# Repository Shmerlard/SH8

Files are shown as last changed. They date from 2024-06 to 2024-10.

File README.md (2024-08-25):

# The shmerlard 16

hi, my name is elad and Im an electrical engineering student in Ben gurion university.
I designed a small 16bit cpu, with a mix of jdh8, src, msp430 and the Hack computer.
this is still a work in progress, but so far it works.

I used logisim for the logic design, draw.io for the diagrams.
in order to see the working cpu in logisim: you need to build version `3.9.0` from source [here](https://github.com/logisim-evolution/logisim-evolution/blob/main/docs/developers.md), then just open the `.circ` file.

## Specs

- a common 16-bit data and address bus
- a total of 128kB of usable memory
- 6 GP register (up to 14 available)
- modular design for easy troubleshooting
- port for outside connections

## Contents

1) [Registers](/Wiki/Modules/Register-File.md)
2) [Instruction Register](/Wiki/Modules/Instruction-Register.md)
3) [Program Counter](/Wiki/Modules/Program-Counter.md)
4) [ALU](/Wiki/Modules/ALU.md)
5) [Control Unit](/Wiki/Modules/Control-Unit.md)
6) [Memory Registers](/Wiki/Modules/Memory-Registers.md)
7) [Condition Logic](/Wiki/Modules/Condition-Logic.md)
8) [Shift Control](/Wiki/Modules/Shift-Control.md)
9) [Gallery](/Wiki/Gallery.md)

## Instruction set

```text
0x00:  NOP
0x01:  MOV  Ra/#, Rb       | Ra/# -> Rb
0x02:  ST   Ra/#, Rb/#     | Ra/# -> M[Rb]/
0x03:  PUSH Ra/#           | Ra/# -> @SP; SP--
0x04:  POP  Ra             | SP++; @SP -> Ra
0x05:  ADD  Ra/#, Rb       | Ra/# + Rb -> Rb
0x06:  ADDC Ra/#, Rb       | Ra/# + Rb + c -> Rb
0x07:  SUB  Ra/#, Rb       | Rb - Ra/# -> Rb
0x08:  CMP  Ra/#, Rb       | Rb - Ra/#
0x09:  SHR  Ra/#, Rb       | SHR Rb (Ra/# times) -> Rb
0x0A:  SHL
0x0B:  RRC  Ra/#, Rb       | RRC Rb (Ra/# times) -> Rb
0x0C:  RLC
0x0D:  AND  Ra/#, Rb       | Ra/# AND Rb -> Rb
0x0E:  OR   Ra/#, Rb       | Ra/# OR  Rb -> Rb
0x0F:  XOR  Ra/#, Rb       | Ra/# XOR Rb -> Rb
0x10:  NOT
0x11:  CALL DST            | PC -> @SP; DST -> PC; SP-- -> SP;
0x12:  RET
0x13:  JMP  DST            | DST -> PC
```

for more simulated instructions see: [Simulated Instructions](/Wiki/Simulated-Instructions.md)

## [Registers](/Wiki/Modules/Register-File.md)

```text
0: SP/REG0  : STACK pointer    
1: SR/REG1  : Status register
2: REG2     : GP Input
3: REG3     : GP Output
4: REG3     : GP
5: REG4     : GP
6: REG5     : GP
7: REG6     : GP
```

## [Memory](/Wiki/Modules/Memory-Registers.md)

the memory ranges from `0x0000` to `0xFFFF`.
the memory is mapped in the following way:

```text
0x0000 - 0x7FFF: GP ROM              (32KiB    ROM)
0x8000 - 0xBFFF: GP RAM              (16KiB    RAM) 
0xC000 - 0xCFFF: VRAM                (4KiB    RAM) #CURRENTLY NOT IN USE#
0xD000 - 0xFFFF: NOT IN USE          (12KiB UNUSED)
```

## [Instruction format](./Wiki/Modules/Instruction-Register.md)

The instruction register is a 16-bit register

```text
the format is XXXX-XUMM-SSSS-DDDD
X = the opcode of the instruction
U = Currently not in use
M = indicates the addressing mode
S = indicates the source register
D = indicates the destination register
```

(see [addressing modes](/Wiki/Modules/Instruction-Register.md#addressing-modes)) for more info

## Full diagram

for the full gallery go to [Gallery](Wiki/Gallery.md)

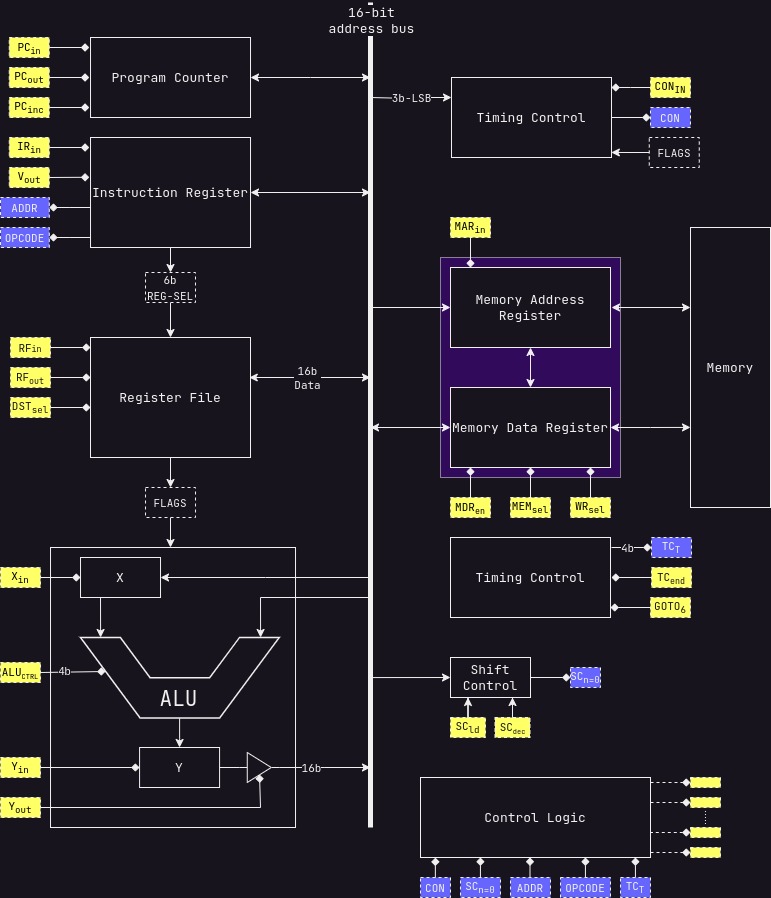
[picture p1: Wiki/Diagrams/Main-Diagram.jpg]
text


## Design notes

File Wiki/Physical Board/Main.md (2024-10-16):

## The Physical Board

I used KiCad to design the schematics and PCB's

The whole CPU is divided into the following modules and boards:

1. The Register File Module (16):\
    a. GP Registers (14)\
    b. Status Register (1)\
    c. Register File Manger (1)

2. Managing Modules (5):\
    a. the IR board (1)\
    b. the PC board (1)\
    c. the CON board (1)\
    d. the SC board (1)\
    e. the TC board (1)

3. ALU module (6):\
    a. X,Y register boards (2)\
    b. ALU Main(1)\
    c. ALU Shifter(1)\
    d. ALU Flags Calculator(1)\
    e. ALU Extra(1)

4. MEM and Control logic (3):\
    a. RAM and ROM board (1)
    b. MAR MDR (1))\
    c. Control board (1)

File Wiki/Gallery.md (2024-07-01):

# Gallery

## Main view

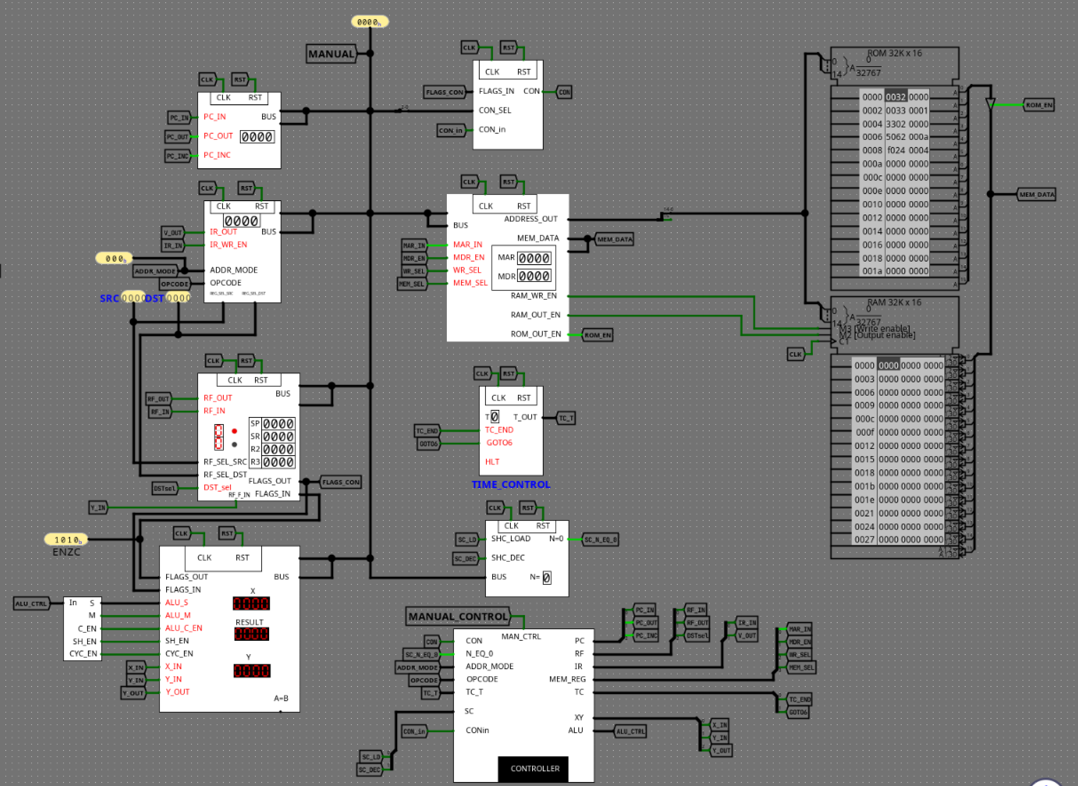
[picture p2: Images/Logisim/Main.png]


## The register file

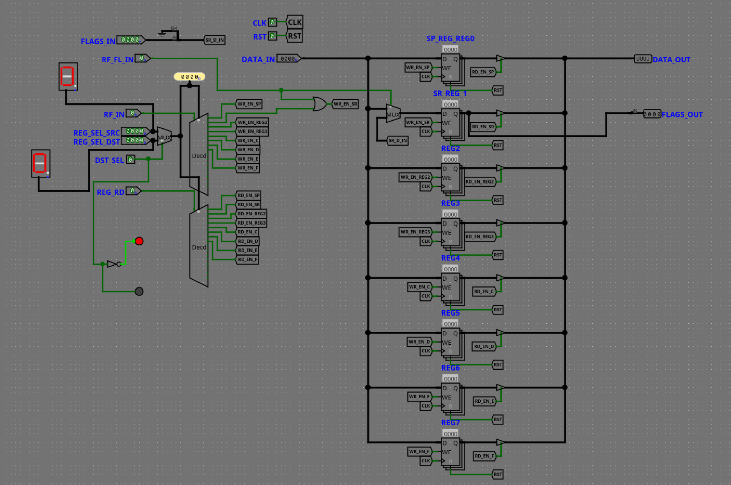
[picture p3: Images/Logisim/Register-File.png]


## The program counter

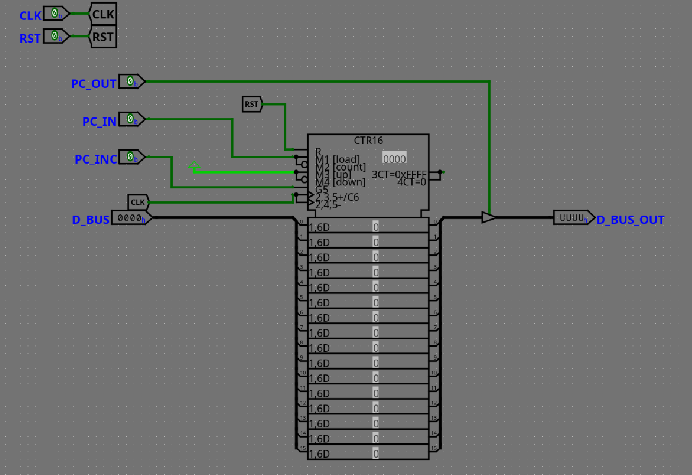
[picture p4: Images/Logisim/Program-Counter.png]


## The instruction register

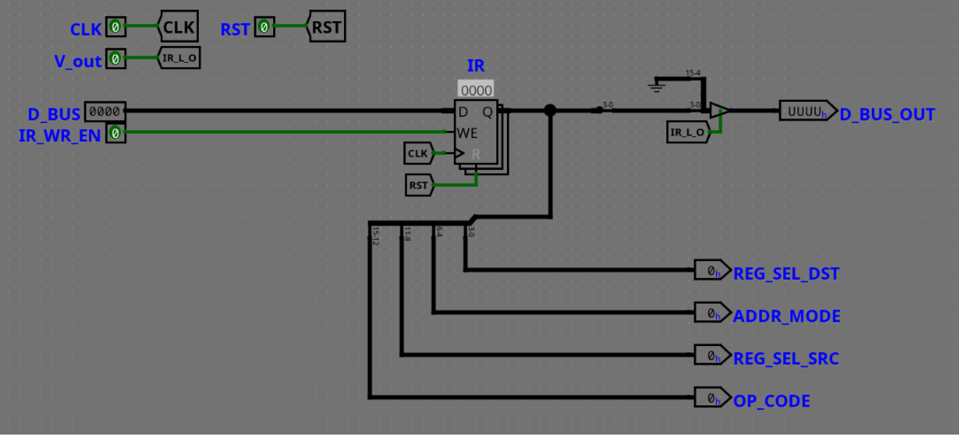
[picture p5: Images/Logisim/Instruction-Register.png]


## The ALU

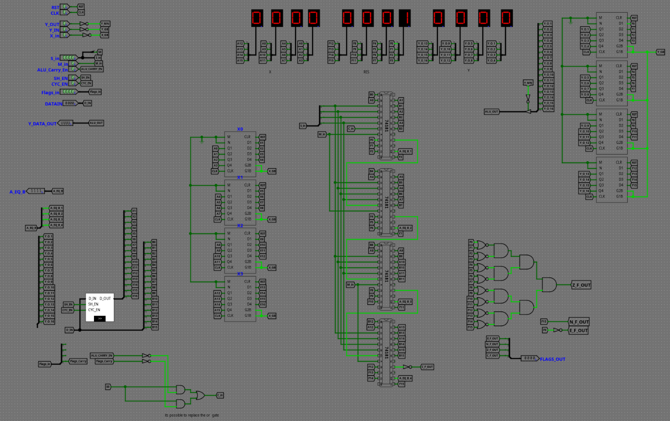
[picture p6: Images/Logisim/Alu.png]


## The conddition control

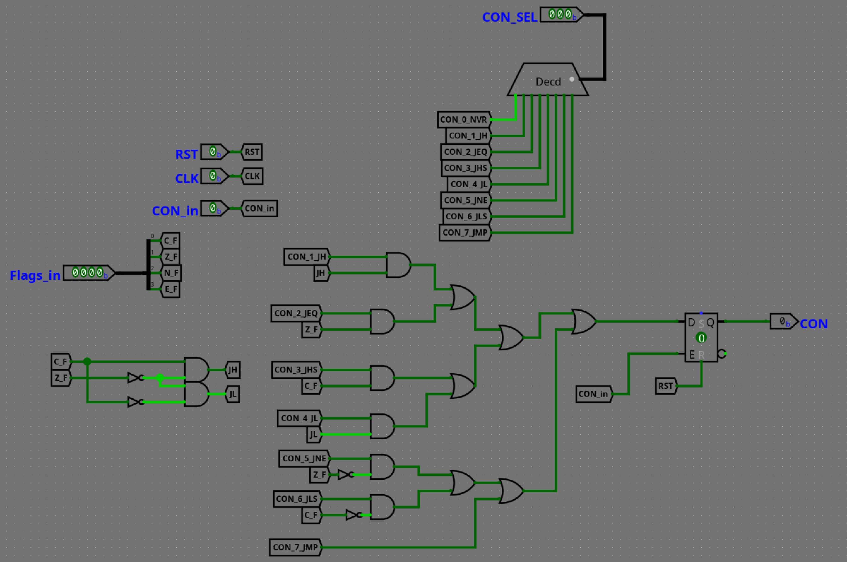
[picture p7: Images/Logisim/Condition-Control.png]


## Control logic

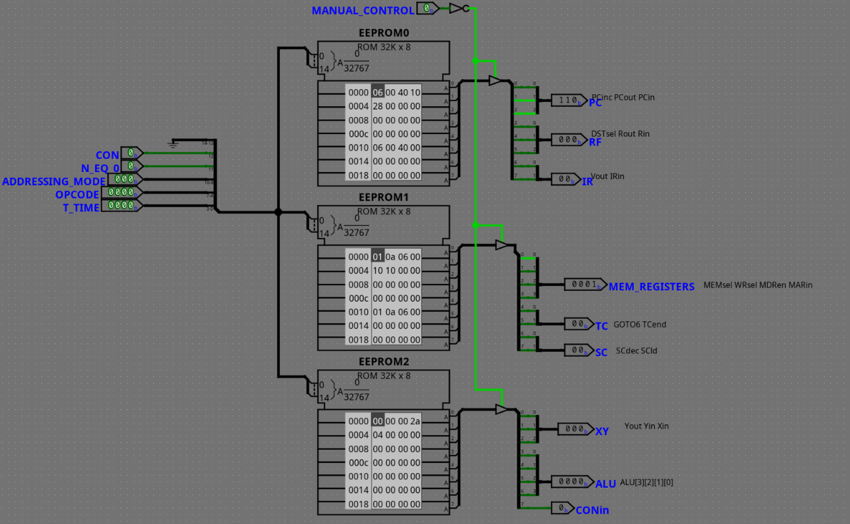
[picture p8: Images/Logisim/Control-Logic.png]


## Memory registers

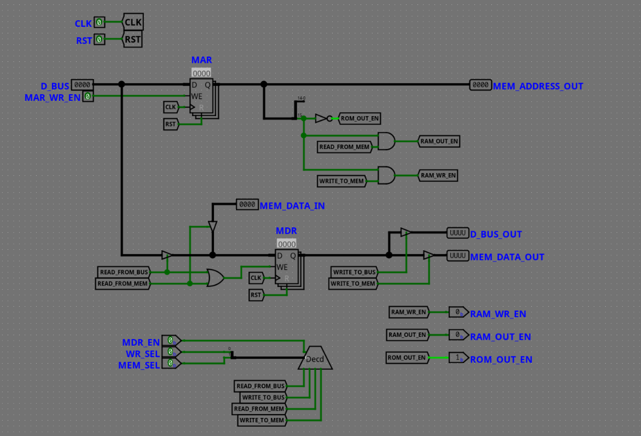
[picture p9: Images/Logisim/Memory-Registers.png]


## Shift control

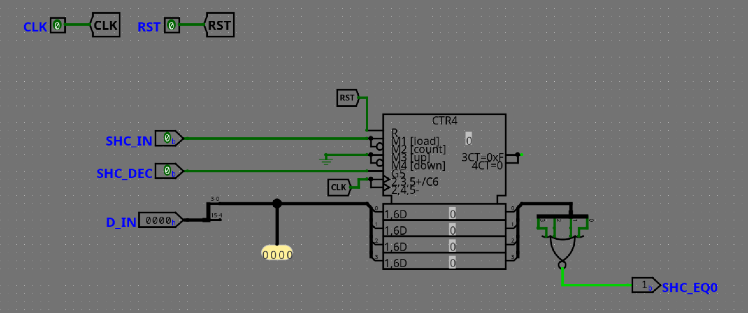
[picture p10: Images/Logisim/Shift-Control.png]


## Timing control

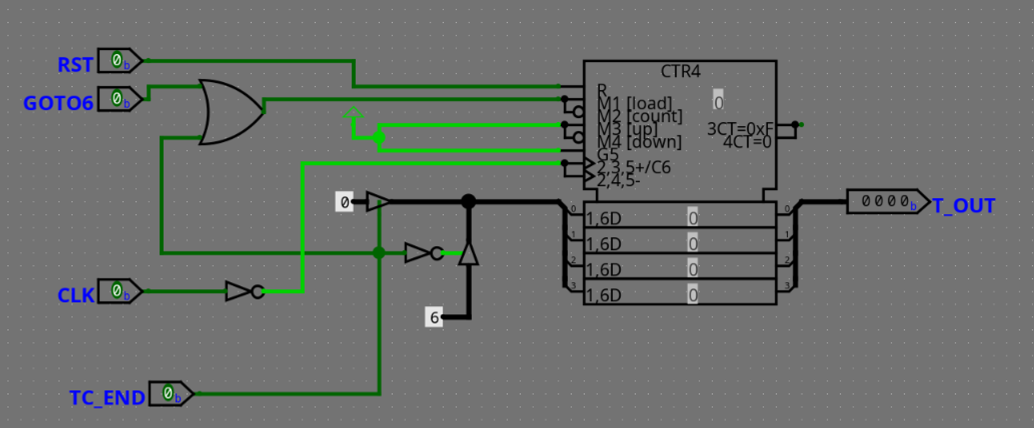
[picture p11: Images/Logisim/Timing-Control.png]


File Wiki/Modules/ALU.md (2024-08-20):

# The ALU

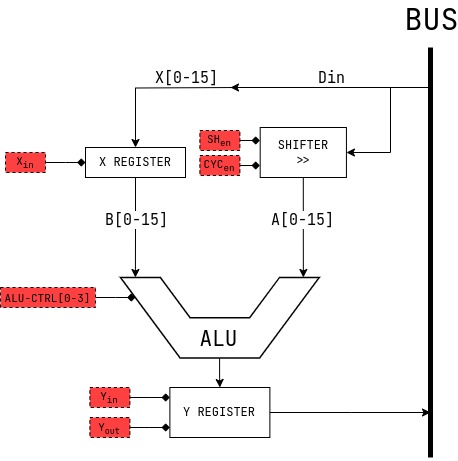
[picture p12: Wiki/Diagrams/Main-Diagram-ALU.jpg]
text

The ALU is the unit performing arithmetic and logical operations.
the ALU also contains 2 registers, X and Y. X is for the input, Y is for the output.
i used 4 74ls181 chips for the alu, but since the chip doesnt have a shifting mechanic another one is used.
in

since the 74ls181 chip has 6 inputs, and the shifter has another 2, we will need a full eeprom just for the mode of operation of the alu (even without `Xin Yin You`), but we don't need every possible output of the alu so first I've listed function that we are going to need.
and second I've listed the required control lines.
since we have less then 16 possible functions, we can represent them in 4 bits.
I've used to combinatorical analysis function in Logisim to find a matching circuit to "Translate" between the input that will be called `ALU_CTRL` and the control lines that will control the 74181 chips.
this circuit can be built in real life either by individuals logic gates or by an eeprom.

the alu has the folowing control lines:

```text
0x0: ADD
0x1: ADDC
0x2: SUB
0x3: AND
0x4: OR
0x5: XOR
0x6: NOT
0x7: Y=A
0x8: Y=X
0x9: SHR
0xA: RRC
0xB: SHL
0xC: RLC
0xD: DECA
0xE: INCA
0xF:
```

according to the [datasheet](/Datasheets/74181.pdf) we are going to need the following:

```text
0x0: ADD : F = A PLUS  B        : S = 0x9; M = 0; SH_EN = 0; CARRY_EN = 0
0x1: ADDC: F = A PLUS  B PLUS C : S = 0x9; M = 0; SH_EN = 0; CARRY_EN = 1
0x2: SUB : F = A MINUS B        : S = 0x6; M = 0; SH_EN = 0; CARRY_EN = 0
0x3: AND : F = A AND B          : S = 0xB; M = 1; SH_EN = 0;
0x4: OR  : F = A OR  B          : S = 0xE; M = 1; SH_EN = 0;
0x5: XOR : F = A XOR B          : S = 0x6; M = 1; SH_EN = 0;
0x6: NOT : F = NOT A            : S = 0x0; M = 1; SH_EN = 0;
0x7: Y=A : F = A                : S = 0xF; M = 1; SH_EN = 0;
0x8: Y=X : F = B                : S = 0xA; M = 1; SH_EN = 0;
0x9: SHR : Shift right A        : S = 0xF; M = 1; SH_EN = 1; CYC_EN = 0; LFT_SEL = 0
0xA: RRC : Shift right cyclic A : S = 0xF; M = 1; SH_EN = 1; CYC_EN = 1; LFT_SEL = 0
0xB: SHR : Shift left A         : S = 0xF; M = 1; SH_EN = 1; CYC_EN = 0; LFT_SEL = 1
0xC: RRC : Shift left cyclic A  : S = 0xF; M = 1; SH_EN = 1; CYC_EN = 1; LFT_SEL = 1
0xD: Y=DECA:                    : S = 0xF; M = 0; SH_EN = 0; CARRY_EN = 0
0xE: Y=INCA:                    : S = 0x0; M = 0; SH_EN = 0; CARRY_EN = 0 
```

## the shifting mechanic

since the 74181 chip doesnt include a shift right option, another circuit is made to do this, the circuit is connected between the bus and the A input of the alu and has 2 control lines, one is `SH_EN` for enabling shifting and the other is `CYC_EN` for enabling rotation, so if I want to shift left register 5 all I have to do is:
1) output register 5 to the bus
2) enable `SH_EN` and `Y=A` 
3) enable `Yin` for to save the resault
4) output Y register to `R5`

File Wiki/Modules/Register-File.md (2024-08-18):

# The register File

the register file contains the following registers:
```
0   : SP        | The stack pointer is a 16-bit register for
                  Holding the current address of the stack.

1   : SR REG    | Status register contains the following from LSB to MSB
                  0: (C) Carry flag
                  1: (Z) Zero flag
                  2: (N) Negative flag
                  3: (E) Even flag

2-3 : INPUT OUTPUT REGISTERS

4-15: GP Registers
```

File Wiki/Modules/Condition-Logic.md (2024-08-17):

# The condition logic

the condition logic control wheter the condition is satisfied or not:
the condition is a 3bit value.
the condition value is stored in the IR and the assembler will check which jump instruction is written and then insert the matching command.
for instance `JMP @R5` will be translated as `F517`, 
`F` is for `JMP` instruction, 
`5` is for `R5`, 
`1` is for `@Ra` addressing mode, 
and `7` is for always jump.
the instruction `JEQ @R5` will be translated to `F512`, everything will be the same exept that now we want to jump if equal.

```text
the condition format is XYZ
X - if 1: <
Y - if 1: =
Z - if 1: >
```

```text
0b000:     - dont jump              # a better solution need to be implemented
0b001: JH  - jump if higher
0b010: JEQ - jump if equal
0b011: JHS - jump if higher or same
0b100: JL  - jump if lower
0b101: JNE - jump if not equal
0b110: JLS - jump if lower or same
0b111: JMP - always jump
```

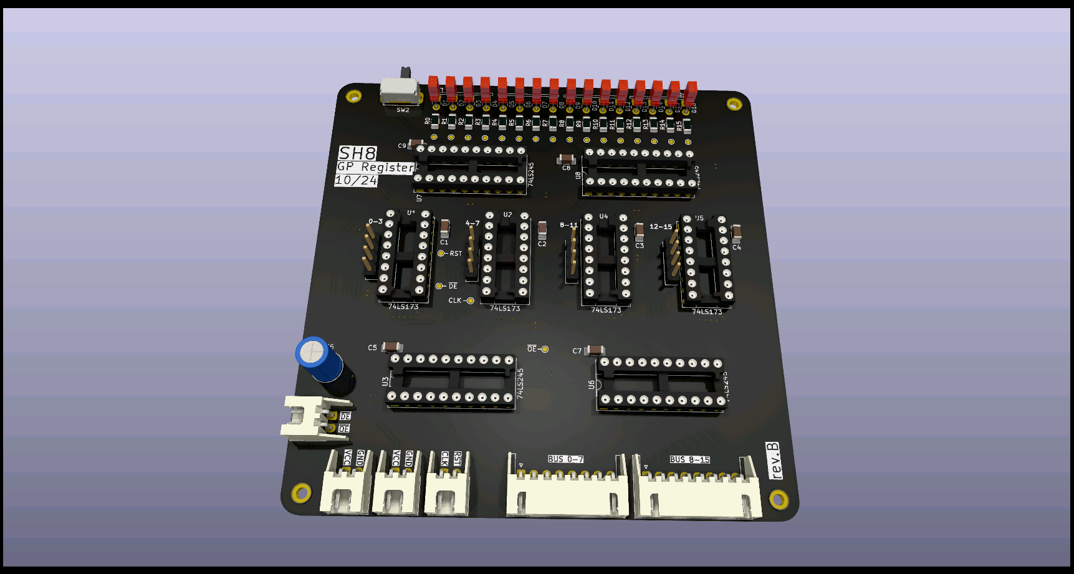
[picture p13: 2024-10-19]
Images/Kicad/GP_Register_rev_B.png

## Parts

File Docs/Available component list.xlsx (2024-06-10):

logisim? | verified? | Amount | 74XX | Description | Datasheet
 |  | 10 | 7400 | quad 2-input NAND gate | https://www.ti.com/lit/gpn/sn74ls00
 |  | 10 | 7402 | quad 2-input NOR gate | https://www.ti.com/lit/gpn/sn74ls02
 |  | 30 | 7404 | hex inverter gate | https://www.ti.com/lit/gpn/sn74ls04
 |  | 20 | 7408 | quad 2-input AND gate | https://www.ti.com/lit/gpn/sn74ls08
 |  | 20 | 7432 | quad 2-input OR gate | https://www.ti.com/lit/gpn/sn74ls32
 |  | 10 | 7486 | quad 2-input XOR gate | https://www.ti.com/lit/gpn/sn74ls86a
 |  | 5 | 74107 | dual J-K flip-flop, clear | https://www.ti.com/lit/gpn/sn74ls107a
 |  | 10 | 74138 | 3-to-8 line decoder/demultiplexer, inverting outputs | https://www.ti.com/lit/gpn/sn74ls138
 |  | 10 | 74139 | dual 2-to-4 line decoder/demultiplexer, inverting outputs | https://www.ti.com/lit/gpn/sn74ls139a
 |  | 20 | 74157 | quad 2-line to 1-line data selector/multiplexer, non-inverting outputs | https://www.ti.com/lit/gpn/sn74ls157
 |  | 10 | 74161 | synchronous presettable 4-bit binary counter, asynchronous clear | https://www.ti.com/lit/gpn/sn74ls161a
 |  | 15 | 74173 | quad D flip-flop, asynchronous clear | https://www.ti.com/lit/gpn/sn74ls173a
 |  | 3 | 74181 | 4-bit arithmetic logic unit and function generator | https://www.ti.com/lit/gpn/sn54ls181
 |  | 5 | 74189 | 64-bit RAM (16x4), 4 data inputs, 4 inverted data outputs | https://archive.org/details/bitsavers_tidataBookcomputerComponentsDataBook_16851665/page/n191
 |  | 2024-10-05 | 74244 | Octal Buffers and Line Drivers With 3-State Outputs | https://www.ti.com/lit/gpn/sn74ls244
 |  | 20 | 74245 | octal bus transceiver, non-inverting outputs | https://www.ti.com/lit/gpn/sn74ls245
 |  | 10 | 74273 | 8-bit register, asynchronous clear | https://www.ti.com/lit/gpn/sn74ls273
 |  | 20 | 74283 | 4-bit binary full adder (has carry in function) | https://www.ti.com/lit/gpn/sn74ls283
 |  | 10 | 74573 | Octal Transparent D-type latches with 3-states outputs | https://www.ti.com/lit/ds/symlink/sn74f573.pdf?ts=1718054679980
 |  | 10 | HM62256ALP10 | 8-bit High Speed CMOS Static RAM | https://pdf1.alldatasheet.com/datasheet-pdf/view/77267/HITACHI/HM62256ALP-10.html
 |  | 10 | NE555 | 555timer
 |  | 2 | CAT28C16 | 16 kb CMOS Parallel EEPROM | https://www.tme.com/Document/5c9d456a1546b7ee99bcccff240d871e/CAT28C16AX20.pdf

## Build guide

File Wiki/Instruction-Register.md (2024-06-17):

# The instruction register

## Instruction format

The instruction register is a 16-bit register

```text
the format is XXXX-XAAA-SSSS-DDDD
X = the opcode of the instruction
A = indicates the addressing mode 
S = indicates the source register
D = indicates the destination register
```

## Addressing modes

```text
000: Ra  Rb  | Reg - Reg Addressing            | Ra -> Rb
001: Ra  @Rb | Reg - Indirect Addressing       | R[Ra] -> M[Rb]
010: @Ra Rb  | Indirect - Reg Addressing       | M[Ra] -> Rb
011: @Rb @Rb | Indirect - Inderect Addressing  | M[Ra] -> M[Rb]
100: #N  Rb  | Immediate - Register Addressing | N -> Rb
101: #N  @Rb | Immediate - Indirect Addressing | N -> M[Rb]
110: N   Rb  | Direct - Register Addressing    | M[N] -> Rb
111: Ra  N   | Register - Direct Addressing    | Ra -> M[N]
```

### how fetching is obtained?

```text
T0) PC    -> MAR; PC++  | PCout, MARin, PCinc
T1) M[MA] -> MD         | MDRen, MEMsel, 
T2) MD    -> IR         | MDRen, IRin WRsel
```

### RTN

```text
(Rx)  Refers to the data inside register x
(M[Rx]) Refers to the data at the with the address Rx

(A ->  B) A is moving to B
(A &   B) A bitwise AND B
(A ||  B) A bitwise OR B
(NOT A  ) A bitwise NOT
(A XOR B) A bitwise XOR B
(A >>  B) A is shifted right bitwise B times (MSB of A becomes 0 each shift)
(A <<  B) A is shifted left bitwise B times (LSB of A becomes 0 each shift)
(A RR  B) A is rotated right B times
(A RL  B) A is rotated left B times

```

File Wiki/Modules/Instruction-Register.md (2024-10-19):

# The instruction register

The instruction register is a 16-bit register

## Instruction format

there is only one type of instruction formats
```text
the format is XXXX-XUMM-SSSS-DDDD
X = the opcode of the instruction
U = Currently not in use
M = indicates the addressing mode
S = indicates the source register
D = indicates the destination register
```

## Addressing modes

each addressing mode is represented by 2 bits for a total of 4 adressing modes for each type
there are 4 types of addressing modes

### Type 0 addressing mod
this type is used by `NOP`, `HLT`, `RET`
they dont have any arguements

### Type 1 addressing mod
this type is used by `MOV`,`AND`,`OR`,`XOR`,`SHR`,`RRC`, `ADD`,`ADDC`, `SUB` and `CMP`.

```text
0x0: Ra  Rb             | MOV Ra  Rb: Ra    -> Rb
0x1: @Ra Rb             | MOV @Ra Rb: M[Ra] -> Rb
0x2: #N  Rb             | MOV #N  Rb: #N    -> Rb
0x3: N   Rb             | MOV N   Rb: M[N]  -> Rb
```

### Type 2 addressing mods
this type is used by `ST`

```text
0x0: Ra  @Rb            | ST Ra @Rb: Ra -> M[Rb]
0x1: Ra  #N             | ST Ra #N: Ra -> M[#N]
0x2: #N  @Rb            | ST #N @Rb: #N -> M[M[Rb]]
0x3: Ra  N              | ST Ra N: Ra -> M[M[#N]]
```

### Type 3 addressing mods
this type is used by `PUSH`,`POP`,`CALL` and `JMP`

```text
0x0: Ra                 | POP Ra: @SP -> Ra
0x1: @Ra                | POP @Ra: @SP -> @Ra
0x2: #N                 | POP #N: @SP -> M[#N]
0x3: N                  | PUSH N: M[M[#N]] -> @SP
```
^note 1: in the examples above there are also `SP++` steps which I didnt include here.

### how fetching is obtained?

```text
T0) PC     -> MAR; PC++  | PCout, MARin, PCinc
T1) M[MAR] -> MDR        | MDRen, MEMsel, 
T2) MDR    -> IR         | MDRen, IRin WRsel
```

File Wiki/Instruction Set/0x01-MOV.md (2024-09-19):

# MOV

```text
0x0: Ra Rb: Ra -> Rb
    3) Ra -> Y              | RFout Yin Y=B
    4) Y  -> Rb             | RFin DSTsel Yout
    5) END                  | TCend

0x1: @Ra Rb: M[Ra] -> Rb
    3) Ra -> MAR            | RFout MARin
    4) M[MAR] -> MD         | MDRen MEMsel
    5) MDR -> Rb            | RFin DSTsel MDRen WRsel
    6) END                  | TCend

0x2: #N Rb: #N -> Rb
    3) PC -> MAR; PC++      | PCout  MARin PCinc
    4) M[MAR] -> MDR        | MEMsel MDRen
    5) MDR -> Rb            | RFin   RFin  DSTsel MDRen WRsel
    6) END                  | TCend

0x3: N @Rb: M[#N] Rb
    3) PC -> MAR; PC++      | PCout PCinc MARin
    4) M[MAR] -> MDR        | MDRen MEMsel
    5) MDR -> MAR           | MARin MDRen WRsel
    6) M[MAR] -> MDR        | MDRen MEMsel
    7) MDR -> Rb            | RFin DSTsel MDRen WRsel
    8) END                  | TCend

```

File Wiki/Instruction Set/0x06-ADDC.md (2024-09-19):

# ADDC

`ADDC` is a type 2 instruction that adds two numbers with carry

```text
0x0: Ra Rb: Ra + Rb + c -> Rb
    3) Ra -> X                  | RFout Xin
    4) X + Rb + c -> Y          | RFout DSTsel ADDC Yin
    5) Y -> Rb                  | RFin DSTsel Yout
    6) END                      | TCend

0x1: @Ra Rb: M[Ra] + Rb + c -> Rb
    3) Ra -> MAR                | RFout MARin
    4) Rb -> X; M[MAR] -> MDR   | RFout DSTsel Xin MDRen MEMsel
    5) X + MDR + c -> Y         | ADDC Yin MDRen WRsel
    6) Y -> Rb                  | RFin DSTsel Yout
    7) END                      | TCend

0x2: #N Rb: #N + Rb + c -> Rb
    3) PC -> MAR; PC++          | PCout PCinc MARin
    4) Rb -> X  ; M[MAR] -> MDR | RFout DSTsel Xin MDRen MEMsel
    5) MDR + X + c -> Y         | ADDC Yin MDRen WRsel
    6) Y -> Rb                  | Yout RFin DSTsel
    7) END                      | TCend

0x3: N Rb:
    3) 
```

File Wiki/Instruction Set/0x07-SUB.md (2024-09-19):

# SUB

```text
0x0: Ra Rb: Rb - Ra -> Rb
    3) Ra -> X                  | RFout Xin
    4) Rb - X -> Y              | RFout DSTsel SUB Yin
    5) Y -> Rb                  | RFin DSTsel Yout 
    6) END                      | TCend

0x1: @Ra Rb: Rb - M[Ra] -> Rb
    3) Ra -> MAR                | RFout MARin
    4) Rb -> X; M[MAR] -> MDR   | RFout DSTsel Xin MDRen MEMsel
    5) X - MDR -> Y             | SUB Yin MDRen WRsel 
    6) Y -> Rb                  | RFin DSTsel Yout
    7) END                      | TCend

0x2: #N Rb: Rb - #N -> Rb
    3) PC -> MAR; PC++          | PCout PCinc MARin
    4) M[MAR] -> MDR            | MDRen MEMsel
    5) MDR -> X                 | MDRen WRsel
    6) Rb - X -> Y              | RFout DSTsel SUB Yin
    7) Y -> Rb                  | RFin DSTsel Yout
    8) END                      | TCend

0x4: N Rb:
    3) 
```

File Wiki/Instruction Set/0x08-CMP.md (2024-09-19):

# CMP
Basically its like `SUB` only that `Rb` is not updated after

```text
0x0: Ra Rb: Rb - Ra
    3) Ra -> X                  | RFout Xin
    4) Rb - X -> Y              | RFout DSTsel SUB Yin
    5) END                      | TCend

0x1: @Ra Rb: Rb - M[Ra]
    3) Ra -> MAR                | RFout MARin
    4) Rb -> X; M[MAR] -> MDR   | RFout DSTsel Xin MDRen MEMsel
    5) X - MDR -> Y             | SUB Yin MDRen WRsel 
    6) END                      | TCend

0x2: #N Rb: Rb - #N
    3) PC -> MAR; PC++          | PCout PCinc MARin
    4) M[MAR] -> MDR            | MDRen MEMsel
    5) MDR -> X                 | MDRen WRsel
    6) Rb - X -> Y              | SUB Yin
    7) END                      | TCend

0x4: N Rb:
    3) 
```

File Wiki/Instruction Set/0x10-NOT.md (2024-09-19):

# NOT

```text
0x0: Ra Rb: ¬Ra -> Rb
    3) ¬Ra -> Y         | RFout NOT Yin
    4) Y -> Rb          | RFin DSTsel Yout
    5) END              | TCend

0x1: @Ra Rb: ¬M[Ra] -> Rb
    3) Ra -> MAR        | RFout MARin
    4) M[MAR] -> MDR    | MDRen MEMsel
    5) ¬MDR -> Y        | NOT Yin MDRen WRsel
    6) Y -> Rb          | RFin DSTsel Yout

0x2: #N Rb: ¬#N -> Rb
    3) PC -> MAR; PC++  | PCout PCinc MARin
    4) M[MAR] -> MDR    | MDRen MEMsel
    5) ¬MDR -> Y        | NOT Yin MDRen WRsel
    6) Y -> Rb          | RFin DSTsel Yout
    7) END              | TCend

0x3: N Rb:
    3)
```

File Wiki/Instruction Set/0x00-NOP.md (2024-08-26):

# NOP

```text
0x0: NOP
    3) TCend
```

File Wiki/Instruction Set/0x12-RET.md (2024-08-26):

# RET
the SP (reg#0) is selected to be `SRC` register

```text
0x0: RET: SP++; @SP -> PC
    3) SP++ -> Y                | RFout INCA Yin
    4) Y -> MAR : Y -> SP       | RFin Yout MARin
    5) M[MAR] -> MDR            | MDRen MEMsel
    6) MDR -> PC                | PCin MDRen WRsel
    7) END                      | TCend

0x1: NOP
    3) END                      | TCend

0x2: NOP
    3) END                      | TCend

0x3: NOP
    3) END                      | TCend
```

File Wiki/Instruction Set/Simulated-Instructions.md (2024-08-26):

# Simulated instructions

```text
HLT -> OR #0x0010 SR

Set Stack Pointer
SSP #N -> MOV #N SP

CLEAR E/N/Z/C bit
CLRC -> XOR #0x0001 SR
CLRZ -> XOR #0x0002 SR
CLRN -> XOR #0x0003 SR
CLRE -> XOR #0x0004 SR

SET E/N/Z/C bit
SETC -> OR #0x0001 SR
SETZ -> OR #0x0002 SR
SETN -> OR #0x0003 SR
SETE -> OR #0x0004 SR
```

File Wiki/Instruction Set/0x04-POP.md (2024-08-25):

# POP

in this command the SP (reg#0) is selected to be src reg

```text
0x0: Ra: SP++; @SP -> Ra
    3) SP++ -> Y                | RFout INCA Yin
    4) Y -> MAR : Y -> SP       | RFin Yout MARin
    5) M[MAR] -> MDR            | MDRen MEMsel
    6) MDR -> Ra                | RFin DSTsel MDRen WRsel
    7) END                      | TCend

0x1: @Ra: SP++; @SP -> @Ra
    3) SP++ -> Y                | RFout Yin INCA
    4) Y -> MAR: Y -> SP        | RFin Yout MARin
    5) M[MAR] -> MDR            | MDRen MEMsel
    6) Ra -> MAR                | RFout DSTsel MARin
    7) MDR -> M[MAR]            | MDRen WRsel MEMsel
    8) END                      | TCend

0x2: #N: SP++; @SP -> M[#N]
    3) SP++ -> Y                | RFout Yin INCA
    4) Y -> MAR: Y -> SP        | RFin Yout MARin
    5) M[MAR] -> MDR            | MDRen MEMsel
    6) MDR -> Y                 | Yin Y=A MDRen WRsel
    7) PC -> MAR; PC++          | PCout PCinc MARin
    8) M[MAR] -> MDR            | MDRen MEMsel
    9) MDR -> MAR               | MARin MDRen WRsel
   10) Y -> MDR                 | Yout MDRen
   11) MDR -> M[MAR]            | MDRen MEMsel WRsel
   12) END                      | TCend

0x3: N: SP++; @SP -> M[M[N]]
    3) END                      | TCend
```

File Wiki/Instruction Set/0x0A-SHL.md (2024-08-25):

# SHL

```text
0x0: Ra Rb: Rb (Shifted R[Ra]<3...0> times) -> Rb
    3) Ra -> n                                  | RFout SCld
    4) Rb -> Y                                  | RFout DSTsel Y=A Yin
    5) NOP                                      | NOP 
    6) (n != 0): Y SHL -> Y; n--                | SHL Yout Yin SCdec GOTO6
       (n  = 0): Y -> Rb                        | Yout RFin DSTsel
    7) END                                      | TCend

0x1: @Ra Rb:
    3) 

0x2: #N Rb: Rb (Shifted #N times) -> Rb
    3) PC -> MAR; PC++                          | PCout MARin PCinc
    4) M[MAR] -> MD; Rb -> Y                    | RFout DSTsel Y=A Yin MDRen MEMsel
    5) MD -> n                                  | MDRen WRsel SCld
    6) (n != 0): Y SHL -> Y; n--                | Yout Yin SHL SCdec GOTO6
       (n  = 0): Y -> Rb                        | RFin DSTsel Yout
    7) END                                      | TCend

0x3: N, @Rb:
    3) 
```

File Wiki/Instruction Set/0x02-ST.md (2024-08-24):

# ST

```text
0x0: Ra @Rb: Ra -> M[Rb]
    3) Rb -> MAR            | RFout DSTsel MARin
    4) Ra -> MDR            | RFout MDRen
    5) MDR -> M[MAR]        | MDRen WRsel MEMsel
    6) END                  | TCend

0x1: Ra #N: Ra -> M[#N]
    3) PC -> MAR; PC++      | PCout PCinc MARin
    4) M[MAR] -> MDR        | MDRen MEMsel
    5) MDR -> MAR           | MARin MDRen WRsel
    6) Ra -> MDR            | RFout MDRenk
    7) MDR -> M[MAR]        | MDRen WRsel MEMsel
    8) END                  | TCend

0x2: #N @Rb: #N -> M[Rb]
    3) PC -> MAR; PC++      | PCout PCinc MARin
    4) M[MAR] -> MDR        | MDRen MEMsel
    5) Rb -> MAR            | RFout DSTsel MARin
    6) MDR -> M[MAR]        | MDRen WRsel MEMsel
    7) END                  | TCend

0x3: Ra N: Ra -> M[M[#N]]
    3) PC -> MAR; PC++      | PCout PCinc MARin
    4) M[MAR] -> MDR        | MDRen MEMsel
    5) MDR -> MAR           | MARin MDRen WRsel
    6) M[MAR] -> MDR        | MDRen MEMsel
    7) MDR -> MAR           | MARin MDRen WRsel
    8) Ra -> MDR            | RFout MDRen
    9) MDR -> M[MAR]        | MDRen WRsel MEMsel
   10) END                  | TCend

```

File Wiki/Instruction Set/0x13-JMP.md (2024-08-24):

# JMP

note: this include every possible jump: JEQ/JNE/JL/JLS/JH/JHS/JMP
see more: [Condition Logic](../Modules/Condition-Logic.md)
the register A is set to be the source register by the assembler

```text
0x0: Ra: if(CON): Ra -> PC
    3) Val -> CON                   | Vout CONin
    4) (CON = 1): Ra -> PC          | RFout PCin
       (CON = 0): NOP               | NOP
    5) END                          | TCend

0x1: @Ra: if(CON): M[Ra] -> PC
    3) 

0x2: #N: if(CON): #N -> PC
    3) PC -> MAR; PC++              | PCout PCinc MARin
    4) M[MAR] -> MDR ;Val -> CON    | Vout CONin MDRen MEMsel
    5) (CON = 1): MDR -> PC         | MDRen WRsel PCin
       (CON = 0): NOP               |
    6) END                          | TCend

0x3: N: if(CON) M[N] -> PC ##MIGHT BE USELESS
    3)
```

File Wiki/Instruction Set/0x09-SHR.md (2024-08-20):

# SHR

```text
0x0: Ra Rb: Rb (Shifted R[Ra]<3...0> times) -> Rb
    3) Ra -> n                                  | RFout SCld
    4) Rb -> Y                                  | RFout DSTsel Y=A Yin
    5) NOP                                      | NOP 
    6) (n != 0 AND ALT = 0): Y SHR -> Y; n--    | SHR Yout Yin SCdec GOTO6
       (n != 0 AND ALT = 1): Y SHL -> Y; n--    | SHL Yout Yin SCdec GOTO6
       (n  = 0): Y -> Rb                        | Yout RFin DSTsel
    7) END                                      | TCend

0x1: @Ra Rb:
    3) 

0x2: #N Rb: Rb (Shifted #N times) -> Rb
    3) PC -> MAR; PC++                          | PCout MARin PCinc
    4) M[MAR] -> MD; Rb -> Y                    | RFout DSTsel Y=A Yin MDRen MEMsel
    5) MD -> n                                  | MDRen WRsel SCld
    6) (n != 0 AND ALT = 0): Y SHR -> Y; n--    | Yout Yin SHR SCdec GOTO6
       (n != 0 AND ALT = 1): Y SHL -> Y; n--    | Yout Yin SHL SCdec GOTO6
       (n  = 0): Y -> Rb                        | RFin DSTsel Yout
    7) END                                      | TCend

0x3: N, @Rb:
    3) 
```

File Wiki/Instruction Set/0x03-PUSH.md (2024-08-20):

# PUSH

the SP(reg#0) is set to be the dst reg by the compiler
`PUSH` has a type 3 addressing mode

## The microcode
```text
0x0: Ra: Ra -> @SP; SP--
    3) SP -> MAR; SP-- -> Y     | RFout DSTsel DECA Yin MARin
    4) Ra -> MDR                | RFout MDRen
    5) MDR -> M[MAR]; Y -> SP   | RFin DSTsel Yout MDRen MEMsel WRsel
    6) END                      | TCend

0x1: @Ra: M[Ra] -> @SP; SP--
    3) Ra -> MAR                | RFout MARin
    4) M[MAR] -> MDR            | MDRen MEMsel
    5) SP -> MAR; SP-- -> Y     | RFout DSTsel Yin DECA MARin
    6) MDR -> M[MAR]            | MDRen WRsel MEMsel
    7) END                      | TCend

0x2: #N: #N -> @SP; SP--
    3) PC -> MAR; PC++          | PCout PCinc MARin
    4) M[MAR] -> MD             | MDRen MEMsel
    5) SP -> MAR; SP-- -> Y     | RFout DSTsel MARin DECA Yin
    6) MDR -> M[MAR]; Y -> SP   | RFin DSTsel Yout MDRen MEMsel WRsel
    7) END                      | TCend

0x3: N: M[#N] -> @SP; SP--
    3) PC -> MAR; PC++          | PCout PCinc MARin
    4) M[MAR] -> MDR            | MDRen MEMsel
    5) MDR -> MAR               | MARin MDRen WRsel
    6) M[MAR] -> MDR            | MDRen MEMsel
    7) SP -> MAR; SP-- -> Y     | RFout DSTsel MARin DECA Yin
    8) MDR -> M[MAR]; Y -> SP   | RFin DSTsel You MDRen MEMsel WRsel
    9) END                      | TCend
```

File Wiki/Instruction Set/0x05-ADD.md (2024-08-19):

# ADD

```text
0x0: Ra Rb: Ra + Rb -> Rb
    3) Ra -> X                  | Xin RFout
    4) X + Rb -> Y              | RFout DSTsel ADD Yin
    5) Y -> Rb                  | RFin DSTsel Yout
    6) END                      | TCend

0x1: @Ra Rb: M[Ra] + Rb -> Rb
    3) Ra -> MAR                | RFout MARin
    4) Rb -> X; M[MAR] -> MDR   | RFout DSTsel Xin MDRen MEMsel
    5) X + MDR -> Y             | ADD Yin MDRen WRsel
    6) Y -> Rb                  | Yout RFin DSTsel
    7) END                      | TCend

0x2: #N Rb: #N + Rb -> Rb
    3) PC -> MAR; PC++          | PCout PCinc MARin
    4) Rb -> X  ; M[MAR] -> MDR | RFout DSTsel Xin MDRen MEMsel
    5) MDR + X -> Y             | ADD Yin MDRen WRsel
    6) Y -> Rb                  | Yout RFin DSTsel
    7) END                      | TCend

0x3: N Rb: M[#N] + Rb -> Rb
    3) END                      | TCend

```

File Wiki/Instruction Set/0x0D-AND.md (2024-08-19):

# AND

```text
0x0: Ra Rb: Ra AND Rb -> Rb
    3) Ra -> X                  | RFout Xin
    4) X AND Rb -> Y            | RFout DSTsel AND Yin  
    5) Y -> Rb                  | RFin DSTsel Yout
    6) END                      | TCend

0x1: @Ra Rb: M[Ra] AND Rb -> Rb
    3) Ra -> MAR                | RFout MARin
    4) Rb -> X; M[MAR] -> MDR   | RFout DSTsel Xin MDRen MEMsel
    5) X AND MDR -> Y           | Yin AND MDRen WRsel
    6) Y -> Rb                  | RFin DSTsel Yout
    7) END                      | TCend

0x2: #N Rb: #N AND Rb -> Rb
    3) PC -> MAR; PC++          | PCout PCinc MARin
    4) Rb -> X; M[MAR] -> MDR   | RFout DSTsel Xin MDRen MEMsel
    5) X AND MDR -> Y           | Yin AND MDRen WRsel
    6) Y -> Rb                  | RFin DSTsel Yout
    7) END                      | TCend

0x3: N Rb: M[#N] AND Rb -> Rb
    3) PC -> MAR PC++           | PCout PCinc MARin
    4) Rb -> X; M[MAR] -> MDR   | RFout DSTsel Xin MDRen MEMsel
    5) MDR -> MAR               | MARin MDRen WRsel
    6) M[MAR] -> MDR            | MDRen MEMsel
    7) MDR AND X -> Y           | Yin AND MDRen WRsel
    8) Y -> Rb                  | RFin DSTsel Yout
    9) END                      | TCend
```

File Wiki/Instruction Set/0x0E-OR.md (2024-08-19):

# OR

```text
0x0: Ra Rb: Ra OR Rb -> Rb
    3) Ra -> X                  | RFout Xin
    4) X OR Rb -> Y             | RFout DSTsel OR Yin  
    5) Y -> Rb                  | RFin DSTsel Yout
    6) END                      | TCend

0x1: @Ra Rb: M[Ra] OR Rb -> Rb
    3) Ra -> MAR                | RFout MARin
    4) Rb -> X; M[MAR] -> MDR   | RFout DSTsel Xin MDRen MEMsel
    5) X OR MDR -> Y            | Yin OR MDRen WRsel
    6) Y -> Rb                  | RFin DSTsel Yout
    7) END                      | TCend

0x2: #N Rb: #N OR Rb -> Rb
    3) PC -> MAR; PC++          | PCout PCinc MARin
    4) Rb -> X; M[MAR] -> MDR   | RFout DSTsel Xin MDRen MEMsel
    5) X OR MDR -> Y            | Yin OR MDRen WRsel
    6) Y -> Rb                  | RFin DSTsel Yout
    7) END                      | TCend

0x3: N Rb: M[#N] OR Rb -> Rb
    3) PC -> MAR PC++           | PCout PCinc MARin
    4) Rb -> X; M[MAR] -> MDR   | RFout DSTsel Xin MDRen MEMsel
    5) MDR -> MAR               | MARin MDRen WRsel
    6) M[MAR] -> MDR            | MDRen MEMsel
    7) MDR OR X -> Y            | Yin OR MDRen WRsel
    8) Y -> Rb                  | RFin DSTsel Yout
    9) END                      | TCend
```

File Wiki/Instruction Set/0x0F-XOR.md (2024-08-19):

# XOR

```text
0x0: Ra Rb: Ra XOR Rb -> Rb
    3) Ra -> X                  | RFout Xin
    4) X XOR Rb -> Y            | RFout DSTsel XOR Yin  
    5) Y -> Rb                  | RFin DSTsel Yout
    6) END                      | TCend

0x1: @Ra Rb: M[Ra] XOR Rb -> Rb
    3) Ra -> MAR                | RFout MARin
    4) Rb -> X; M[MAR] -> MDR   | RFout DSTsel Xin MDRen MEMsel
    5) X XOR MDR -> Y           | Yin XOR MDRen WRsel
    6) Y -> Rb                  | RFin DSTsel Yout
    7) END                      | TCend

0x2: #N Rb: #N XOR Rb -> Rb
    3) PC -> MAR; PC++          | PCout PCinc MARin
    4) Rb -> X; M[MAR] -> MDR   | RFout DSTsel Xin MDRen MEMsel
    5) X XOR MDR -> Y           | Yin XOR MDRen WRsel
    6) Y -> Rb                  | RFin DSTsel Yout
    7) END                      | TCend

0x3: N Rb: M[#N] XOR Rb -> Rb
    3) PC -> MAR PC++           | PCout PCinc MARin
    4) Rb -> X; M[MAR] -> MDR   | RFout DSTsel Xin MDRen MEMsel
    5) MDR -> MAR               | MARin MDRen WRsel
    6) M[MAR] -> MDR            | MDRen MEMsel
    7) MDR XOR X -> Y           | Yin XOR MDRen WRsel
    8) Y -> Rb                  | RFin DSTsel Yout
    9) END                      | TCend
```

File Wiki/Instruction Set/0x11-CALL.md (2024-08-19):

# CALL

the `SP` is set to be the source register and `Ra` is set to be the destination register

```text
0x0: Ra: PC -> @SP; Ra -> PC; SP-- -> SP;
    3) PC -> MDR                | PCout MDRen
    4) SP -> MAR; SP-- -> Y     | RFout Yin DECA MARin
    5) MDR -> M[MAR]; Y -> SP   | RFin Yout MDRen MEMsel WRsel
    6) Ra -> PC                 | RFout DSTsel PCin
    7) END                      | TCend

0x1: @Ra: 
    3)

0x2: #N: PC -> @SP; #N -> PC; SP-- -> SP;
    3) PC -> MAR; PC++          | PCout PCinc MARin
    4) M[MAR] -> MDR            | MDRen MEMsel
    5) MDR -> Y                 | Yin Y=A MDRen WRsel
    6) PC -> MDR                | PCout MDRen
    7) Y -> PC                  | Yout PCin
    8) SP -> MAR; SP-- -> Y     | RFout MARin DECA Yin
    9) MDR -> M[MAR]; Y -> SP   | RFin Yout MDRen MEMsel WRsel
   10) END                      | TCend

0x3: N:
    3)
```

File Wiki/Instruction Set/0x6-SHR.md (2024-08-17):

# SHR

```text
0x0: Ra Rb: Rb (Shifted R[Ra]<3...0> times) -> Rb
    3) Ra -> n                      | RFout SCld
    4) Rb -> Y                      | RFout DSTsel Y=A Yin
    5) NOP                          | 
    6) (n != 0): Y SHR -> Y; n--    | SHR Yout Yin SCdec GOTO6
       (n  = 0): Y -> Rb            | Yout RFin DSTsel
    7) TCEND                        | TCend

0x1: Ra @Rb:
    3) 

0x2: @Ra Rb:
    3) 

0x3: #N Rb: Rb (Shifted #N times) -> Rb
    3) PC -> MAR; PC++              | PCout MARin PCinc
    4) M[MAR] -> MD; Rb -> Y        | RFout DSTsel Y=A Yin MDRen WRsel MEMsel
    5) MD -> n                      | MDRen SCld
    6) (n != 0): Y SHR -> Y; n--    | Yout Yin SHR SCdec GOTO6
       (n  = 0): Y -> Rb            | RFin DSTsel Yout
    7) TCend                        | TCend

0x4: #N, @Rb:
    3) 

0x5: N, Rb:
    3) 

0x6: Ra, N:
    3) 

0x7: SPECIAL
```

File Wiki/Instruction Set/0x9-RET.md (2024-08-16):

# RET

&&& note: i should change source of INC from X to bus

in this command `SP` is set to be the `SRC` register
```text
0x0: SP++ ; @SP -> PC 
    3) SP -> X              | RFout Xin
    4) X++ -> Y             | INCX Yin
    5) Y  -> SP, Y -> MAR   | Yout RFin MARin
    6) M[MAR] -> MDR        | MDRen MEMsel WRsel
    7) MDR -> PC            | MDRen PCin
```

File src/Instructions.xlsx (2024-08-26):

INST | OPCODE | CATEGORY | TYPE | SRC_REG | DST_REG | NUM_ARGS
NOP | 0x00 | REGULAR | 0 |  |  | 0
MOV | 0x01 | REGULAR | 1 |  |  | 2
ST | 0x02 | REGULAR | 2 |  |  | 2
PUSH | 0x03 | REGULAR | 3 |  | @0 | 1
POP | 0x04 | REGULAR | 3 | @0 |  | 1
ADD | 0x05 | REGULAR | 1 |  |  | 2
ADDC | 0x06 | REGULAR | 1 |  |  | 2
SUB | 0x07 | REGULAR | 1 |  |  | 2
CMP | 0x08 | REGULAR | 1 |  |  | 2
SHR | 0x09 | REGULAR | 1 |  |  | 2
SHL | 0x0A | REGULAR | 1 |  |  | 2
RRC | 0x0B | REGULAR | 1 |  |  | 2
RLC | 0x0C | REGULAR | 1 |  |  | 2
AND | 0x0D | REGULAR | 1 |  |  | 2
OR | 0x0E | REGULAR | 1 |  |  | 2
XOR | 0x0F | REGULAR | 1 |  |  | 2
NOT | 0x10 | REGULAR | 1 |  |  | 1
CALL | 0x11 | REGULAR | 3 | @0 |  | 1
RET | 0x12 | REGULAR | 0 | @0 | @0 | 0
JMP | 0x13 | REGULAR | 3 |  | 7 | 1
HLT | 0x14 | REGULAR | 0 |  | 1 | 0
dw |  | SAVED_WORD |  |  |  | 1
.org |  | SAVED_WORD |  |  |  | 1
JH | 0x0F | REGULAR | 3 |  | 1 | 1
JEQ | 0x0F | REGULAR | 3 |  | 2 | 1
JHS | 0x0F | REGULAR | 3 |  | 3 | 1
JL | 0x0F | REGULAR | 3 |  | 4 | 1
JNE | 0x0F | REGULAR | 3 |  | 5 | 1
JLS | 0x0F | REGULAR | 3 |  | 6 | 1
HLT | 0x0E | SIMULATED | 1 | #0x0010 | 1 | 0

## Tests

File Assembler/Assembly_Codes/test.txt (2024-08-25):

v3.0 hex words addressed
0000: 0a04 0124 0a05 0004 0a06 0015 0a09 0016 0825 0958 8b00 000e 9b07 000e 0a04 0003
0010: 9000 0000 0000 0000 0000 0000 0000 0000 0000 0000 0000 0000 0000 0000 0000 0000
0020: 0000 0000 0000 0000 0000 0000 0000 0000 0000 0000 0000 0000 0000 0000 0000 0000
0030: 0000 0000 0000 0000 0000 0000 0000 0000 0000 0000 0000 0000 0000 0000 0000 0000
0040: 0000 0000 0000 0000 0000 0000 0000 0000 0000 0000 0000 0000 0000 0000 0000 0000
0050: 0000 0000 0000 0000 0000 0000 0000 0000 0000 0000 0000 0000 0000 0000 0000 0000
0060: 0000 0000 0000 0000 0000 0000 0000 0000 0000 0000 0000 0000 0000 0000 0000 0000
0070: 0000 0000 0000 0000 0000 0000 0000 0000 0000 0000 0000 0000 0000 0000 0000 0000
0080: 0000 0000 0000 0000 0000 0000 0000 0000 0000 0000 0000 0000 0000 0000 0000 0000
0090: 0000 0000 0000 0000 0000 0000 0000 0000 0000 0000 0000 0000 0000 0000 0000 0000
00a0: 0000 0000 0000 0000 0000 0000 0000 0000 0000 0000 0000 0000 0000 0000 0000 0000
00b0: 0000 0000 0000 0000 0000 0000 0000 0000 0000 0000 0000 0000 0000 0000 0000 0000
00c0: 0000 0000 0000 0000 0000 0000 0000 0000 0000 0000 0000 0000 0000 0000 0000 0000
00d0: 0000 0000 0000 0000 0000 0000 0000 0000 0000 0000 0000 0000 0000 0000 0000 0000
00e0: 0000 0000 0000 0000 0000 0000 0000 0000 0000 0000 0000 0000 0000 0000 0000 0000
00f0: 0000 0000 0000 0000 0000 0000 0000 0000 0000 0000 0000 0000 0000 0000 0000 0000
0100: 0000 0000 0000 0000 0000 0000 0000 0000 0000 0000 0000 0000 0000 0000 0000 0000
0110: 0000 0000 0000 0000 0000 0000 0000 0000 0000 0000 0000 0000 0000 0000 0000 0000
0120: 0000 0000 0000 0000 0000 0000 0000 0000 0000 0000 0000 0000 0000 0000 0000 0000
0130: 0000 0000 0000 0000 0000 0000 0000 0000 0000 0000 0000 0000 0000 0000 0000 0000
0140: 0000 0000 0000 0000 0000 0000 0000 0000 0000 0000 0000 0000 0000 0000 0000 0000
0150: 0000 0000 0000 0000 0000 0000 0000 0000 0000 0000 0000 0000 0000 0000 0000 0000
0160: 0000 0000 0000 0000 0000 0000 0000 0000 0000 0000 0000 0000 0000 0000 0000 0000
0170: 0000 0000 0000 0000 0000 0000 0000 0000 0000 0000 0000 0000 0000 0000 0000 0000
0180: 0000 0000 0000 0000 0000 0000 0000 0000 0000 0000 0000 0000 0000 0000 0000 0000
0190: 0000 0000 0000 0000 0000 0000 0000 0000 0000 0000 0000 0000 0000 0000 0000 0000
01a0: 0000 0000 0000 0000 0000 0000 0000 0000 0000 0000 0000 0000 0000 0000 0000 0000
01b0: 0000 0000 0000 0000 0000 0000 0000 0000 0000 0000 0000 0000 0000 0000 0000 0000
01c0: 0000 0000 0000 0000 0000 0000 0000 0000 0000 0000 0000 0000 0000 0000 0000 0000
01d0: 0000 0000 0000 0000 0000 0000 0000 0000 0000 0000 0000 0000 0000 0000 0000 0000
01e0: 0000 0000 0000 0000 0000 0000 0000 0000 0000 0000 0000 0000 0000 0000 0000 0000
01f0: 0000 0000 0000 0000 0000 0000 0000 0000 0000 0000 0000 0000 0000 0000 0000 0000
0200: 0000 0000 0000 0000 0000 0000 0000 0000 0000 0000 0000 0000 0000 0000 0000 0000
0210: 0000 0000 0000 0000 0000 0000 0000 0000 0000 0000 0000 0000 0000 0000 0000 0000
0220: 0000 0000 0000 0000 0000 0000 0000 0000 0000 0000 0000 0000 0000 0000 0000 0000
0230: 0000 0000 0000 0000 0000 0000 0000 0000 0000 0000 0000 0000 0000 0000 0000 0000
0240: 0000 0000 0000 0000 0000 0000 0000 0000 0000 0000 0000 0000 0000 0000 0000 0000
0250: 0000 0000 0000 0000 0000 0000 0000 0000 0000 0000 0000 0000 0000 0000 0000 0000
0260: 0000 0000 0000 0000 0000 0000 0000 0000 0000 0000 0000 0000 0000 0000 0000 0000
0270: 0000 0000 0000 0000 0000 0000 0000 0000 0000 0000 0000 0000 0000 0000 0000 0000
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
0aa0: 0000 0000 0000 0000 0000 0000 0000 0000 0000 0000 0000 0000 0000 0000 0000 0000
0ab0: 0000 0000 0000 0000 0000 0000 0000 0000 0000 0000 0000 0000 0000 0000 0000 0000
0ac0: 0000 0000 0000 0000 0000 0000 0000 0000 0000 0000 0000 0000 0000 0000 0000 0000
0ad0: 0000 0000 0000 0000 0000 0000 0000 0000 0000 0000 0000 0000 0000 0000 0000 0000
0ae0: 0000 0000 0000 0000 0000 0000 0000 0000 0000 0000 0000 0000 0000 0000 0000 0000
0af0: 0000 0000 0000 0000 0000 0000 0000 0000 0000 0000 0000 0000 0000 0000 0000 0000
0b00: 0000 0000 0000 0000 0000 0000 0000 0000 0000 0000 0000 0000 0000 0000 0000 0000
0b10: 0000 0000 0000 0000 0000 0000 0000 0000 0000 0000 0000 0000 0000 0000 0000 0000
0b20: 0000 0000 0000 0000 0000 0000 0000 0000 0000 0000 0000 0000 0000 0000 0000 0000
0b30: 0000 0000 0000 0000 0000 0000 0000 0000 0000 0000 0000 0000 0000 0000 0000 0000
0b40: 0000 0000 0000 0000 0000 0000 0000 0000 0000 0000 0000 0000 0000 0000 0000 0000
0b50: 0000 0000 0000 0000 0000 0000 0000 0000 0000 0000 0000 0000 0000 0000 0000 0000
0b60: 0000 0000 0000 0000 0000 0000 0000 0000 0000 0000 0000 0000 0000 0000 0000 0000
0b70: 0000 0000 0000 0000 0000 0000 0000 0000 0000 0000 0000 0000 0000 0000 0000 0000
0b80: 0000 0000 0000 0000 0000 0000 0000 0000 0000 0000 0000 0000 0000 0000 0000 0000
0b90: 0000 0000 0000 0000 0000 0000 0000 0000 0000 0000 0000 0000 0000 0000 0000 0000
0ba0: 0000 0000 0000 0000 0000 0000 0000 0000 0000 0000 0000 0000 0000 0000 0000 0000
0bb0: 0000 0000 0000 0000 0000 0000 0000 0000 0000 0000 0000 0000 0000 0000 0000 0000
0bc0: 0000 0000 0000 0000 0000 0000 0000 0000 0000 0000 0000 0000 0000 0000 0000 0000
0bd0: 0000 0000 0000 0000 0000 0000 0000 0000 0000 0000 0000 0000 0000 0000 0000 0000
0be0: 0000 0000 0000 0000 0000 0000 0000 0000 0000 0000 0000 0000 0000 0000 0000 0000
0bf0: 0000 0000 0000 0000 0000 0000 0000 0000 0000 0000 0000 0000 0000 0000 0000 0000
0c00: 0000 0000 0000 0000 0000 0000 0000 0000 0000 0000 0000 0000 0000 0000 0000 0000
0c10: 0000 0000 0000 0000 0000 0000 0000 0000 0000 0000 0000 0000 0000 0000 0000 0000
0c20: 0000 0000 0000 0000 0000 0000 0000 0000 0000 0000 0000 0000 0000 0000 0000 0000
0c30: 0000 0000 0000 0000 0000 0000 0000 0000 0000 0000 0000 0000 0000 0000 0000 0000
0c40: 0000 0000 0000 0000 0000 0000 0000 0000 0000 0000 0000 0000 0000 0000 0000 0000
0c50: 0000 0000 0000 0000 0000 0000 0000 0000 0000 0000 0000 0000 0000 0000 0000 0000
0c60: 0000 0000 0000 0000 0000 0000 0000 0000 0000 0000 0000 0000 0000 0000 0000 0000
0c70: 0000 0000 0000 0000 0000 0000 0000 0000 0000 0000 0000 0000 0000 0000 0000 0000
0c80: 0000 0000 0000 0000 0000 0000 0000 0000 0000 0000 0000 0000 0000 0000 0000 0000
0c90: 0000 0000 0000 0000 0000 0000 0000 0000 0000 0000 0000 0000 0000 0000 0000 0000
0ca0: 0000 0000 0000 0000 0000 0000 0000 0000 0000 0000 0000 0000 0000 0000 0000 0000
0cb0: 0000 0000 0000 0000 0000 0000 0000 0000 0000 0000 0000 0000 0000 0000 0000 0000
0cc0: 0000 0000 0000 0000 0000 0000 0000 0000 0000 0000 0000 0000 0000 0000 0000 0000
0cd0: 0000 0000 0000 0000 0000 0000 0000 0000 0000 0000 0000 0000 0000 0000 0000 0000
0ce0: 0000 0000 0000 0000 0000 0000 0000 0000 0000 0000 0000 0000 0000 0000 0000 0000
0cf0: 0000 0000 0000 0000 0000 0000 0000 0000 0000 0000 0000 0000 0000 0000 0000 0000
0d00: 0000 0000 0000 0000 0000 0000 0000 0000 0000 0000 0000 0000 0000 0000 0000 0000
0d10: 0000 0000 0000 0000 0000 0000 0000 0000 0000 0000 0000 0000 0000 0000 0000 0000
0d20: 0000 0000 0000 0000 0000 0000 0000 0000 0000 0000 0000 0000 0000 0000 0000 0000
0d30: 0000 0000 0000 0000 0000 0000 0000 0000 0000 0000 0000 0000 0000 0000 0000 0000
0d40: 0000 0000 0000 0000 0000 0000 0000 0000 0000 0000 0000 0000 0000 0000 0000 0000
0d50: 0000 0000 0000 0000 0000 0000 0000 0000 0000 0000 0000 0000 0000 0000 0000 0000
0d60: 0000 0000 0000 0000 0000 0000 0000 0000 0000 0000 0000 0000 0000 0000 0000 0000
0d70: 0000 0000 0000 0000 0000 0000 0000 0000 0000 0000 0000 0000 0000 0000 0000 0000
0d80: 0000 0000 0000 0000 0000 0000 0000 0000 0000 0000 0000 0000 0000 0000 0000 0000
0d90: 0000 0000 0000 0000 0000 0000 0000 0000 0000 0000 0000 0000 0000 0000 0000 0000
0da0: 0000 0000 0000 0000 0000 0000 0000 0000 0000 0000 0000 0000 0000 0000 0000 0000
0db0: 0000 0000 0000 0000 0000 0000 0000 0000 0000 0000 0000 0000 0000 0000 0000 0000
0dc0: 0000 0000 0000 0000 0000 0000 0000 0000 0000 0000 0000 0000 0000 0000 0000 0000
0dd0: 0000 0000 0000 0000 0000 0000 0000 0000 0000 0000 0000 0000 0000 0000 0000 0000
0de0: 0000 0000 0000 0000 0000 0000 0000 0000 0000 0000 0000 0000 0000 0000 0000 0000
0df0: 0000 0000 0000 0000 0000 0000 0000 0000 0000 0000 0000 0000 0000 0000 0000 0000
0e00: 0000 0000 0000 0000 0000 0000 0000 0000 0000 0000 0000 0000 0000 0000 0000 0000
0e10: 0000 0000 0000 0000 0000 0000 0000 0000 0000 0000 0000 0000 0000 0000 0000 0000
0e20: 0000 0000 0000 0000 0000 0000 0000 0000 0000 0000 0000 0000 0000 0000 0000 0000
0e30: 0000 0000 0000 0000 0000 0000 0000 0000 0000 0000 0000 0000 0000 0000 0000 0000
0e40: 0000 0000 0000 0000 0000 0000 0000 0000 0000 0000 0000 0000 0000 0000 0000 0000
0e50: 0000 0000 0000 0000 0000 0000 0000 0000 0000 0000 0000 0000 0000 0000 0000 0000
0e60: 0000 0000 0000 0000 0000 0000 0000 0000 0000 0000 0000 0000 0000 0000 0000 0000
0e70: 0000 0000 0000 0000 0000 0000 0000 0000 0000 0000 0000 0000 0000 0000 0000 0000
0e80: 0000 0000 0000 0000 0000 0000 0000 0000 0000 0000 0000 0000 0000 0000 0000 0000
0e90: 0000 0000 0000 0000 0000 0000 0000 0000 0000 0000 0000 0000 0000 0000 0000 0000
0ea0: 0000 0000 0000 0000 0000 0000 0000 0000 0000 0000 0000 0000 0000 0000 0000 0000
0eb0: 0000 0000 0000 0000 0000 0000 0000 0000 0000 0000 0000 0000 0000 0000 0000 0000
0ec0: 0000 0000 0000 0000 0000 0000 0000 0000 0000 0000 0000 0000 0000 0000 0000 0000
0ed0: 0000 0000 0000 0000 0000 0000 0000 0000 0000 0000 0000 0000 0000 0000 0000 0000
0ee0: 0000 0000 0000 0000 0000 0000 0000 0000 0000 0000 0000 0000 0000 0000 0000 0000
0ef0: 0000 0000 0000 0000 0000 0000 0000 0000 0000 0000 0000 0000 0000 0000 0000 0000
0f00: 0000 0000 0000 0000 0000 0000 0000 0000 0000 0000 0000 0000 0000 0000 0000 0000
0f10: 0000 0000 0000 0000 0000 0000 0000 0000 0000 0000 0000 0000 0000 0000 0000 0000
0f20: 0000 0000 0000 0000 0000 0000 0000 0000 0000 0000 0000 0000 0000 0000 0000 0000
0f30: 0000 0000 0000 0000 0000 0000 0000 0000 0000 0000 0000 0000 0000 0000 0000 0000
0f40: 0000 0000 0000 0000 0000 0000 0000 0000 0000 0000 0000 0000 0000 0000 0000 0000
0f50: 0000 0000 0000 0000 0000 0000 0000 0000 0000 0000 0000 0000 0000 0000 0000 0000
0f60: 0000 0000 0000 0000 0000 0000 0000 0000 0000 0000 0000 0000 0000 0000 0000 0000
0f70: 0000 0000 0000 0000 0000 0000 0000 0000 0000 0000 0000 0000 0000 0000 0000 0000
0f80: 0000 0000 0000 0000 0000 0000 0000 0000 0000 0000 0000 0000 0000 0000 0000 0000
0f90: 0000 0000 0000 0000 0000 0000 0000 0000 0000 0000 0000 0000 0000 0000 0000 0000
0fa0: 0000 0000 0000 0000 0000 0000 0000 0000 0000 0000 0000 0000 0000 0000 0000 0000
0fb0: 0000 0000 0000 0000 0000 0000 0000 0000 0000 0000 0000 0000 0000 0000 0000 0000
0fc0: 0000 0000 0000 0000 0000 0000 0000 0000 0000 0000 0000 0000 0000 0000 0000 0000
0fd0: 0000 0000 0000 0000 0000 0000 0000 0000 0000 0000 0000 0000 0000 0000 0000 0000
0fe0: 0000 0000 0000 0000 0000 0000 0000 0000 0000 0000 0000 0000 0000 0000 0000 0000
0ff0: 0000 0000 0000 0000 0000 0000 0000 0000 0000 0000 0000 0000 0000 0000 0000 0000
1000: 0000 0000 0000 0000 0000 0000 0000 0000 0000 0000 0000 0000 0000 0000 0000 0000
1010: 0000 0000 0000 0000 0000 0000 0000 0000 0000 0000 0000 0000 0000 0000 0000 0000
1020: 0000 0000 0000 0000 0000 0000 0000 0000 0000 0000 0000 0000 0000 0000 0000 0000
1030: 0000 0000 0000 0000 0000 0000 0000 0000 0000 0000 0000 0000 0000 0000 0000 0000
1040: 0000 0000 0000 0000 0000 0000 0000 0000 0000 0000 0000 0000 0000 0000 0000 0000
1050: 0000 0000 0000 0000 0000 0000 0000 0000 0000 0000 0000 0000 0000 0000 0000 0000
1060: 0000 0000 0000 0000 0000 0000 0000 0000 0000 0000 0000 0000 0000 0000 0000 0000
1070: 0000 0000 0000 0000 0000 0000 0000 0000 0000 0000 0000 0000 0000 0000 0000 0000
1080: 0000 0000 0000 0000 0000 0000 0000 0000 0000 0000 0000 0000 0000 0000 0000 0000
1090: 0000 0000 0000 0000 0000 0000 0000 0000 0000 0000 0000 0000 0000 0000 0000 0000
10a0: 0000 0000 0000 0000 0000 0000 0000 0000 0000 0000 0000 0000 0000 0000 0000 0000
10b0: 0000 0000 0000 0000 0000 0000 0000 0000 0000 0000 0000 0000 0000 0000 0000 0000
10c0: 0000 0000 0000 0000 0000 0000 0000 0000 0000 0000 0000 0000 0000 0000 0000 0000
10d0: 0000 0000 0000 0000 0000 0000 0000 0000 0000 0000 0000 0000 0000 0000 0000 0000
10e0: 0000 0000 0000 0000 0000 0000 0000 0000 0000 0000 0000 0000 0000 0000 0000 0000
10f0: 0000 0000 0000 0000 0000 0000 0000 0000 0000 0000 0000 0000 0000 0000 0000 0000
1100: 0000 0000 0000 0000 0000 0000 0000 0000 0000 0000 0000 0000 0000 0000 0000 0000
1110: 0000 0000 0000 0000 0000 0000 0000 0000 0000 0000 0000 0000 0000 0000 0000 0000
1120: 0000 0000 0000 0000 0000 0000 0000 0000 0000 0000 0000 0000 0000 0000 0000 0000
1130: 0000 0000 0000 0000 0000 0000 0000 0000 0000 0000 0000 0000 0000 0000 0000 0000
1140: 0000 0000 0000 0000 0000 0000 0000 0000 0000 0000 0000 0000 0000 0000 0000 0000
1150: 0000 0000 0000 0000 0000 0000 0000 0000 0000 0000 0000 0000 0000 0000 0000 0000
1160: 0000 0000 0000 0000 0000 0000 0000 0000 0000 0000 0000 0000 0000 0000 0000 0000
1170: 0000 0000 0000 0000 0000 0000 0000 0000 0000 0000 0000 0000 0000 0000 0000 0000
1180: 0000 0000 0000 0000 0000 0000 0000 0000 0000 0000 0000 0000 0000 0000 0000 0000
1190: 0000 0000 0000 0000 0000 0000 0000 0000 0000 0000 0000 0000 0000 0000 0000 0000
11a0: 0000 0000 0000 0000 0000 0000 0000 0000 0000 0000 0000 0000 0000 0000 0000 0000
11b0: 0000 0000 0000 0000 0000 0000 0000 0000 0000 0000 0000 0000 0000 0000 0000 0000
11c0: 0000 0000 0000 0000 0000 0000 0000 0000 0000 0000 0000 0000 0000 0000 0000 0000
11d0: 0000 0000 0000 0000 0000 0000 0000 0000 0000 0000 0000 0000 0000 0000 0000 0000
11e0: 0000 0000 0000 0000 0000 0000 0000 0000 0000 0000 0000 0000 0000 0000 0000 0000
11f0: 0000 0000 0000 0000 0000 0000 0000 0000 0000 0000 0000 0000 0000 0000 0000 0000
1200: 0000 0000 0000 0000 0000 0000 0000 0000 0000 0000 0000 0000 0000 0000 0000 0000
1210: 0000 0000 0000 0000 0000 0000 0000 0000 0000 0000 0000 0000 0000 0000 0000 0000
1220: 0000 0000 0000 0000 0000 0000 0000 0000 0000 0000 0000 0000 0000 0000 0000 0000
1230: 0000 0000 0000 0000 0000 0000 0000 0000 0000 0000 0000 0000 0000 0000 0000 0000
1240: 0000 0000 0000 0000 0000 0000 0000 0000 0000 0000 0000 0000 0000 0000 0000 0000
1250: 0000 0000 0000 0000 0000 0000 0000 0000 0000 0000 0000 0000 0000 0000 0000 0000
1260: 0000 0000 0000 0000 0000 0000 0000 0000 0000 0000 0000 0000 0000 0000 0000 0000
1270: 0000 0000 0000 0000 0000 0000 0000 0000 0000 0000 0000 0000 0000 0000 0000 0000
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
1aa0: 0000 0000 0000 0000 0000 0000 0000 0000 0000 0000 0000 0000 0000 0000 0000 0000
1ab0: 0000 0000 0000 0000 0000 0000 0000 0000 0000 0000 0000 0000 0000 0000 0000 0000
1ac0: 0000 0000 0000 0000 0000 0000 0000 0000 0000 0000 0000 0000 0000 0000 0000 0000
1ad0: 0000 0000 0000 0000 0000 0000 0000 0000 0000 0000 0000 0000 0000 0000 0000 0000
1ae0: 0000 0000 0000 0000 0000 0000 0000 0000 0000 0000 0000 0000 0000 0000 0000 0000
1af0: 0000 0000 0000 0000 0000 0000 0000 0000 0000 0000 0000 0000 0000 0000 0000 0000
1b00: 0000 0000 0000 0000 0000 0000 0000 0000 0000 0000 0000 0000 0000 0000 0000 0000
1b10: 0000 0000 0000 0000 0000 0000 0000 0000 0000 0000 0000 0000 0000 0000 0000 0000
1b20: 0000 0000 0000 0000 0000 0000 0000 0000 0000 0000 0000 0000 0000 0000 0000 0000
1b30: 0000 0000 0000 0000 0000 0000 0000 0000 0000 0000 0000 0000 0000 0000 0000 0000
1b40: 0000 0000 0000 0000 0000 0000 0000 0000 0000 0000 0000 0000 0000 0000 0000 0000
1b50: 0000 0000 0000 0000 0000 0000 0000 0000 0000 0000 0000 0000 0000 0000 0000 0000
1b60: 0000 0000 0000 0000 0000 0000 0000 0000 0000 0000 0000 0000 0000 0000 0000 0000
1b70: 0000 0000 0000 0000 0000 0000 0000 0000 0000 0000 0000 0000 0000 0000 0000 0000
1b80: 0000 0000 0000 0000 0000 0000 0000 0000 0000 0000 0000 0000 0000 0000 0000 0000
1b90: 0000 0000 0000 0000 0000 0000 0000 0000 0000 0000 0000 0000 0000 0000 0000 0000
1ba0: 0000 0000 0000 0000 0000 0000 0000 0000 0000 0000 0000 0000 0000 0000 0000 0000
1bb0: 0000 0000 0000 0000 0000 0000 0000 0000 0000 0000 0000 0000 0000 0000 0000 0000
1bc0: 0000 0000 0000 0000 0000 0000 0000 0000 0000 0000 0000 0000 0000 0000 0000 0000
1bd0: 0000 0000 0000 0000 0000 0000 0000 0000 0000 0000 0000 0000 0000 0000 0000 0000
1be0: 0000 0000 0000 0000 0000 0000 0000 0000 0000 0000 0000 0000 0000 0000 0000 0000
1bf0: 0000 0000 0000 0000 0000 0000 0000 0000 0000 0000 0000 0000 0000 0000 0000 0000
1c00: 0000 0000 0000 0000 0000 0000 0000 0000 0000 0000 0000 0000 0000 0000 0000 0000
1c10: 0000 0000 0000 0000 0000 0000 0000 0000 0000 0000 0000 0000 0000 0000 0000 0000
1c20: 0000 0000 0000 0000 0000 0000 0000 0000 0000 0000 0000 0000 0000 0000 0000 0000
1c30: 0000 0000 0000 0000 0000 0000 0000 0000 0000 0000 0000 0000 0000 0000 0000 0000
1c40: 0000 0000 0000 0000 0000 0000 0000 0000 0000 0000 0000 0000 0000 0000 0000 0000
1c50: 0000 0000 0000 0000 0000 0000 0000 0000 0000 0000 0000 0000 0000 0000 0000 0000
1c60: 0000 0000 0000 0000 0000 0000 0000 0000 0000 0000 0000 0000 0000 0000 0000 0000
1c70: 0000 0000 0000 0000 0000 0000 0000 0000 0000 0000 0000 0000 0000 0000 0000 0000
1c80: 0000 0000 0000 0000 0000 0000 0000 0000 0000 0000 0000 0000 0000 0000 0000 0000
1c90: 0000 0000 0000 0000 0000 0000 0000 0000 0000 0000 0000 0000 0000 0000 0000 0000
1ca0: 0000 0000 0000 0000 0000 0000 0000 0000 0000 0000 0000 0000 0000 0000 0000 0000
1cb0: 0000 0000 0000 0000 0000 0000 0000 0000 0000 0000 0000 0000 0000 0000 0000 0000
1cc0: 0000 0000 0000 0000 0000 0000 0000 0000 0000 0000 0000 0000 0000 0000 0000 0000
1cd0: 0000 0000 0000 0000 0000 0000 0000 0000 0000 0000 0000 0000 0000 0000 0000 0000
1ce0: 0000 0000 0000 0000 0000 0000 0000 0000 0000 0000 0000 0000 0000 0000 0000 0000
1cf0: 0000 0000 0000 0000 0000 0000 0000 0000 0000 0000 0000 0000 0000 0000 0000 0000
1d00: 0000 0000 0000 0000 0000 0000 0000 0000 0000 0000 0000 0000 0000 0000 0000 0000
1d10: 0000 0000 0000 0000 0000 0000 0000 0000 0000 0000 0000 0000 0000 0000 0000 0000
1d20: 0000 0000 0000 0000 0000 0000 0000 0000 0000 0000 0000 0000 0000 0000 0000 0000
1d30: 0000 0000 0000 0000 0000 0000 0000 0000 0000 0000 0000 0000 0000 0000 0000 0000
1d40: 0000 0000 0000 0000 0000 0000 0000 0000 0000 0000 0000 0000 0000 0000 0000 0000
1d50: 0000 0000 0000 0000 0000 0000 0000 0000 0000 0000 0000 0000 0000 0000 0000 0000
1d60: 0000 0000 0000 0000 0000 0000 0000 0000 0000 0000 0000 0000 0000 0000 0000 0000
1d70: 0000 0000 0000 0000 0000 0000 0000 0000 0000 0000 0000 0000 0000 0000 0000 0000
1d80: 0000 0000 0000 0000 0000 0000 0000 0000 0000 0000 0000 0000 0000 0000 0000 0000
1d90: 0000 0000 0000 0000 0000 0000 0000 0000 0000 0000 0000 0000 0000 0000 0000 0000
1da0: 0000 0000 0000 0000 0000 0000 0000 0000 0000 0000 0000 0000 0000 0000 0000 0000
1db0: 0000 0000 0000 0000 0000 0000 0000 0000 0000 0000 0000 0000 0000 0000 0000 0000
1dc0: 0000 0000 0000 0000 0000 0000 0000 0000 0000 0000 0000 0000 0000 0000 0000 0000
1dd0: 0000 0000 0000 0000 0000 0000 0000 0000 0000 0000 0000 0000 0000 0000 0000 0000
1de0: 0000 0000 0000 0000 0000 0000 0000 0000 0000 0000 0000 0000 0000 0000 0000 0000
1df0: 0000 0000 0000 0000 0000 0000 0000 0000 0000 0000 0000 0000 0000 0000 0000 0000
1e00: 0000 0000 0000 0000 0000 0000 0000 0000 0000 0000 0000 0000 0000 0000 0000 0000
1e10: 0000 0000 0000 0000 0000 0000 0000 0000 0000 0000 0000 0000 0000 0000 0000 0000
1e20: 0000 0000 0000 0000 0000 0000 0000 0000 0000 0000 0000 0000 0000 0000 0000 0000
1e30: 0000 0000 0000 0000 0000 0000 0000 0000 0000 0000 0000 0000 0000 0000 0000 0000
1e40: 0000 0000 0000 0000 0000 0000 0000 0000 0000 0000 0000 0000 0000 0000 0000 0000
1e50: 0000 0000 0000 0000 0000 0000 0000 0000 0000 0000 0000 0000 0000 0000 0000 0000
1e60: 0000 0000 0000 0000 0000 0000 0000 0000 0000 0000 0000 0000 0000 0000 0000 0000
1e70: 0000 0000 0000 0000 0000 0000 0000 0000 0000 0000 0000 0000 0000 0000 0000 0000
1e80: 0000 0000 0000 0000 0000 0000 0000 0000 0000 0000 0000 0000 0000 0000 0000 0000
1e90: 0000 0000 0000 0000 0000 0000 0000 0000 0000 0000 0000 0000 0000 0000 0000 0000
1ea0: 0000 0000 0000 0000 0000 0000 0000 0000 0000 0000 0000 0000 0000 0000 0000 0000
1eb0: 0000 0000 0000 0000 0000 0000 0000 0000 0000 0000 0000 0000 0000 0000 0000 0000
1ec0: 0000 0000 0000 0000 0000 0000 0000 0000 0000 0000 0000 0000 0000 0000 0000 0000
1ed0: 0000 0000 0000 0000 0000 0000 0000 0000 0000 0000 0000 0000 0000 0000 0000 0000
1ee0: 0000 0000 0000 0000 0000 0000 0000 0000 0000 0000 0000 0000 0000 0000 0000 0000
1ef0: 0000 0000 0000 0000 0000 0000 0000 0000 0000 0000 0000 0000 0000 0000 0000 0000
1f00: 0000 0000 0000 0000 0000 0000 0000 0000 0000 0000 0000 0000 0000 0000 0000 0000
1f10: 0000 0000 0000 0000 0000 0000 0000 0000 0000 0000 0000 0000 0000 0000 0000 0000
1f20: 0000 0000 0000 0000 0000 0000 0000 0000 0000 0000 0000 0000 0000 0000 0000 0000
1f30: 0000 0000 0000 0000 0000 0000 0000 0000 0000 0000 0000 0000 0000 0000 0000 0000
1f40: 0000 0000 0000 0000 0000 0000 0000 0000 0000 0000 0000 0000 0000 0000 0000 0000
1f50: 0000 0000 0000 0000 0000 0000 0000 0000 0000 0000 0000 0000 0000 0000 0000 0000
1f60: 0000 0000 0000 0000 0000 0000 0000 0000 0000 0000 0000 0000 0000 0000 0000 0000
1f70: 0000 0000 0000 0000 0000 0000 0000 0000 0000 0000 0000 0000 0000 0000 0000 0000
1f80: 0000 0000 0000 0000 0000 0000 0000 0000 0000 0000 0000 0000 0000 0000 0000 0000
1f90: 0000 0000 0000 0000 0000 0000 0000 0000 0000 0000 0000 0000 0000 0000 0000 0000
1fa0: 0000 0000 0000 0000 0000 0000 0000 0000 0000 0000 0000 0000 0000 0000 0000 0000
1fb0: 0000 0000 0000 0000 0000 0000 0000 0000 0000 0000 0000 0000 0000 0000 0000 0000
1fc0: 0000 0000 0000 0000 0000 0000 0000 0000 0000 0000 0000 0000 0000 0000 0000 0000
1fd0: 0000 0000 0000 0000 0000 0000 0000 0000 0000 0000 0000 0000 0000 0000 0000 0000
1fe0: 0000 0000 0000 0000 0000 0000 0000 0000 0000 0000 0000 0000 0000 0000 0000 0000
1ff0: 0000 0000 0000 0000 0000 0000 0000 0000 0000 0000 0000 0000 0000 0000 0000 0000
2000: 0025 0533 0000 0000 0000 0000 0000 0000 0000 0000 0000 0000 0000 0000 0000 0000
2010: 0000 0000 0000 0000 0000 0000 0000 0000 0000 0000 0000 0000 0000 0000 0000 0000
2020: 0000 0000 0000 0000 0000 0000 0000 0000 0000 0000 0000 0000 0000 0000 0000 0000
2030: 0000 0000 0000 0000 0000 0000 0000 0000 0000 0000 0000 0000 0000 0000 0000 0000
2040: 0000 0000 0000 0000 0000 0000 0000 0000 0000 0000 0000 0000 0000 0000 0000 0000
2050: 0000 0000 0000 0000 0000 0000 0000 0000 0000 0000 0000 0000 0000 0000 0000 0000
2060: 0000 0000 0000 0000 0000 0000 0000 0000 0000 0000 0000 0000 0000 0000 0000 0000
2070: 0000 0000 0000 0000 0000 0000 0000 0000 0000 0000 0000 0000 0000 0000 0000 0000
2080: 0000 0000 0000 0000 0000 0000 0000 0000 0000 0000 0000 0000 0000 0000 0000 0000
2090: 0000 0000 0000 0000 0000 0000 0000 0000 0000 0000 0000 0000 0000 0000 0000 0000
20a0: 0000 0000 0000 0000 0000 0000 0000 0000 0000 0000 0000 0000 0000 0000 0000 0000
20b0: 0000 0000 0000 0000 0000 0000 0000 0000 0000 0000 0000 0000 0000 0000 0000 0000
20c0: 0000 0000 0000 0000 0000 0000 0000 0000 0000 0000 0000 0000 0000 0000 0000 0000
20d0: 0000 0000 0000 0000 0000 0000 0000 0000 0000 0000 0000 0000 0000 0000 0000 0000
20e0: 0000 0000 0000 0000 0000 0000 0000 0000 0000 0000 0000 0000 0000 0000 0000 0000
20f0: 0000 0000 0000 0000 0000 0000 0000 0000 0000 0000 0000 0000 0000 0000 0000 0000
2100: 0000 0000 0000 0000 0000 0000 0000 0000 0000 0000 0000 0000 0000 0000 0000 0000
2110: 0000 0000 0000 0000 0000 0000 0000 0000 0000 0000 0000 0000 0000 0000 0000 0000
2120: 0000 0000 0000 0000 0000 0000 0000 0000 0000 0000 0000 0000 0000 0000 0000 0000
2130: 0000 0000 0000 0000 0000 0000 0000 0000 0000 0000 0000 0000 0000 0000 0000 0000
2140: 0000 0000 0000 0000 0000 0000 0000 0000 0000 0000 0000 0000 0000 0000 0000 0000
2150: 0000 0000 0000 0000 0000 0000 0000 0000 0000 0000 0000 0000 0000 0000 0000 0000
2160: 0000 0000 0000 0000 0000 0000 0000 0000 0000 0000 0000 0000 0000 0000 0000 0000
2170: 0000 0000 0000 0000 0000 0000 0000 0000 0000 0000 0000 0000 0000 0000 0000 0000
2180: 0000 0000 0000 0000 0000 0000 0000 0000 0000 0000 0000 0000 0000 0000 0000 0000
2190: 0000 0000 0000 0000 0000 0000 0000 0000 0000 0000 0000 0000 0000 0000 0000 0000
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

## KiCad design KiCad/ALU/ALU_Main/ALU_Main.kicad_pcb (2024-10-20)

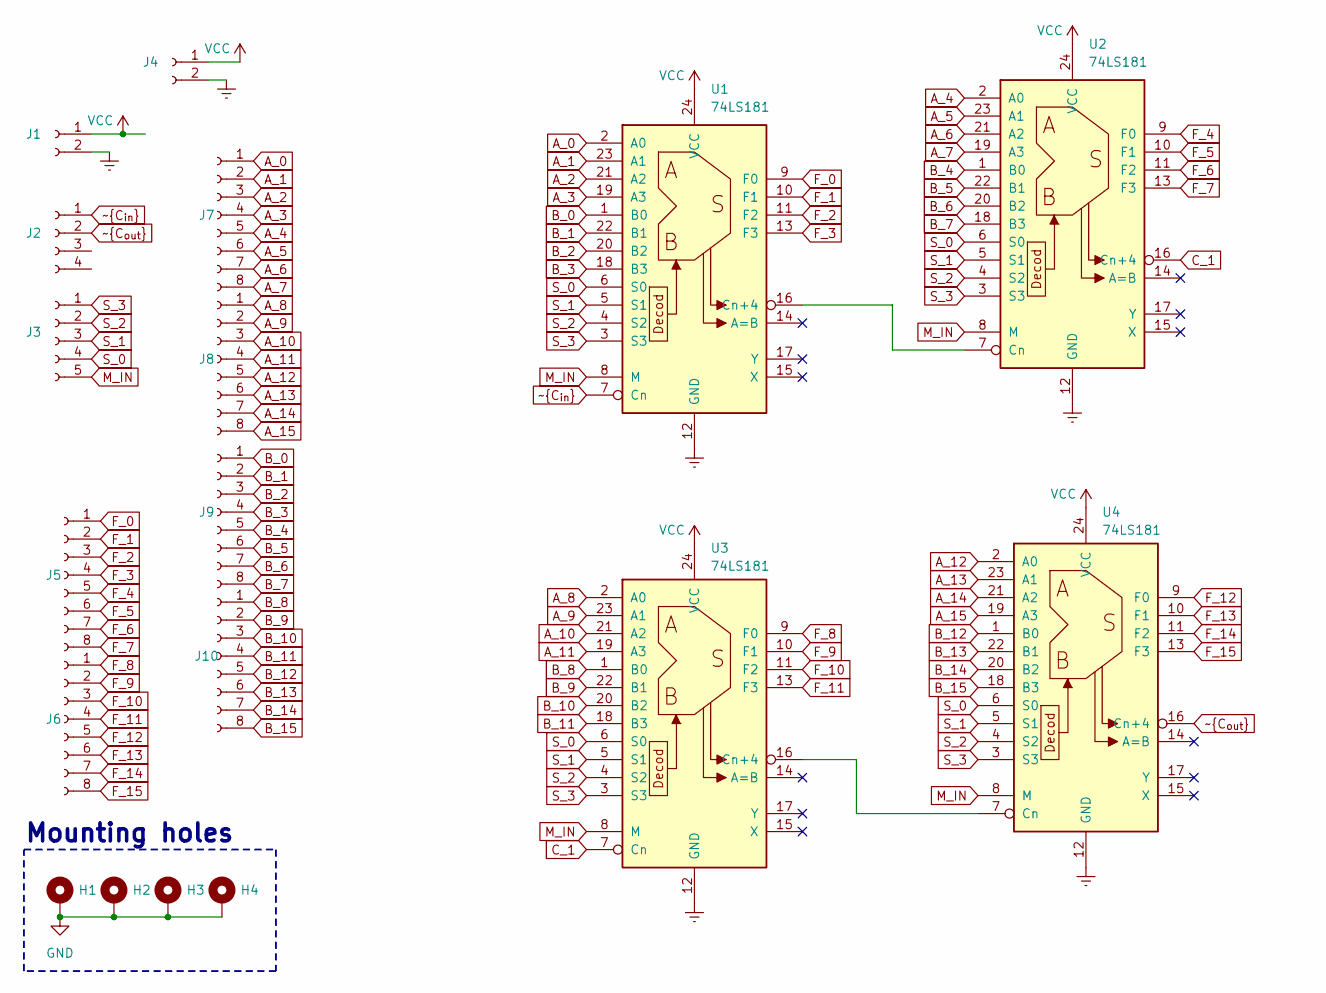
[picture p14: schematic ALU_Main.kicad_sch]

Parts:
H1, H2, H3, H4: MountingHole_Pad; MountingHole_2.2mm_M2_DIN965_Pad
J1, J4: Conn_01x02_Socket; JST_XH_S2B-XH-A-1_1x02_P2.50mm_Horizontal
J2: Conn_01x04_Socket; JST_XH_S4B-XH-A-1_1x04_P2.50mm_Horizontal
J3: Conn_01x05_Socket; JST_XH_S5B-XH-A-1_1x05_P2.50mm_Horizontal
J5, J6, J7, J8, J9, J10: Conn_01x08_Socket; JST_XH_S8B-XH-A-1_1x08_P2.50mm_Horizontal
U1, U2, U3, U4: 74LS181; DIP-24_W15.24mm_Socket_LongPads

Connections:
A_0: J7.1, U1.2 (A0)
A_1: J7.2, U1.23 (A1)
A_2: J7.3, U1.21 (A2)
A_3: J7.4, U1.19 (A3)
A_4: J7.5, U2.2 (A0)
A_5: J7.6, U2.23 (A1)
A_6: J7.7, U2.21 (A2)
A_7: J7.8, U2.19 (A3)
A_8: J8.1, U3.2 (A0)
A_9: J8.2, U3.23 (A1)
A_10: J8.3, U3.21 (A2)
A_11: J8.4, U3.19 (A3)
A_12: J8.5, U4.2 (A0)
A_13: J8.6, U4.23 (A1)
A_14: J8.7, U4.21 (A2)
A_15: J8.8, U4.19 (A3)
B_0: J9.1, U1.1 (B0)
B_1: J9.2, U1.22 (B1)
B_2: J9.3, U1.20 (B2)
B_3: J9.4, U1.18 (B3)
B_4: J9.5, U2.1 (B0)
B_5: J9.6, U2.22 (B1)
B_6: J9.7, U2.20 (B2)
B_7: J9.8, U2.18 (B3)
B_8: J10.1, U3.1 (B0)
B_9: J10.2, U3.22 (B1)
B_10: J10.3, U3.20 (B2)
B_11: J10.4, U3.18 (B3)
B_12: J10.5, U4.1 (B0)
B_13: J10.6, U4.22 (B1)
B_14: J10.7, U4.20 (B2)
B_15: J10.8, U4.18 (B3)
C_1: U2.16 (Cn+4), U3.7 (Cn)
F_0: J5.1, U1.9 (F0)
F_1: J5.2, U1.10 (F1)
F_2: J5.3, U1.11 (F2)
F_3: J5.4, U1.13 (F3)
F_4: J5.5, U2.9 (F0)
F_5: J5.6, U2.10 (F1)
F_6: J5.7, U2.11 (F2)
F_7: J5.8, U2.13 (F3)
F_8: J6.1, U3.9 (F0)
F_9: J6.2, U3.10 (F1)
F_10: J6.3, U3.11 (F2)
F_11: J6.4, U3.13 (F3)
F_12: J6.5, U4.9 (F0)
F_13: J6.6, U4.10 (F1)
F_14: J6.7, U4.11 (F2)
F_15: J6.8, U4.13 (F3)
GND: H1.1, H2.1, H3.1, H4.1, J1.2, J4.2, U1.12 (GND), U2.12 (GND), U3.12 (GND), U4.12 (GND)
M_IN: J3.5, U1.8 (M), U2.8 (M), U3.8 (M), U4.8 (M)
unnamed: U1.16 (Cn+4), U2.7 (Cn)
unnamed: U3.16 (Cn+4), U4.7 (Cn)
S_0: J3.4, U1.6 (S0), U2.6 (S0), U3.6 (S0), U4.6 (S0)
S_1: J3.3, U1.5 (S1), U2.5 (S1), U3.5 (S1), U4.5 (S1)
S_2: J3.2, U1.4 (S2), U2.4 (S2), U3.4 (S2), U4.4 (S2)
S_3: J3.1, U1.3 (S3), U2.3 (S3), U3.3 (S3), U4.3 (S3)
VCC: J1.1, J4.1, U1.24 (VCC), U2.24 (VCC), U3.24 (VCC), U4.24 (VCC)
~C_{in}: J2.1, U1.7 (Cn)
~C_{out}: J2.2, U4.16 (Cn+4)

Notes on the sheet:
Mounting holes

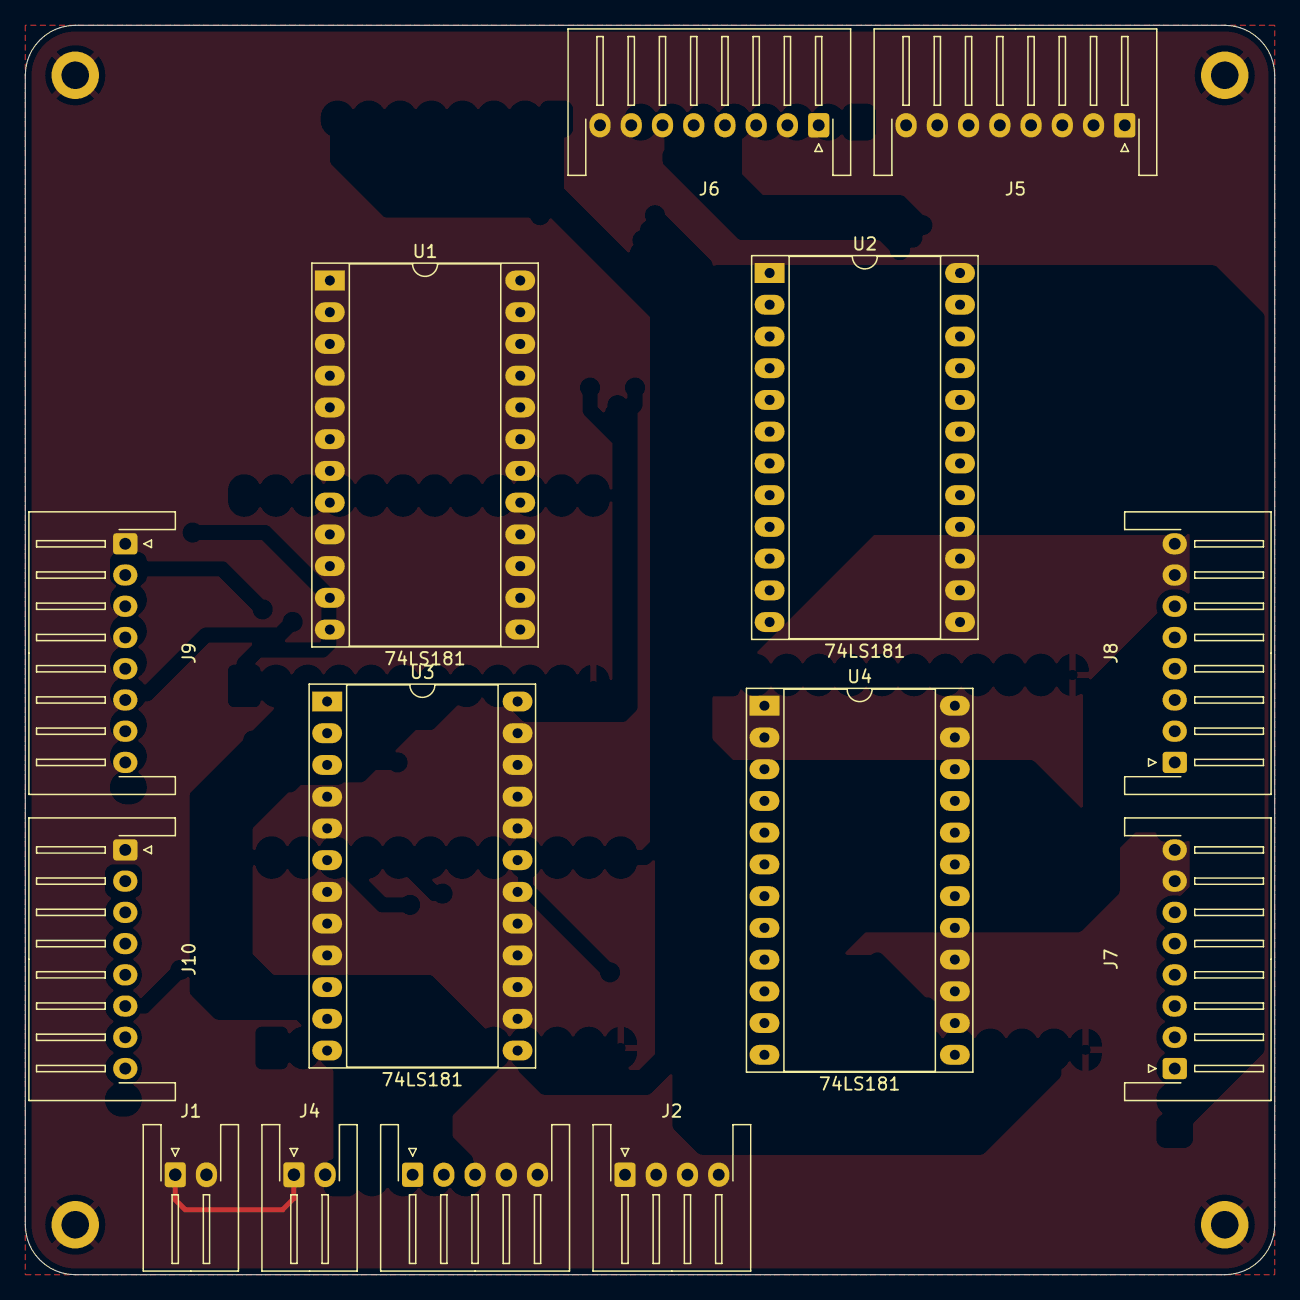
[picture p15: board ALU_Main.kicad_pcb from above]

Board: 2 copper layers, 100.0 x 100.0 mm, 18 parts (0 on the bottom side), 60 nets.

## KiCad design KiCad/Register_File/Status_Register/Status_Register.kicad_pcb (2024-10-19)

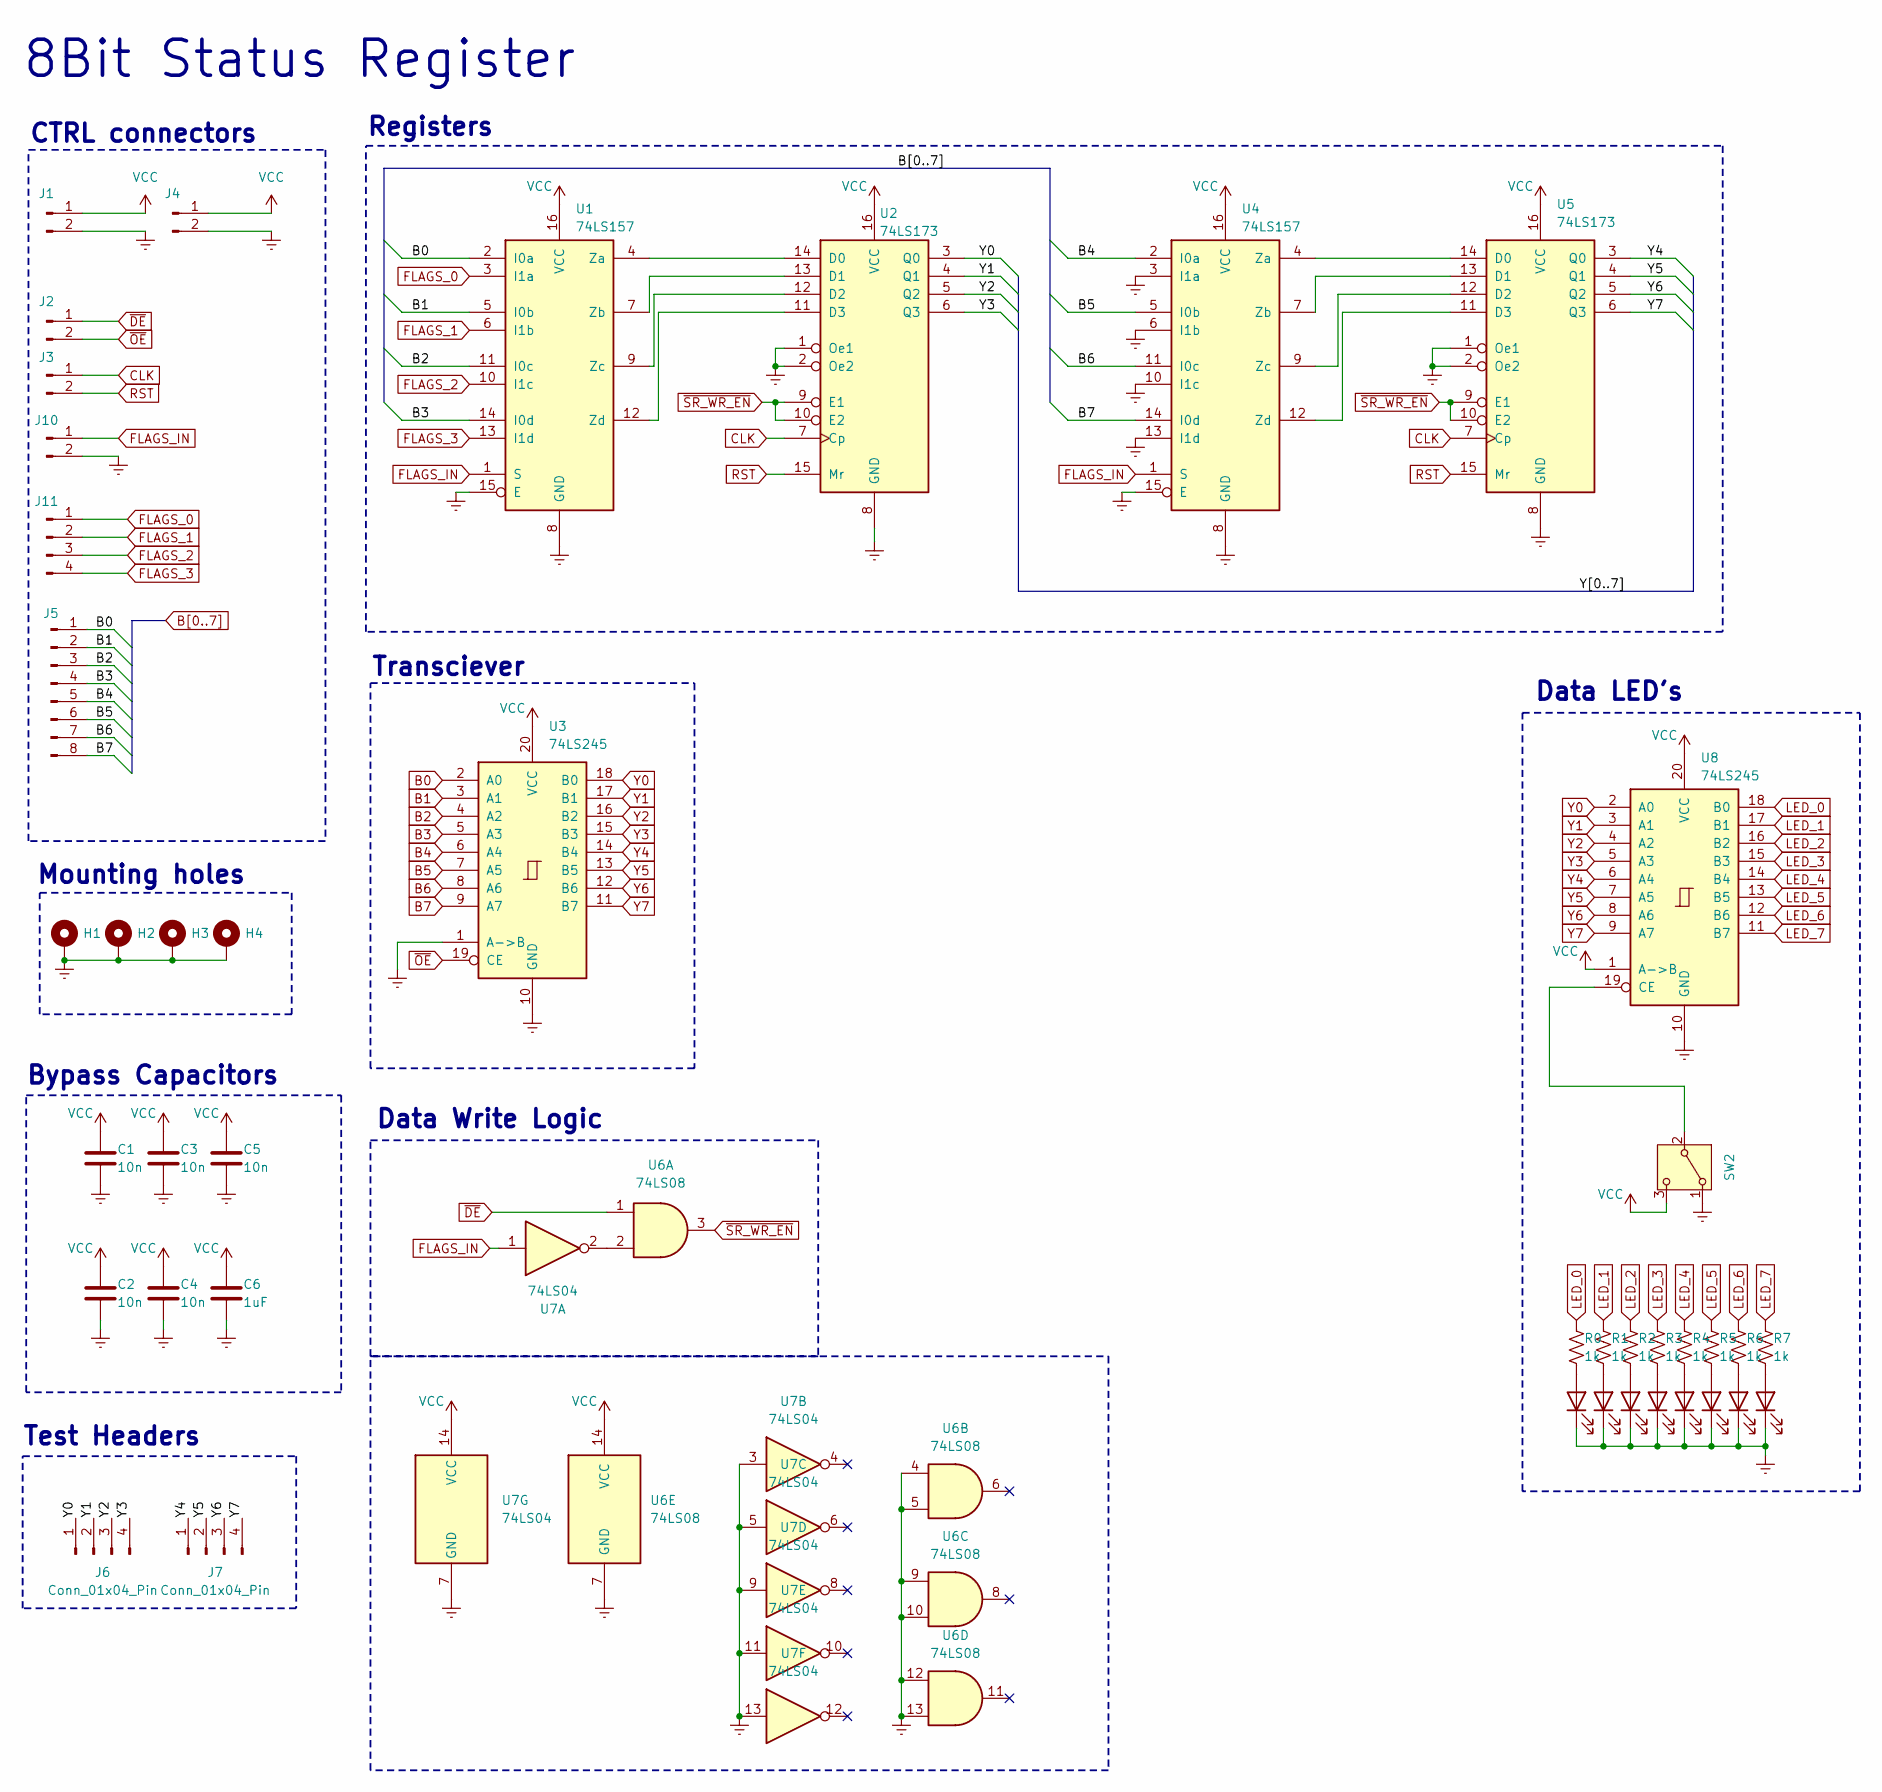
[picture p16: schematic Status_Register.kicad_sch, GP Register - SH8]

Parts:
C1, C2, C3, C4, C5: 10n; C_1206_3216Metric_Pad1.33x1.80mm_HandSolder
C6: 1uF; C_Radial_D6.3mm_H11.0mm_P2.50mm
D0, D1, D2, D3, D4, D5, D6, D7: LED; LED_Rectangular_W3.0mm_H2.0mm
H1, H2, H3, H4: MountingHole_Pad; MountingHole_2.2mm_M2_DIN965_Pad
J1, J2, J3, J4, J10: Conn_01x02_Pin; JST_XH_S2B-XH-A-1_1x02_P2.50mm_Horizontal
J5: Conn_01x08_Pin; JST_XH_S8B-XH-A-1_1x08_P2.50mm_Horizontal
J6, J7: Conn_01x04_Pin; PinHeader_1x04_P2.54mm_Vertical
J11: Conn_01x04_Pin; JST_XH_S4B-XH-A-1_1x04_P2.50mm_Horizontal
R0, R1, R2, R3, R4, R5, R6, R7: 1k; R_1206_3216Metric_Pad1.30x1.75mm_HandSolder
SW2: SW_SPDT; SW_Slide_SPDT_Angled_CK_OS102011MA1Q
U1, U4: 74LS157; DIP-16_W7.62mm_Socket_LongPads
U2, U5: 74LS173; DIP-16_W7.62mm_Socket_LongPads
U3, U8: 74LS245; DIP-20_W7.62mm_Socket_LongPads
U6: 74LS08; DIP-14_W7.62mm_Socket_LongPads
U7: 74LS04; DIP-14_W7.62mm_Socket_LongPads

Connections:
B0: J5.1, U1.2 (I0a), U3.2 (A0)
B1: J5.2, U1.5 (I0b), U3.3 (A1)
B2: J5.3, U1.11 (I0c), U3.4 (A2)
B3: J5.4, U1.14 (I0d), U3.5 (A3)
B4: J5.5, U3.6 (A4), U4.2 (I0a)
B5: J5.6, U3.7 (A5), U4.5 (I0b)
B6: J5.7, U3.8 (A6), U4.11 (I0c)
B7: J5.8, U3.9 (A7), U4.14 (I0d)
CLK: J3.1, U2.7 (Cp), U5.7 (Cp)
FLAGS_0: J11.1, U1.3 (I1a)
FLAGS_1: J11.2, U1.6 (I1b)
FLAGS_2: J11.3, U1.10 (I1c)
FLAGS_3: J11.4, U1.13 (I1d)
FLAGS_IN: J10.1, U1.1 (S), U4.1 (S), U7.1
GND: C1.2, C2.2, C3.2, C4.2, C5.2, C6.2, D0.1 (K), D1.1 (K), D2.1 (K), D3.1 (K), D4.1 (K), D5.1 (K), D6.1 (K), D7.1 (K), H1.1, H2.1, H3.1, H4.1, J1.2, J4.2, J10.2, SW2.1 (A), U1.8 (GND), U1.15 (E), U2.1 (Oe1), U2.2 (Oe2), U2.8 (GND), U3.1 (A->B), U3.10 (GND), U4.3 (I1a), U4.6 (I1b), U4.8 (GND), U4.10 (I1c), U4.13 (I1d), U4.15 (E), U5.1 (Oe1), U5.2 (Oe2), U5.8 (GND), U6.4, U6.5, U6.7 (GND), U6.9, U6.10, U6.12, U6.13, U7.3, U7.5, U7.7 (GND), U7.9, U7.11, U7.13, U8.10 (GND)
LED_0: R0.1, U8.18 (B0)
LED_1: R1.1, U8.17 (B1)
LED_2: R2.1, U8.16 (B2)
LED_3: R3.1, U8.15 (B3)
LED_4: R4.1, U8.14 (B4)
LED_5: R5.1, U8.13 (B5)
LED_6: R6.1, U8.12 (B6)
LED_7: R7.1, U8.11 (B7)
unnamed: D0.2 (A), R0.2
unnamed: D1.2 (A), R1.2
unnamed: D2.2 (A), R2.2
unnamed: D3.2 (A), R3.2
unnamed: D4.2 (A), R4.2
unnamed: D5.2 (A), R5.2
unnamed: D6.2 (A), R6.2
unnamed: D7.2 (A), R7.2
unnamed: SW2.2 (B), U8.19 (CE)
unnamed: U1.4 (Za), U2.14 (D0)
unnamed: U1.7 (Zb), U2.13 (D1)
unnamed: U1.9 (Zc), U2.12 (D2)
unnamed: U1.12 (Zd), U2.11 (D3)
unnamed: U4.4 (Za), U5.14 (D0)
unnamed: U4.7 (Zb), U5.13 (D1)
unnamed: U4.9 (Zc), U5.12 (D2)
unnamed: U4.12 (Zd), U5.11 (D3)
unnamed: U6.2, U7.2
RST: J3.2, U2.15 (Mr), U5.15 (Mr)
VCC: C1.1, C2.1, C3.1, C4.1, C5.1, C6.1, J1.1, J4.1, SW2.3 (C), U1.16 (VCC), U2.16 (VCC), U3.20 (VCC), U4.16 (VCC), U5.16 (VCC), U6.14 (VCC), U7.14 (VCC), U8.1 (A->B), U8.20 (VCC)
Y0: J6.1, U2.3 (Q0), U3.18 (B0), U8.2 (A0)
Y1: J6.2, U2.4 (Q1), U3.17 (B1), U8.3 (A1)
Y2: J6.3, U2.5 (Q2), U3.16 (B2), U8.4 (A2)
Y3: J6.4, U2.6 (Q3), U3.15 (B3), U8.5 (A3)
Y4: J7.1, U3.14 (B4), U5.3 (Q0), U8.6 (A4)
Y5: J7.2, U3.13 (B5), U5.4 (Q1), U8.7 (A5)
Y6: J7.3, U3.12 (B6), U5.5 (Q2), U8.8 (A6)
Y7: J7.4, U3.11 (B7), U5.6 (Q3), U8.9 (A7)
~DE: J2.1, U6.1
~OE: J2.2, U3.19 (CE)
~SR_WR_EN: U2.9 (E1), U2.10 (E2), U5.9 (E1), U5.10 (E2), U6.3

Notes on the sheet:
8Bit Status Register
Bypass Capacitors
Registers
Mounting holes
Data LED's
Test Headers
Data Write Logic
CTRL connectors
Transciever

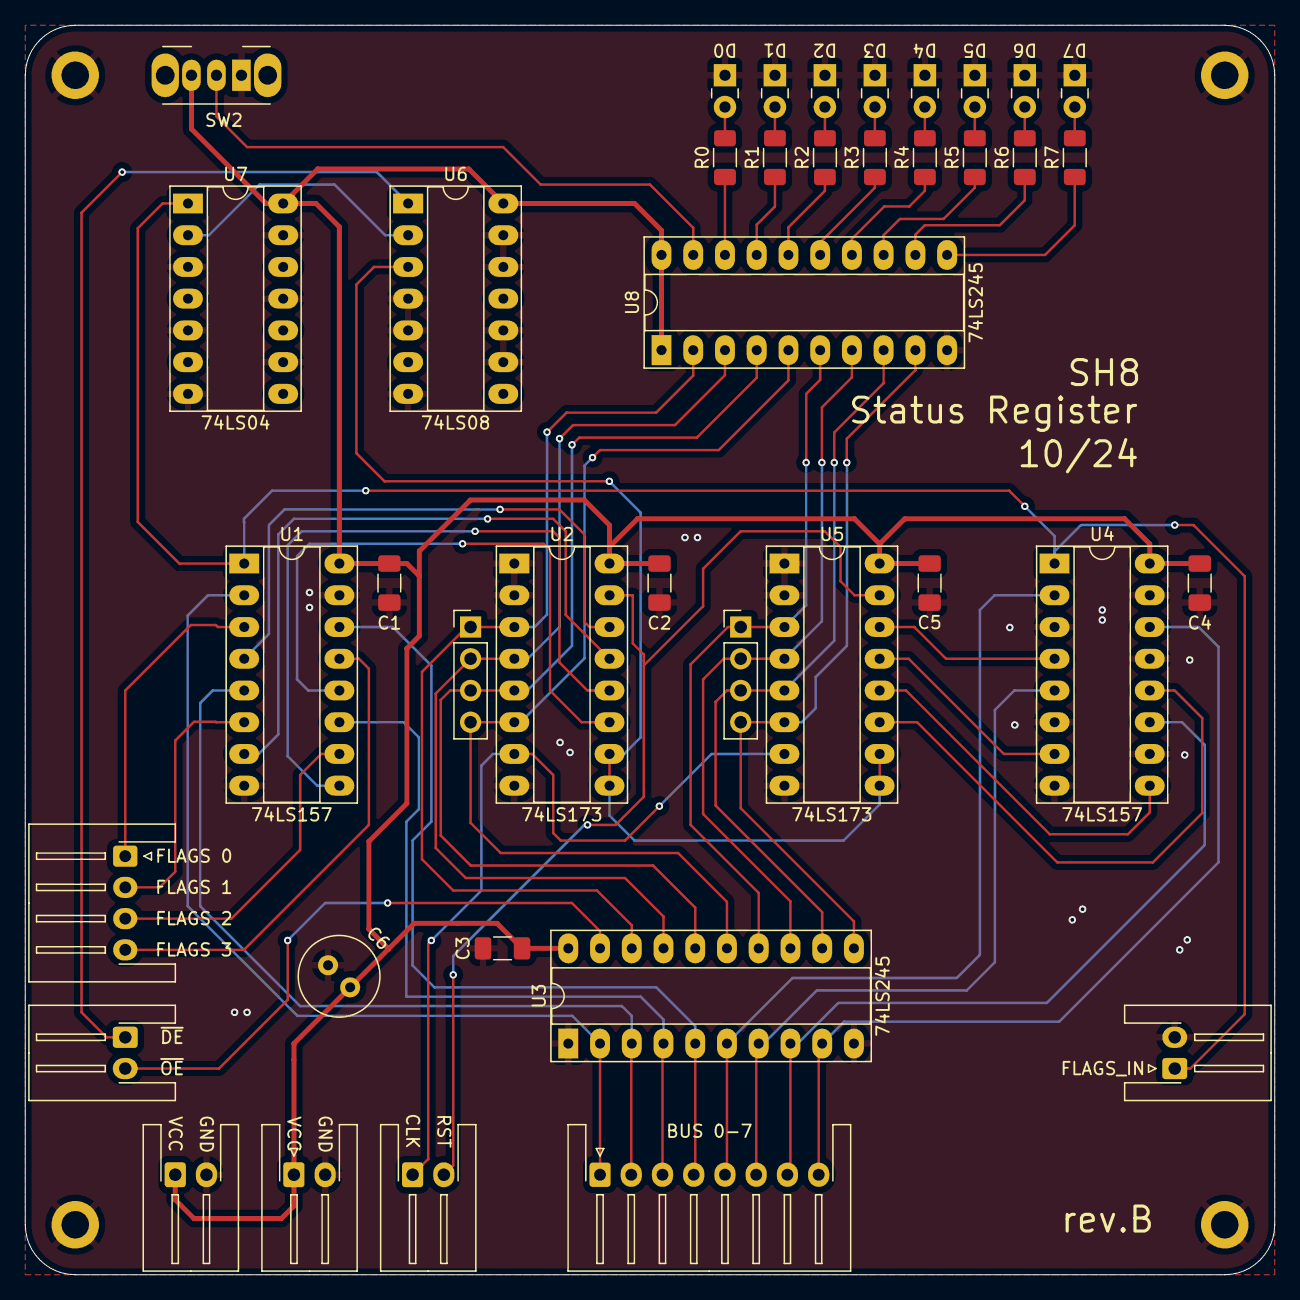
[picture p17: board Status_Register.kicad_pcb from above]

Board: 2 copper layers, 100.0 x 100.0 mm, 44 parts (0 on the bottom side), 54 nets.

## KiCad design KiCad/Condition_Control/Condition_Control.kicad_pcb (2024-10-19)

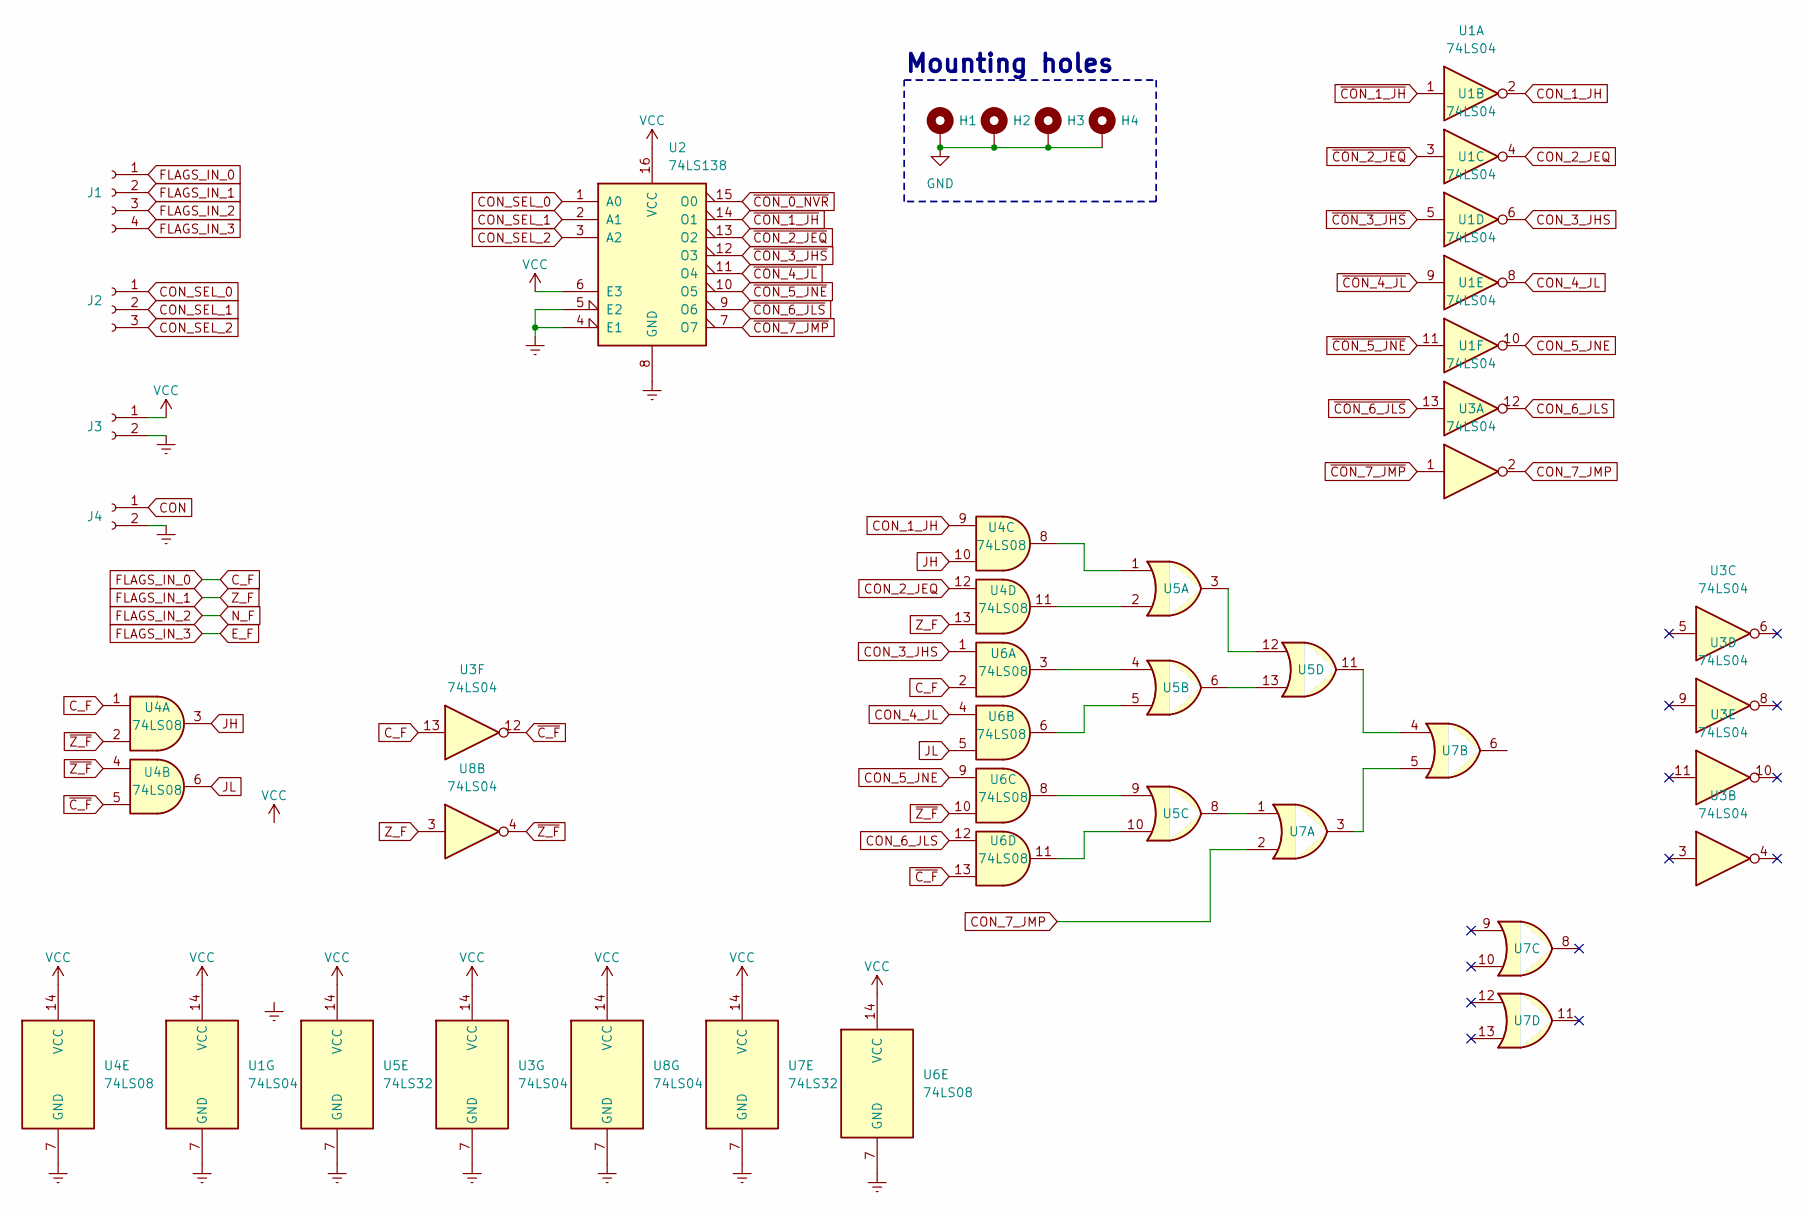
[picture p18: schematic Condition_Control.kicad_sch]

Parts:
H1, H2, H3, H4: MountingHole_Pad; MountingHole_2.2mm_M2_DIN965_Pad
J1: Conn_01x04_Socket; JST_XH_S4B-XH-A-1_1x04_P2.50mm_Horizontal
J2: Conn_01x03_Socket; JST_XH_S3B-XH-A-1_1x03_P2.50mm_Horizontal
J3, J4: Conn_01x02_Socket; JST_XH_S2B-XH-A-1_1x02_P2.50mm_Horizontal
U1, U3, U8: 74LS04; DIP-14_W7.62mm_Socket_LongPads
U2: 74LS138; DIP-16_W7.62mm_Socket_LongPads
U4, U6: 74LS08; DIP-14_W7.62mm_Socket_LongPads
U5, U7: 74LS32; DIP-14_W7.62mm_Socket_LongPads

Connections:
CON: J4.1
CON_1_JH: U1.2, U4.9
CON_2_JEQ: U1.4, U4.12
CON_3_JHS: U1.6, U6.1
CON_4_JL: U1.8, U6.4
CON_5_JNE: U1.10, U6.9
CON_6_JLS: U1.12, U6.12
CON_7_JMP: U3.2, U7.2
CON_SEL_0: J2.1, U2.1 (A0)
CON_SEL_1: J2.2, U2.2 (A1)
CON_SEL_2: J2.3, U2.3 (A2)
C_F: J1.1, U3.13, U4.1, U6.2
E_F: J1.4
FLAGS_IN_1: J1.2, U4.13, U8.3
FLAGS_IN_2: J1.3
GND: H1.1, H2.1, H3.1, H4.1, J3.2, J4.2, U1.7 (GND), U2.4 (E1), U2.5 (E2), U2.8 (GND), U3.7 (GND), U4.7 (GND), U5.7 (GND), U6.7 (GND), U7.7 (GND), U8.7 (GND)
JH: U4.3, U4.10
JL: U4.6, U6.5
unnamed: U4.8, U5.1
unnamed: U4.11, U5.2
unnamed: U5.4, U6.3
unnamed: U5.5, U6.6
unnamed: U5.8, U7.1
unnamed: U5.9, U6.8
unnamed: U5.10, U6.11
unnamed: U5.11, U7.4
unnamed: U5.3, U5.12
unnamed: U5.6, U5.13
unnamed: U7.3, U7.5
VCC: J3.1, U1.14 (VCC), U2.6 (E3), U2.16 (VCC), U3.14 (VCC), U4.14 (VCC), U5.14 (VCC), U6.14 (VCC), U7.14 (VCC), U8.14 (VCC)
~CON_0_NVR: U2.15 (O0)
~CON_1_JH: U1.1, U2.14 (O1)
~CON_2_JEQ: U1.3, U2.13 (O2)
~CON_3_JHS: U1.5, U2.12 (O3)
~CON_4_JL: U1.9, U2.11 (O4)
~CON_5_JNE: U1.11, U2.10 (O5)
~CON_6_JLS: U1.13, U2.9 (O6)
~CON_7_JMP: U2.7 (O7), U3.1
~C_F: U3.12, U4.5, U6.13
~Z_F: U4.2, U4.4, U6.10, U8.4

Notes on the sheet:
Mounting holes

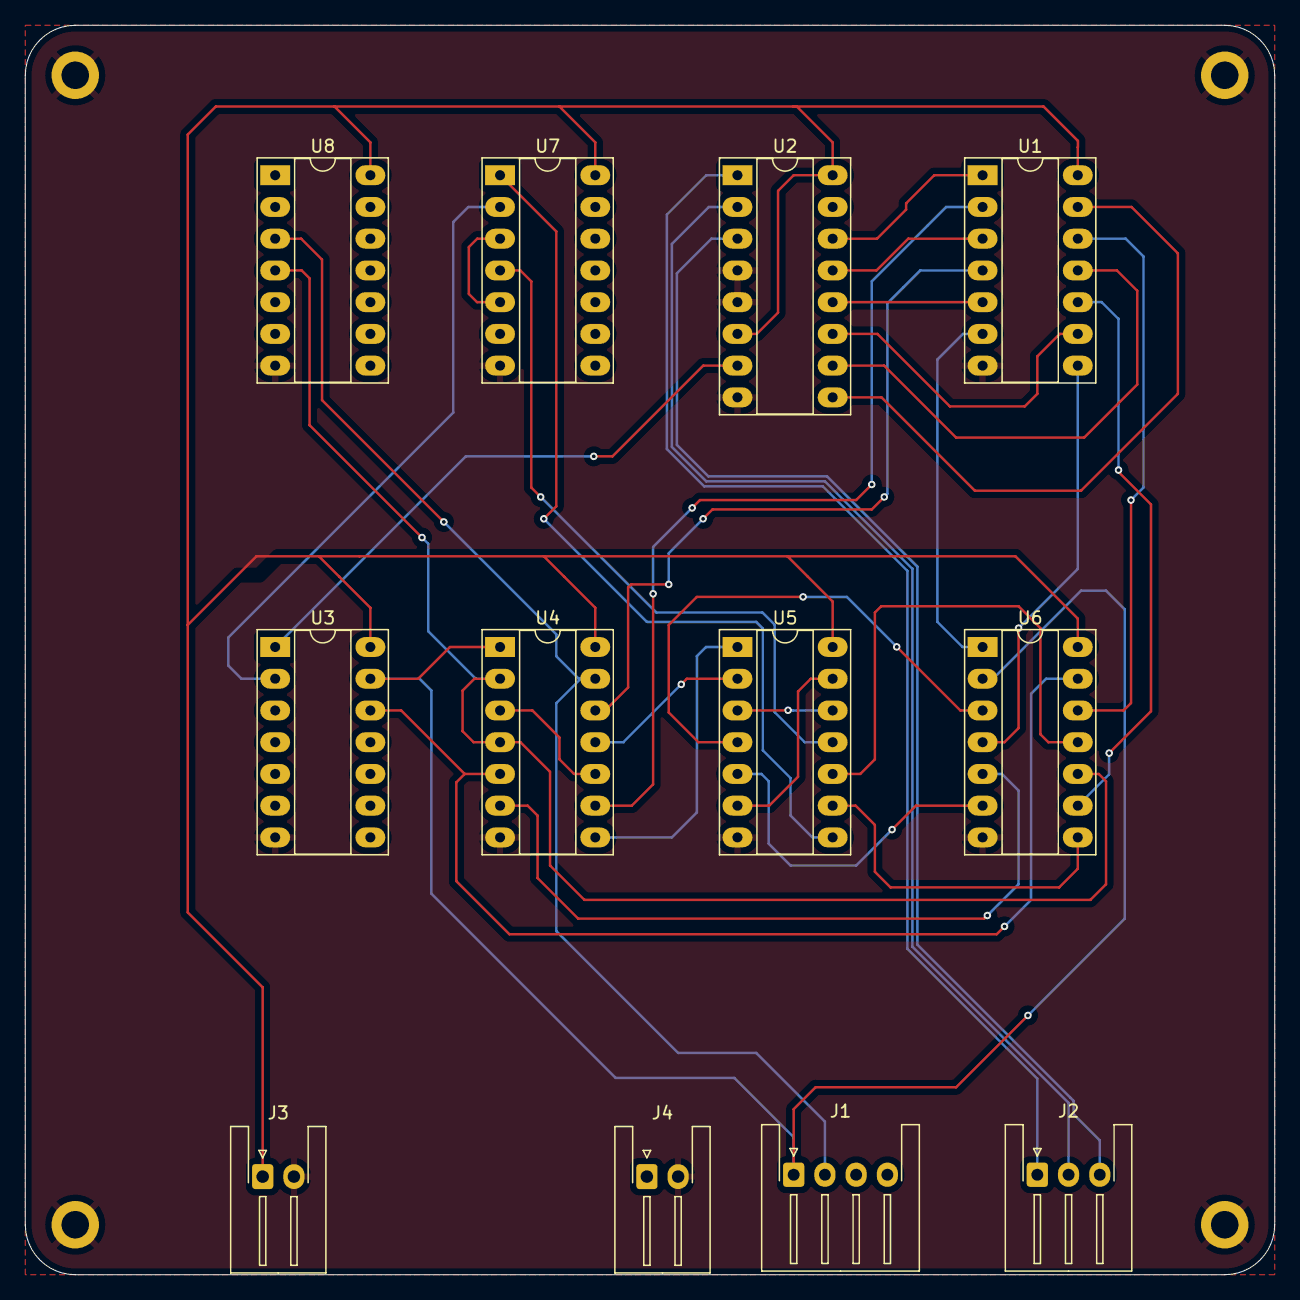
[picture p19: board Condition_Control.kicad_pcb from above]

Board: 2 copper layers, 100.0 x 100.0 mm, 16 parts (0 on the bottom side), 36 nets.

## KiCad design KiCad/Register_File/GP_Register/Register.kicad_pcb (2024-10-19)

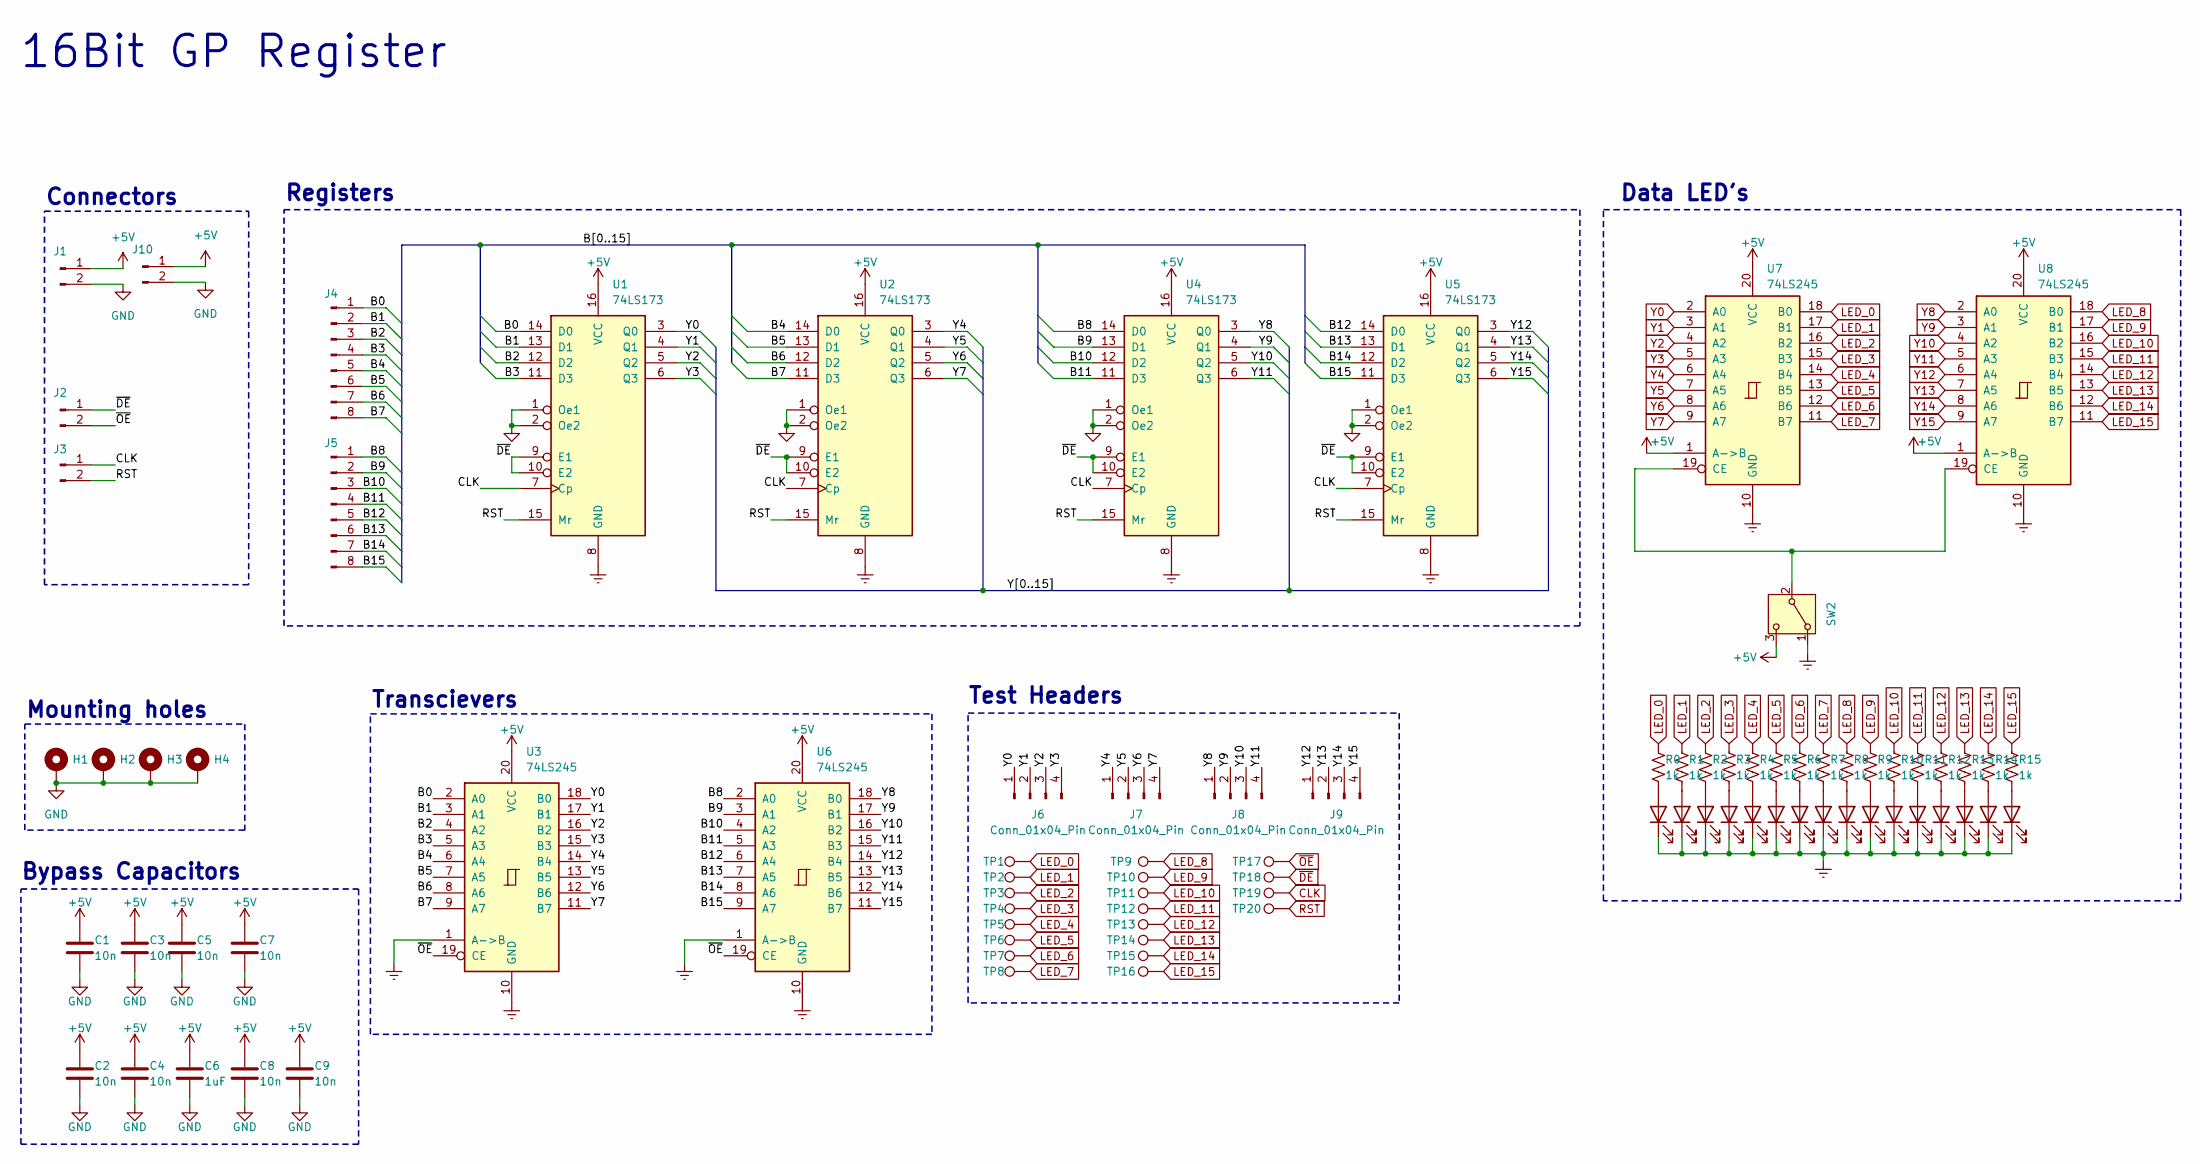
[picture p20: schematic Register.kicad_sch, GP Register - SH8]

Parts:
C1, C2, C3, C4, C5, C7, C8, C9: 10n; C_1206_3216Metric_Pad1.33x1.80mm_HandSolder
C6: 1uF; C_Radial_D6.3mm_H11.0mm_P2.50mm
D0, D1, D2, D3, D4, D5, D6, D7, D8, D9, D10, D11, D12, D13, D14, D15: LED; LED_Rectangular_W3.0mm_H2.0mm
H1, H2, H3, H4: MountingHole_Pad; MountingHole_2.2mm_M2_DIN965_Pad
J1, J2, J3, J10: Conn_01x02_Pin; JST_XH_S2B-XH-A-1_1x02_P2.50mm_Horizontal_fixed
J4, J5: Conn_01x08_Pin; JST_XH_S8B-XH-A-1_1x08_P2.50mm_Horizontal
J6, J7, J8, J9: Conn_01x04_Pin; PinHeader_1x04_P2.54mm_Vertical
R0, R1, R2, R3, R4, R5, R6, R7, R8, R9, R10, R11, R12, R13, R14, R15: 1k; R_1206_3216Metric_Pad1.30x1.75mm_HandSolder
SW2: SW_SPDT; SW_Slide_SPDT_Angled_CK_OS102011MA1Q
TP1, TP2, TP3, TP4, TP5, TP6, TP7, TP8, TP9, TP10, TP11, TP12, TP13, TP14, TP15, TP16, TP17, TP18, TP19, TP20: TestPoint; TestPoint_Pad_D1.0mm
U1, U2, U4, U5: 74LS173; DIP-16_W7.62mm_Socket_LongPads
U3, U6, U7, U8: 74LS245; DIP-20_W7.62mm_Socket_LongPads

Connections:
+5V: C1.1, C2.1, C3.1, C4.1, C5.1, C6.1, C7.1, C8.1, C9.1, J1.1, J10.1, SW2.3 (C), U1.16 (VCC), U2.16 (VCC), U3.20 (VCC), U4.16 (VCC), U5.16 (VCC), U6.20 (VCC), U7.1 (A->B), U7.20 (VCC), U8.1 (A->B), U8.20 (VCC)
/B0: J4.1, U1.14 (D0), U3.2 (A0)
/B1: J4.2, U1.13 (D1), U3.3 (A1)
/B2: J4.3, U1.12 (D2), U3.4 (A2)
/B3: J4.4, U1.11 (D3), U3.5 (A3)
/B4: J4.5, U2.14 (D0), U3.6 (A4)
/B5: J4.6, U2.13 (D1), U3.7 (A5)
/B6: J4.7, U2.12 (D2), U3.8 (A6)
/B7: J4.8, U2.11 (D3), U3.9 (A7)
/B8: J5.1, U4.14 (D0), U6.2 (A0)
/B9: J5.2, U4.13 (D1), U6.3 (A1)
/B10: J5.3, U4.12 (D2), U6.4 (A2)
/B11: J5.4, U4.11 (D3), U6.5 (A3)
/B12: J5.5, U5.14 (D0), U6.6 (A4)
/B13: J5.6, U5.13 (D1), U6.7 (A5)
/B14: J5.7, U5.12 (D2), U6.8 (A6)
/B15: J5.8, U5.11 (D3), U6.9 (A7)
CLK: J3.1, TP19.1, U1.7 (Cp), U2.7 (Cp), U4.7 (Cp), U5.7 (Cp)
GND: C1.2, C2.2, C3.2, C4.2, C5.2, C6.2, C7.2, C8.2, C9.2, D0.1 (K), D1.1 (K), D2.1 (K), D3.1 (K), D4.1 (K), D5.1 (K), D6.1 (K), D7.1 (K), D8.1 (K), D9.1 (K), D10.1 (K), D11.1 (K), D12.1 (K), D13.1 (K), D14.1 (K), D15.1 (K), H1.1, H2.1, H3.1, H4.1, J1.2, J10.2, SW2.1 (A), U1.1 (Oe1), U1.2 (Oe2), U1.8 (GND), U2.1 (Oe1), U2.2 (Oe2), U2.8 (GND), U3.1 (A->B), U3.10 (GND), U4.1 (Oe1), U4.2 (Oe2), U4.8 (GND), U5.1 (Oe1), U5.2 (Oe2), U5.8 (GND), U6.1 (A->B), U6.10 (GND), U7.10 (GND), U8.10 (GND)
LED_0: R0.1, TP1.1, U7.18 (B0)
LED_1: R1.1, TP2.1, U7.17 (B1)
LED_2: R2.1, TP3.1, U7.16 (B2)
LED_3: R3.1, TP4.1, U7.15 (B3)
LED_4: R4.1, TP5.1, U7.14 (B4)
LED_5: R5.1, TP6.1, U7.13 (B5)
LED_6: R6.1, TP7.1, U7.12 (B6)
LED_7: R7.1, TP8.1, U7.11 (B7)
LED_8: R8.1, TP9.1, U8.18 (B0)
LED_9: R9.1, TP10.1, U8.17 (B1)
LED_10: R10.1, TP11.1, U8.16 (B2)
LED_11: R11.1, TP12.1, U8.15 (B3)
LED_12: R12.1, TP13.1, U8.14 (B4)
LED_13: R13.1, TP14.1, U8.13 (B5)
LED_14: R14.1, TP15.1, U8.12 (B6)
LED_15: R15.1, TP16.1, U8.11 (B7)
unnamed: D0.2 (A), R0.2
unnamed: D1.2 (A), R1.2
unnamed: D2.2 (A), R2.2
unnamed: D3.2 (A), R3.2
unnamed: D4.2 (A), R4.2
unnamed: D5.2 (A), R5.2
unnamed: D6.2 (A), R6.2
unnamed: D7.2 (A), R7.2
unnamed: D8.2 (A), R8.2
unnamed: D9.2 (A), R9.2
unnamed: D10.2 (A), R10.2
unnamed: D11.2 (A), R11.2
unnamed: D12.2 (A), R12.2
unnamed: D13.2 (A), R13.2
unnamed: D14.2 (A), R14.2
unnamed: D15.2 (A), R15.2
unnamed: SW2.2 (B), U7.19 (CE), U8.19 (CE)
RST: J3.2, TP20.1, U1.15 (Mr), U2.15 (Mr), U4.15 (Mr), U5.15 (Mr)
Y0: J6.1, U1.3 (Q0), U3.18 (B0), U7.2 (A0)
Y1: J6.2, U1.4 (Q1), U3.17 (B1), U7.3 (A1)
Y2: J6.3, U1.5 (Q2), U3.16 (B2), U7.4 (A2)
Y3: J6.4, U1.6 (Q3), U3.15 (B3), U7.5 (A3)
Y4: J7.1, U2.3 (Q0), U3.14 (B4), U7.6 (A4)
Y5: J7.2, U2.4 (Q1), U3.13 (B5), U7.7 (A5)
Y6: J7.3, U2.5 (Q2), U3.12 (B6), U7.8 (A6)
Y7: J7.4, U2.6 (Q3), U3.11 (B7), U7.9 (A7)
Y8: J8.1, U4.3 (Q0), U6.18 (B0), U8.2 (A0)
Y9: J8.2, U4.4 (Q1), U6.17 (B1), U8.3 (A1)
Y10: J8.3, U4.5 (Q2), U6.16 (B2), U8.4 (A2)
Y11: J8.4, U4.6 (Q3), U6.15 (B3), U8.5 (A3)
Y12: J9.1, U5.3 (Q0), U6.14 (B4), U8.6 (A4)
Y13: J9.2, U5.4 (Q1), U6.13 (B5), U8.7 (A5)
Y14: J9.3, U5.5 (Q2), U6.12 (B6), U8.8 (A6)
Y15: J9.4, U5.6 (Q3), U6.11 (B7), U8.9 (A7)
~DE: J2.1, TP18.1, U1.9 (E1), U1.10 (E2), U2.9 (E1), U2.10 (E2), U4.9 (E1), U4.10 (E2), U5.9 (E1), U5.10 (E2)
~OE: J2.2, TP17.1, U3.19 (CE), U6.19 (CE)

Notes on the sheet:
16Bit GP Register
Data LED's
Bypass Capacitors
Registers
Mounting holes
Test Headers
Connectors
Transcievers

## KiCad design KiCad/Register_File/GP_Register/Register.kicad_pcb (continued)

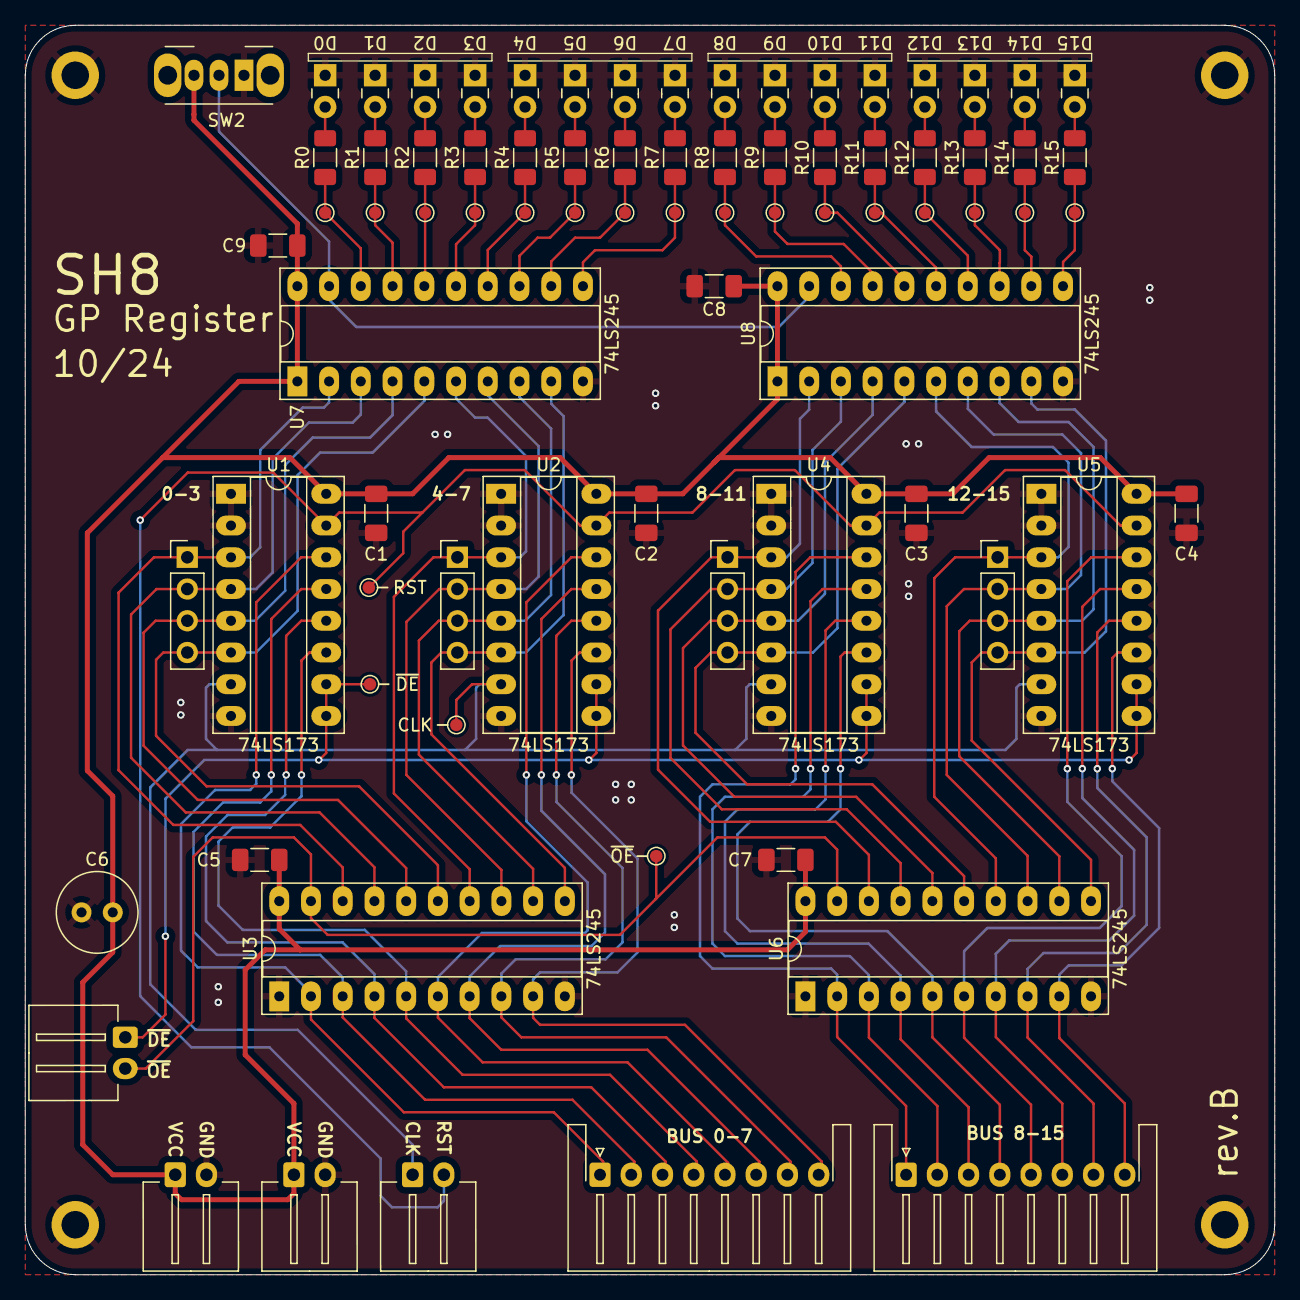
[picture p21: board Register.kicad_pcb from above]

Board: 2 copper layers, 100.0 x 100.0 mm, 84 parts (0 on the bottom side), 71 nets.

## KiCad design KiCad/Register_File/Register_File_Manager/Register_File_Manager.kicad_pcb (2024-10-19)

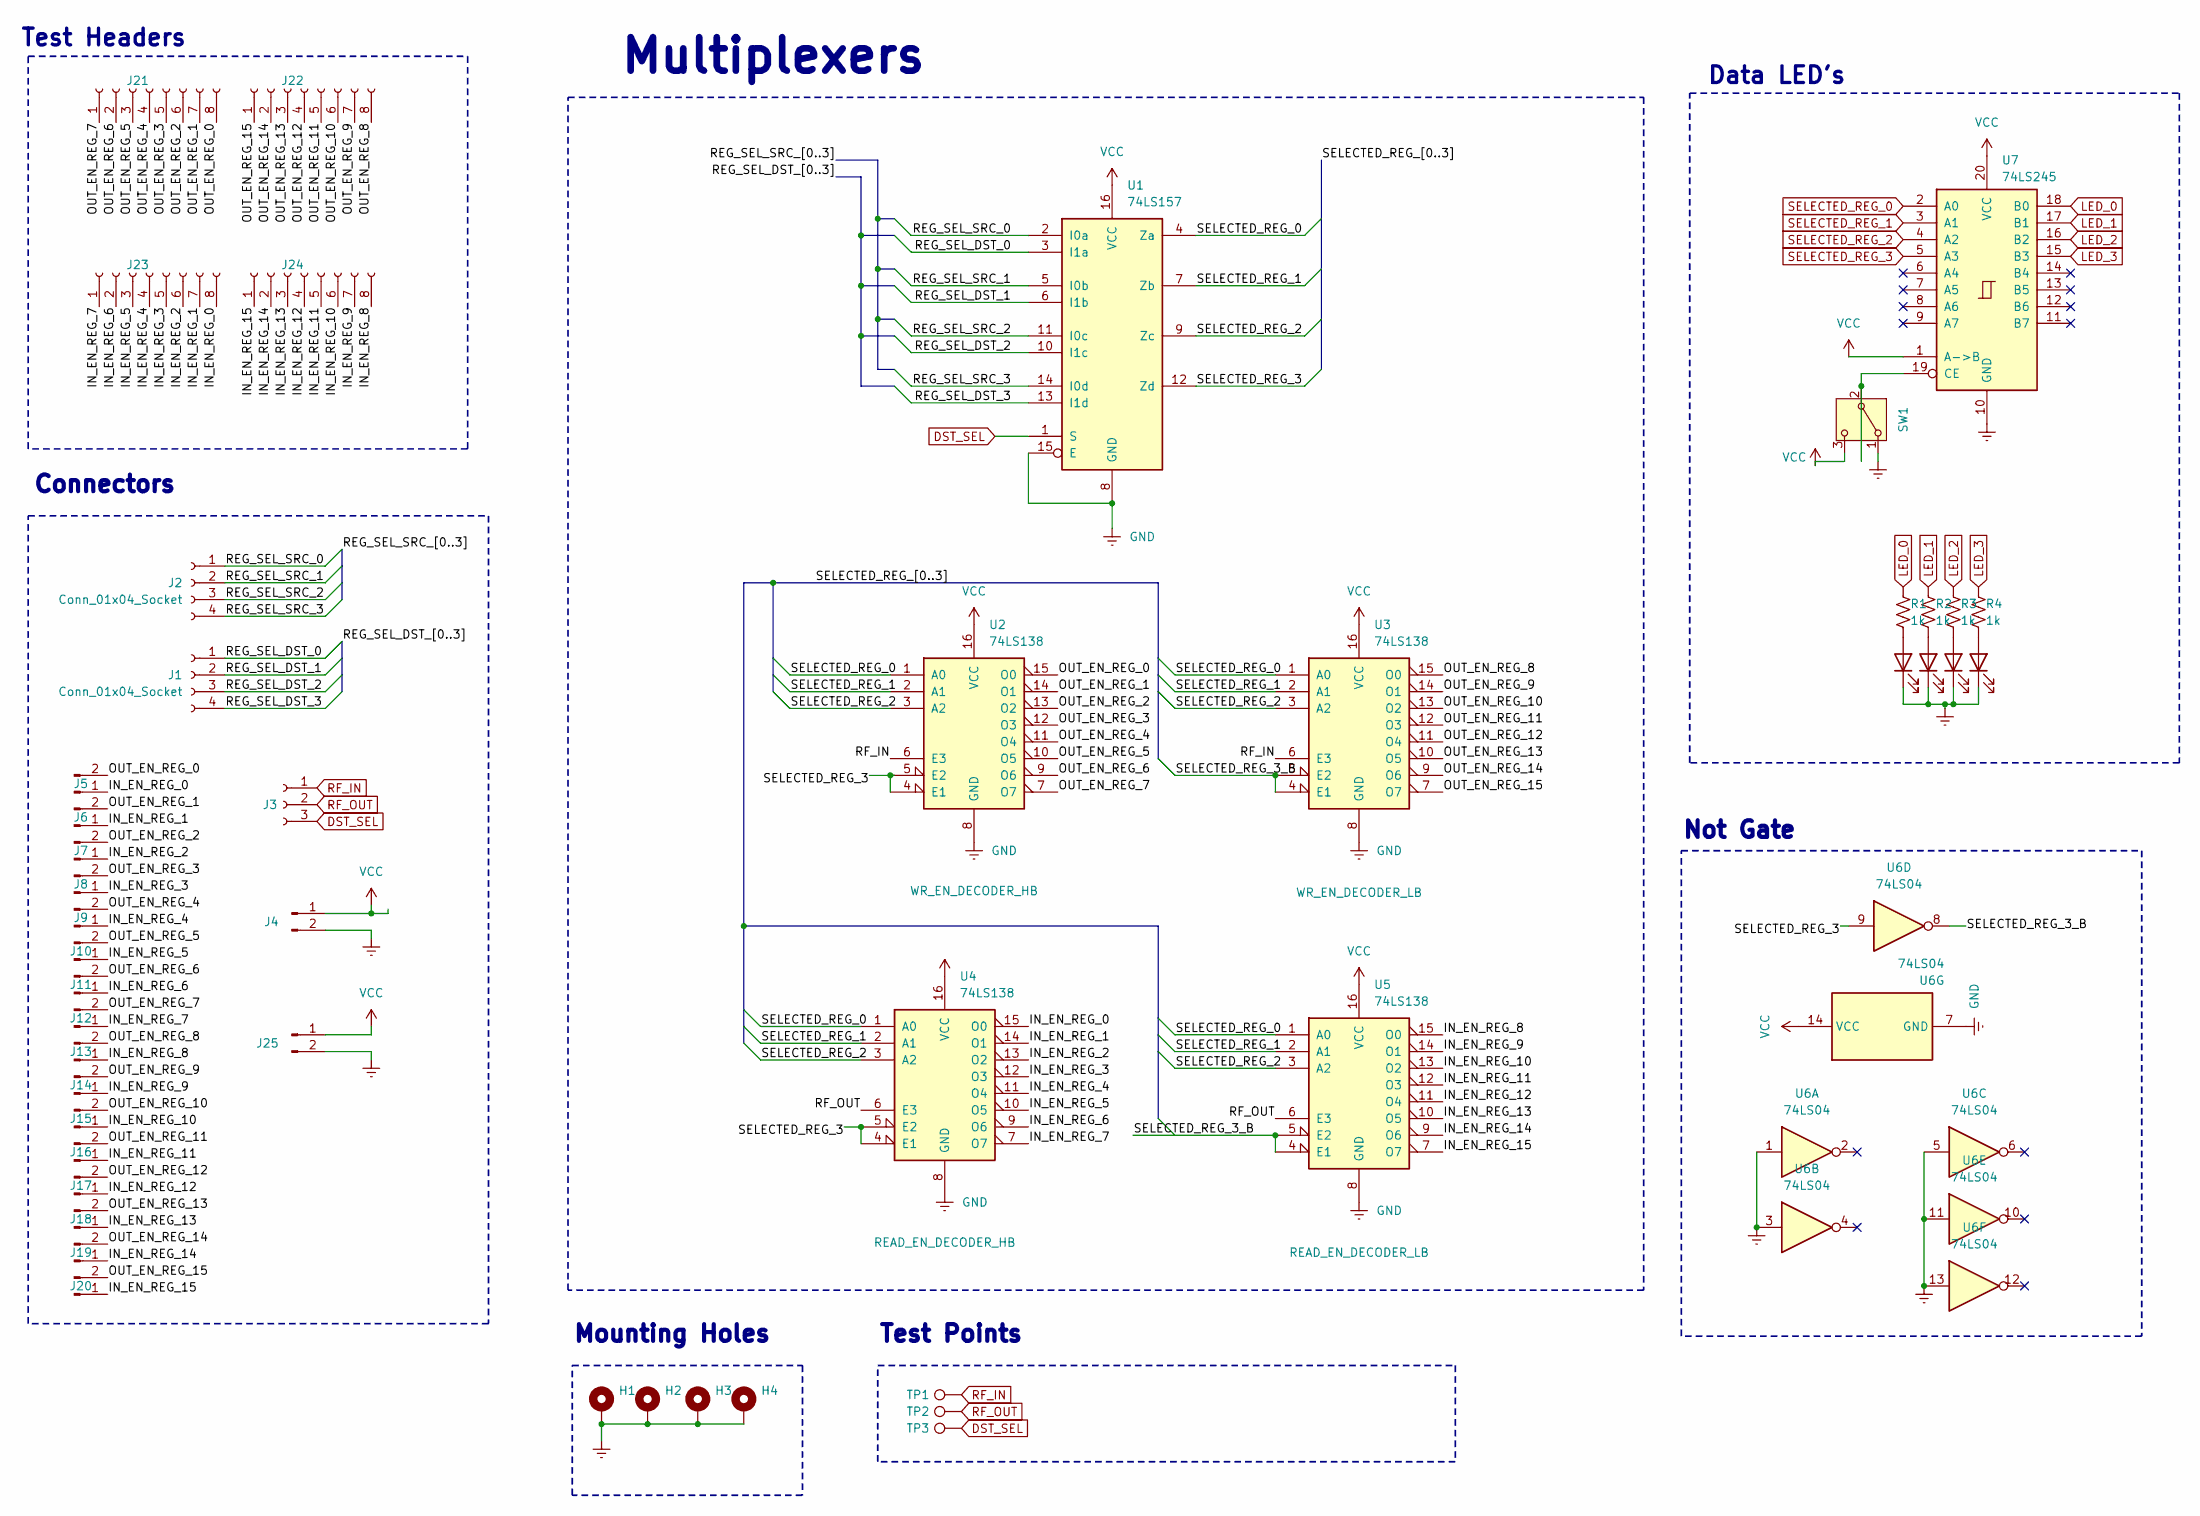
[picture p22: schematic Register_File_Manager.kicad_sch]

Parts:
D1, D2, D3, D4: LED; LED_Rectangular_W3.0mm_H2.0mm
H1, H2, H3, H4: MountingHole_Pad; MountingHole_2.2mm_M2_DIN965_Pad
J1, J2: Conn_01x04_Socket; JST_XH_S4B-XH-A-1_1x04_P2.50mm_Horizontal
J3: Conn_01x03_Socket; JST_XH_S3B-XH-A-1_1x03_P2.50mm_Horizontal
J4, J5, J6, J7, J8, J9, J10, J11, J12, J13, J14, J15, J16, J17, J18, J19, J20, J25: Conn_01x02_Socket; JST_XH_S2B-XH-A-1_1x02_P2.50mm_Horizontal
J21, J22, J23, J24: Conn_01x08_Socket; PinHeader_1x08_P2.54mm_Vertical
R1, R2, R3, R4: 1k; R_1206_3216Metric_Pad1.30x1.75mm_HandSolder
SW1: SW_SPDT; SW_Slide_SPDT_Angled_CK_OS102011MA1Q
TP1, TP2, TP3: TestPoint; TestPoint_Pad_D1.0mm
U1: 74LS157; DIP-16_W7.62mm_Socket_LongPads
U2, U3, U4, U5: 74LS138; DIP-16_W7.62mm_Socket_LongPads
U6: 74LS04
U7: 74LS245; DIP-20_W7.62mm_Socket_LongPads

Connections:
/IN_EN_REG_0: J5.1, J23.8, U4.15 (O0)
/IN_EN_REG_1: J6.1, J23.7, U4.14 (O1)
/IN_EN_REG_2: J7.1, J23.6, U4.13 (O2)
/IN_EN_REG_3: J8.1, J23.5, U4.12 (O3)
/IN_EN_REG_4: J9.1, J23.4, U4.11 (O4)
/IN_EN_REG_5: J10.1, J23.3, U4.10 (O5)
/IN_EN_REG_6: J11.1, J23.2, U4.9 (O6)
/IN_EN_REG_7: J12.1, J23.1, U4.7 (O7)
/IN_EN_REG_8: J13.1, J24.8, U5.15 (O0)
/IN_EN_REG_9: J14.1, J24.7, U5.14 (O1)
/IN_EN_REG_10: J15.1, J24.6, U5.13 (O2)
/IN_EN_REG_11: J16.1, J24.5, U5.12 (O3)
/IN_EN_REG_12: J17.1, J24.4, U5.11 (O4)
/IN_EN_REG_13: J18.1, J24.3, U5.10 (O5)
/IN_EN_REG_14: J19.1, J24.2, U5.9 (O6)
/IN_EN_REG_15: J20.1, J24.1, U5.7 (O7)
/OUT_EN_REG_0: J5.2, J21.8, U2.15 (O0)
/OUT_EN_REG_1: J6.2, J21.7, U2.14 (O1)
/OUT_EN_REG_2: J7.2, J21.6, U2.13 (O2)
/OUT_EN_REG_3: J8.2, J21.5, U2.12 (O3)
/OUT_EN_REG_4: J9.2, J21.4, U2.11 (O4)
/OUT_EN_REG_5: J10.2, J21.3, U2.10 (O5)
/OUT_EN_REG_6: J11.2, J21.2, U2.9 (O6)
/OUT_EN_REG_7: J12.2, J21.1, U2.7 (O7)
/OUT_EN_REG_8: J13.2, J22.8, U3.15 (O0)
/OUT_EN_REG_9: J14.2, J22.7, U3.14 (O1)
/OUT_EN_REG_10: J15.2, J22.6, U3.13 (O2)
/OUT_EN_REG_11: J16.2, J22.5, U3.12 (O3)
/OUT_EN_REG_12: J17.2, J22.4, U3.11 (O4)
/OUT_EN_REG_13: J18.2, J22.3, U3.10 (O5)
/OUT_EN_REG_14: J19.2, J22.2, U3.9 (O6)
/OUT_EN_REG_15: J20.2, J22.1, U3.7 (O7)
/REG_SEL_DST_0: J1.1, U1.3 (I1a)
/REG_SEL_DST_1: J1.2, U1.6 (I1b)
/REG_SEL_DST_2: J1.3, U1.10 (I1c)
/REG_SEL_DST_3: J1.4, U1.13 (I1d)
/REG_SEL_SRC_0: J2.1, U1.2 (I0a)
/REG_SEL_SRC_1: J2.2, U1.5 (I0b)
/REG_SEL_SRC_2: J2.3, U1.11 (I0c)
/REG_SEL_SRC_3: J2.4, U1.14 (I0d)
/SELECTED_REG_3_B: U3.4 (E1), U3.5 (E2), U5.4 (E1), U5.5 (E2), U6.8
DST_SEL: J3.3, TP3.1, U1.1 (S)
GND: D1.1 (K), D2.1 (K), D3.1 (K), D4.1 (K), H1.1, H2.1, H3.1, H4.1, J4.2, J25.2, SW1.1 (A), U1.8 (GND), U1.15 (E), U2.8 (GND), U3.8 (GND), U4.8 (GND), U5.8 (GND), U6.1, U6.3, U6.5, U6.7 (GND), U6.11, U6.13, U7.10 (GND)
LED_0: R1.1, U7.18 (B0)
LED_1: R2.1, U7.17 (B1)
LED_2: R3.1, U7.16 (B2)
LED_3: R4.1, U7.15 (B3)
unnamed: D1.2 (A), R1.2
unnamed: D2.2 (A), R2.2
unnamed: D3.2 (A), R3.2
unnamed: D4.2 (A), R4.2
unnamed: SW1.2 (B), U7.19 (CE)
RF_IN: J3.1, TP1.1, U2.6 (E3), U3.6 (E3)
RF_OUT: J3.2, TP2.1, U4.6 (E3), U5.6 (E3)
SELECTED_REG_0: U1.4 (Za), U2.1 (A0), U3.1 (A0), U4.1 (A0), U5.1 (A0), U7.2 (A0)
SELECTED_REG_1: U1.7 (Zb), U2.2 (A1), U3.2 (A1), U4.2 (A1), U5.2 (A1), U7.3 (A1)
SELECTED_REG_2: U1.9 (Zc), U2.3 (A2), U3.3 (A2), U4.3 (A2), U5.3 (A2), U7.4 (A2)
SELECTED_REG_3: U1.12 (Zd), U2.4 (E1), U2.5 (E2), U4.4 (E1), U4.5 (E2), U6.9, U7.5 (A3)
VCC: J4.1, J25.1, SW1.3 (C), U1.16 (VCC), U2.16 (VCC), U3.16 (VCC), U4.16 (VCC), U5.16 (VCC), U6.14 (VCC), U7.1 (A->B), U7.20 (VCC)

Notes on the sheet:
Connectors
Test Points
Mounting Holes
Test Headers
Multiplexers
Data LED's
Not Gate

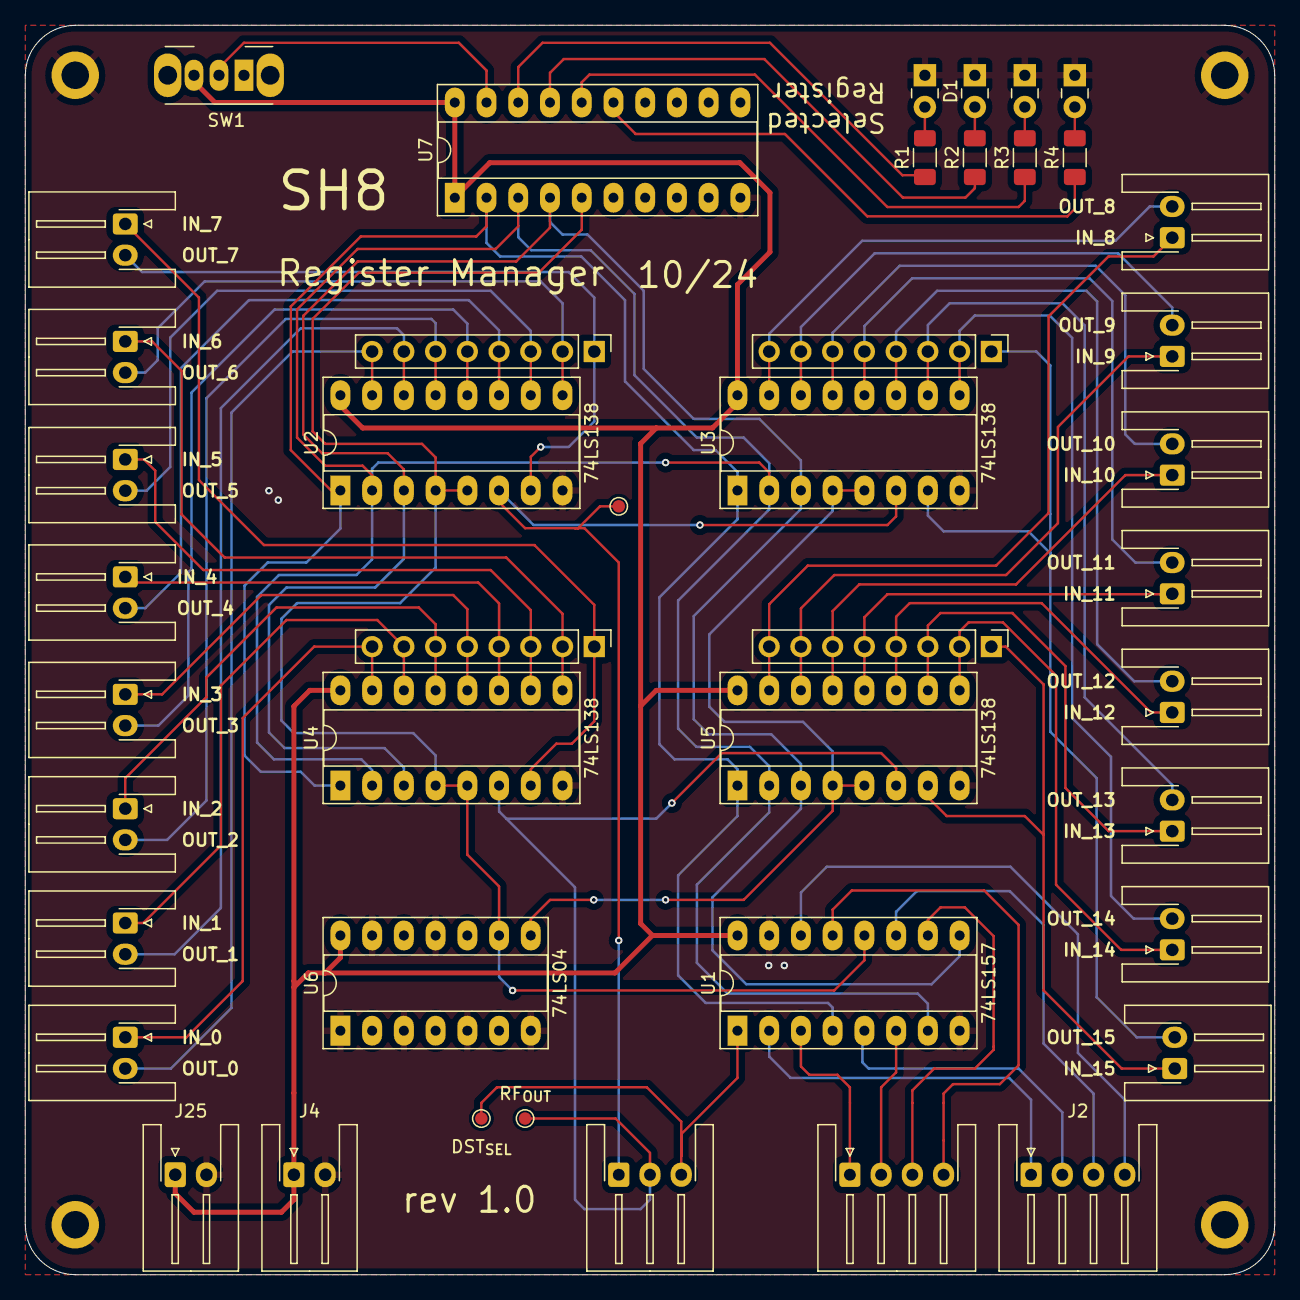
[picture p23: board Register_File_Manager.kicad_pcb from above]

Board: 2 copper layers, 100.0 x 100.0 mm, 48 parts (0 on the bottom side), 59 nets.

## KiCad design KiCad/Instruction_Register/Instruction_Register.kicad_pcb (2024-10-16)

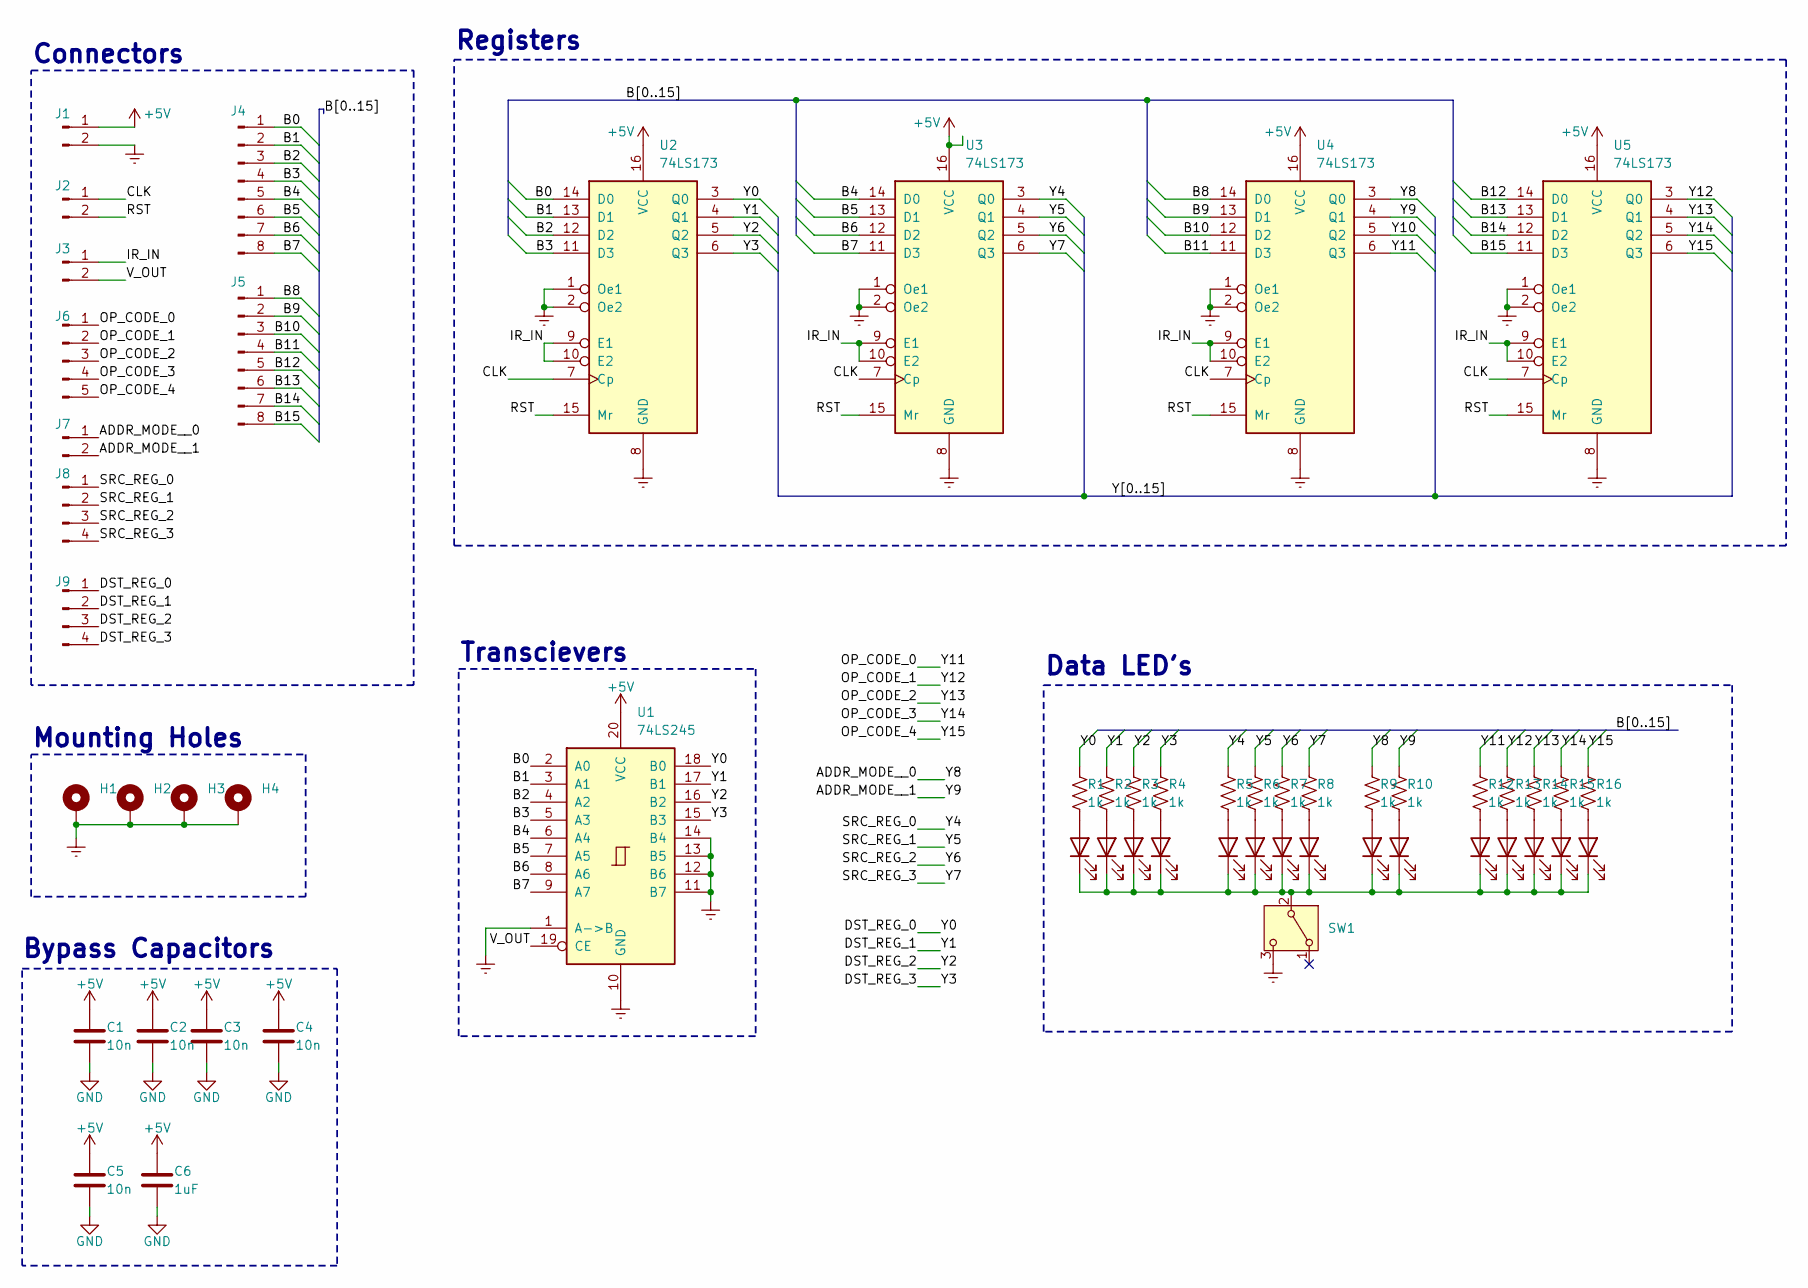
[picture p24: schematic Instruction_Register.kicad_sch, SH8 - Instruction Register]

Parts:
C1, C2, C3, C4, C5: 10n; C_Disc_D3.8mm_W2.6mm_P2.50mm
C6: 1uF; C_Radial_D6.3mm_H11.0mm_P2.50mm
D1, D2, D3, D4, D5, D6, D7, D8, D9, D10, D12, D13, D14, D15, D16: LED; LED_Rectangular_W3.0mm_H2.0mm
H1, H2, H3, H4: MountingHole_Pad; MountingHole_2.2mm_M2_DIN965_Pad
J1, J2, J3, J7: Conn_01x02_Pin; JST_XH_S2B-XH-A-1_1x02_P2.50mm_Horizontal
J4, J5: Conn_01x08_Pin; JST_XH_S8B-XH-A-1_1x08_P2.50mm_Horizontal
J6: Conn_01x05_Pin; JST_XH_S5B-XH-A-1_1x05_P2.50mm_Horizontal
J8, J9: Conn_01x04_Pin; JST_XH_S4B-XH-A-1_1x04_P2.50mm_Horizontal
R1, R2, R3, R4, R5, R6, R7, R8, R9, R10, R12, R13, R14, R15, R16: 1k; R_1206_3216Metric
SW1: SW_SPDT; SW_Slide_SPDT_Angled_CK_OS102011MA1Q
U1: 74LS245; DIP-20_W7.62mm_Socket_LongPads
U2, U3, U4, U5: 74LS173; DIP-16_W7.62mm_Socket_LongPads

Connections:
+5V: C1.1, C2.1, C3.1, C4.1, C5.1, C6.1, J1.1, U1.20 (VCC), U2.16 (VCC), U3.16 (VCC), U4.16 (VCC), U5.16 (VCC)
/B0: J4.1, U1.2 (A0), U2.14 (D0)
/B1: J4.2, U1.3 (A1), U2.13 (D1)
/B2: J4.3, U1.4 (A2), U2.12 (D2)
/B3: J4.4, U1.5 (A3), U2.11 (D3)
/B4: J4.5, U1.6 (A4), U3.14 (D0)
/B5: J4.6, U1.7 (A5), U3.13 (D1)
/B6: J4.7, U1.8 (A6), U3.12 (D2)
/B7: J4.8, U1.9 (A7), U3.11 (D3)
/B8: J5.1, U4.14 (D0)
/B9: J5.2, U4.13 (D1)
/B10: J5.3, U4.12 (D2)
/B11: J5.4, U4.11 (D3)
/B12: J5.5, U5.14 (D0)
/B13: J5.6, U5.13 (D1)
/B14: J5.7, U5.12 (D2)
/B15: J5.8, U5.11 (D3)
/CLK: J2.1, U2.7 (Cp), U3.7 (Cp), U4.7 (Cp), U5.7 (Cp)
/IR_IN: J3.1, U2.9 (E1), U2.10 (E2), U3.9 (E1), U3.10 (E2), U4.9 (E1), U4.10 (E2), U5.9 (E1), U5.10 (E2)
/RST: J2.2, U2.15 (Mr), U3.15 (Mr), U4.15 (Mr), U5.15 (Mr)
/V_OUT: J3.2, U1.19 (CE)
/Y0: J9.1, R1.1, U1.18 (B0), U2.3 (Q0)
/Y1: J9.2, R2.1, U1.17 (B1), U2.4 (Q1)
/Y2: J9.3, R3.1, U1.16 (B2), U2.5 (Q2)
/Y3: J9.4, R4.1, U1.15 (B3), U2.6 (Q3)
/Y4: J8.1, R5.1, U3.3 (Q0)
/Y5: J8.2, R6.1, U3.4 (Q1)
/Y6: J8.3, R7.1, U3.5 (Q2)
/Y7: J8.4, R8.1, U3.6 (Q3)
/Y8: J7.1, R9.1, U4.3 (Q0)
/Y9: J7.2, R10.1, U4.4 (Q1)
/Y10: U4.5 (Q2)
/Y11: J6.1, R12.1, U4.6 (Q3)
/Y12: J6.2, R13.1, U5.3 (Q0)
/Y13: J6.3, R14.1, U5.4 (Q1)
/Y14: J6.4, R15.1, U5.5 (Q2)
/Y15: J6.5, R16.1, U5.6 (Q3)
GND: C1.2, C2.2, C3.2, C4.2, C5.2, C6.2, H1.1, H2.1, H3.1, H4.1, J1.2, SW1.3 (C), U1.1 (A->B), U1.10 (GND), U1.11 (B7), U1.12 (B6), U1.13 (B5), U1.14 (B4), U2.1 (Oe1), U2.2 (Oe2), U2.8 (GND), U3.1 (Oe1), U3.2 (Oe2), U3.8 (GND), U4.1 (Oe1), U4.2 (Oe2), U4.8 (GND), U5.1 (Oe1), U5.2 (Oe2), U5.8 (GND)
unnamed: D1.2 (A), R1.2
unnamed: D1.1 (K), D2.1 (K), D3.1 (K), D4.1 (K), D5.1 (K), D6.1 (K), D7.1 (K), D8.1 (K), D9.1 (K), D10.1 (K), D12.1 (K), D13.1 (K), D14.1 (K), D15.1 (K), D16.1 (K), SW1.2 (B)
unnamed: D2.2 (A), R2.2
unnamed: D3.2 (A), R3.2
unnamed: D4.2 (A), R4.2
unnamed: D5.2 (A), R5.2
unnamed: D6.2 (A), R6.2
unnamed: D7.2 (A), R7.2
unnamed: D8.2 (A), R8.2
unnamed: D9.2 (A), R9.2
unnamed: D10.2 (A), R10.2
unnamed: D12.2 (A), R12.2
unnamed: D13.2 (A), R13.2
unnamed: D14.2 (A), R14.2
unnamed: D15.2 (A), R15.2
unnamed: D16.2 (A), R16.2

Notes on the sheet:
Connectors
Mounting Holes
Data LED's
Bypass Capacitors
Transcievers
Registers

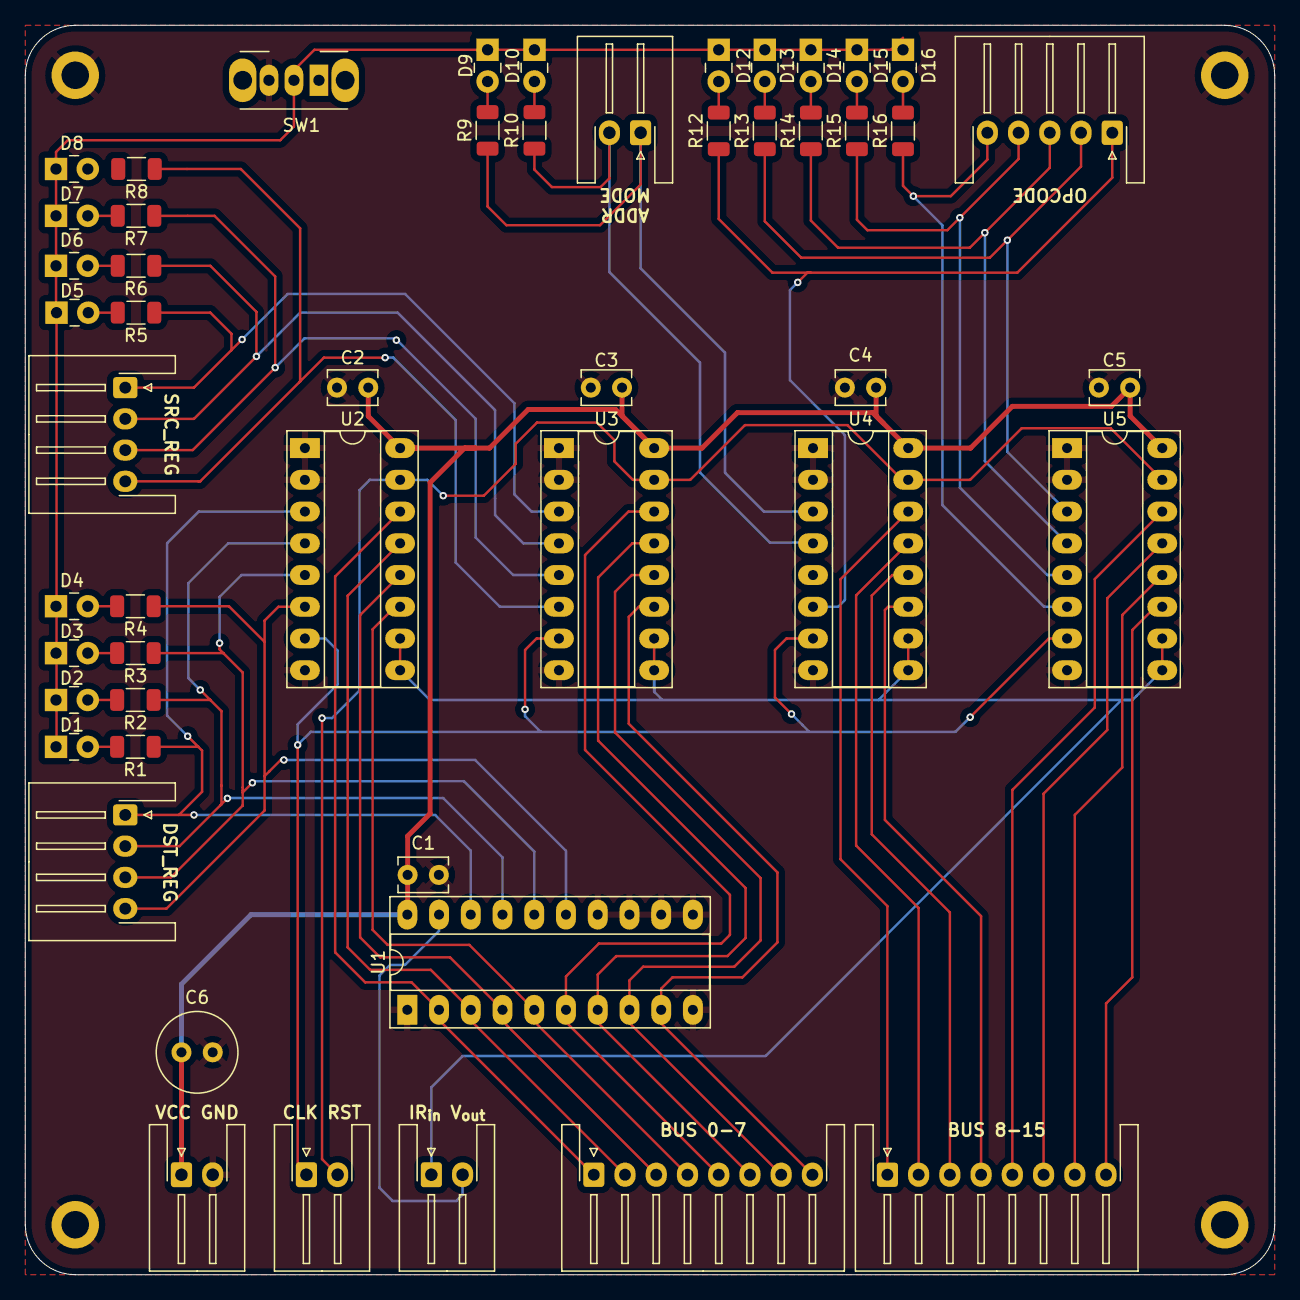
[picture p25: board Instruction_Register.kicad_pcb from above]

Board: 2 copper layers, 100.0 x 100.0 mm, 55 parts (0 on the bottom side), 53 nets.

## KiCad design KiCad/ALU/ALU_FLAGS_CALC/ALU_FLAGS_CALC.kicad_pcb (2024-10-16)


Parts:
D1, D2, D3, D4, D5, D6, D7, D8, D9, D10, D11, D12, D13, D14, D15, D16: LED; LED_Rectangular_W3.0mm_H2.0mm
H1, H2, H3, H4: MountingHole_Pad; MountingHole_2.2mm_M2_DIN965_Pad
J1, J3, J8: Conn_01x02_Socket; JST_XH_S2B-XH-A-1_1x02_P2.50mm_Horizontal
J2, J5, J6, J7: Conn_01x08_Socket; jst_xh_s8b_smd
J4: Conn_01x04_Socket; JST_XH_S4B-XH-A-1_1x04_P2.50mm_Horizontal
R1, R2, R3, R4, R5, R6, R7, R8, R9, R10, R11, R12, R13, R14, R15, R16: 1k; R_1206_3216Metric_Pad1.30x1.75mm_HandSolder
SW1: SW_SPDT; SW_Slide_SPDT_Angled_CK_OS102011MA1Q
U1, U2: 74LS245; DIP-20_W7.62mm_Socket_LongPads
U3: 74LS04; DIP-14_W7.62mm_Socket_LongPads
U4, U5: 74LS02; DIP-14_W7.62mm_Socket_LongPads
U6, U7: 74LS08; DIP-14_W7.62mm_Socket_LongPads

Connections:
ALU_C_OUT: J3.1, U3.1
C_FL: J4.1, U3.2
E_FL: J4.4, U3.4
F_0: J2.8, J5.1, U1.2 (A0), U3.3, U4.2
F_1: J2.7, J5.2, U1.3 (A1), U4.3
F_2: J2.6, J5.3, U1.4 (A2), U4.5
F_3: J2.5, J5.4, U1.5 (A3), U4.6
F_4: J2.4, J5.5, U1.6 (A4), U4.8
F_5: J2.3, J5.6, U1.7 (A5), U4.9
F_6: J2.2, J5.7, U1.8 (A6), U4.11
F_7: J2.1, J5.8, U1.9 (A7), U4.12
F_8: J6.1, J7.8, U2.2 (A0), U5.2
F_9: J6.2, J7.7, U2.3 (A1), U5.3
F_10: J6.3, J7.6, U2.4 (A2), U5.5
F_11: J6.4, J7.5, U2.5 (A3), U5.6
F_12: J6.5, J7.4, U2.6 (A4), U5.8
F_13: J6.6, J7.3, U2.7 (A5), U5.9
F_14: J6.7, J7.2, U2.8 (A6), U5.11
F_15: J4.3, J6.8, J7.1, U2.9 (A7), U5.12
GND: D1.1 (K), D2.1 (K), D3.1 (K), D4.1 (K), D5.1 (K), D6.1 (K), D7.1 (K), D8.1 (K), D9.1 (K), D10.1 (K), D11.1 (K), D12.1 (K), D13.1 (K), D14.1 (K), D15.1 (K), D16.1 (K), H1.1, H2.1, H3.1, H4.1, J1.2, J3.2, J8.2, SW1.1 (A), U1.10 (GND), U2.10 (GND), U3.7 (GND), U4.7 (GND), U5.7 (GND), U6.7 (GND), U7.7 (GND)
LED_0: R1.1, U1.18 (B0)
LED_1: R2.1, U1.17 (B1)
LED_2: R3.1, U1.16 (B2)
LED_3: R4.1, U1.15 (B3)
LED_4: R5.1, U1.14 (B4)
LED_5: R6.1, U1.13 (B5)
LED_6: R7.1, U1.12 (B6)
LED_7: R8.1, U1.11 (B7)
LED_8: R9.1, U2.18 (B0)
LED_9: R10.1, U2.17 (B1)
LED_10: R11.1, U2.16 (B2)
LED_11: R12.1, U2.15 (B3)
LED_12: R13.1, U2.14 (B4)
LED_13: R14.1, U2.13 (B5)
LED_14: R15.1, U2.12 (B6)
LED_15: R16.1, U2.11 (B7)
unnamed: D1.2 (A), R1.2
unnamed: D2.2 (A), R2.2
unnamed: D3.2 (A), R3.2
unnamed: D4.2 (A), R4.2
unnamed: D5.2 (A), R5.2
unnamed: D6.2 (A), R6.2
unnamed: D7.2 (A), R7.2
unnamed: D8.2 (A), R8.2
unnamed: D9.2 (A), R9.2
unnamed: D10.2 (A), R10.2
unnamed: D11.2 (A), R11.2
unnamed: D12.2 (A), R12.2
unnamed: D13.2 (A), R13.2
unnamed: D14.2 (A), R14.2
unnamed: D15.2 (A), R15.2
unnamed: D16.2 (A), R16.2
unnamed: SW1.2 (B), U1.19 (CE), U2.19 (CE)
unnamed: U4.1, U6.1
unnamed: U4.4, U6.2
unnamed: U4.10, U6.4
unnamed: U4.13, U6.5
unnamed: U5.1, U6.9
unnamed: U5.4, U6.10
unnamed: U5.10, U6.12
unnamed: U5.13, U6.13
unnamed: U6.3, U7.1
unnamed: U6.6, U7.2
unnamed: U6.8, U7.4
unnamed: U6.11, U7.5
unnamed: U7.3, U7.9
unnamed: U7.6, U7.10
VCC: J1.1, J8.1, SW1.3 (C), U1.1 (A->B), U1.20 (VCC), U2.1 (A->B), U2.20 (VCC), U3.5, U3.9, U3.11, U3.13, U3.14 (VCC), U4.14 (VCC), U5.14 (VCC), U6.14 (VCC), U7.12, U7.13, U7.14 (VCC)
Z_FL: J4.2, U7.8

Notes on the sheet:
Data LED's
Mounting holes

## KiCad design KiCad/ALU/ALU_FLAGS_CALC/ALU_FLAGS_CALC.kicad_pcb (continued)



Board: 2 copper layers, 100.0 x 100.0 mm, 52 parts (2 on the bottom side), 69 nets.

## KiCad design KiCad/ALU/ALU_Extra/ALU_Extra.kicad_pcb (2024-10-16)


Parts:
C1, C2, C3, C4: C; C_Disc_D3.8mm_W2.6mm_P2.50mm
D1, D2, D3: LED; LED_2512_6332Metric_Pad1.52x3.35mm_HandSolder
H1, H2, H3, H4: MountingHole_Pad; MountingHole_2.2mm_M2_DIN965_Pad
J1, J2, J4, J7: Conn_01x02_Socket; JST_XH_S2B-XH-A-1_1x02_P2.50mm_Horizontal
J3, J5: Conn_01x04_Socket; JST_XH_S4B-XH-A-1_1x04_P2.50mm_Horizontal
J8: Conn_01x03_Socket; JST_XH_S3B-XH-A-1_1x03_P2.50mm_Horizontal
R1, R2, R3: R_US; R_1206_3216Metric_Pad1.30x1.75mm_HandSolder
U1: AT28C16-15PC; DIP-24_W15.24mm_LongPads
U2: 74LS08; DIP-14_W7.62mm_Socket_LongPads
U3: 74LS04; DIP-14_W7.62mm_Socket_LongPads
U4: 74LS32; DIP-14_W7.62mm_Socket_LongPads

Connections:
ALU_CTRL_0: J5.1, U1.8 (A0)
ALU_CTRL_1: J5.2, U1.7 (A1)
ALU_CTRL_2: J5.3, U1.6 (A2)
ALU_CTRL_3: J5.4, U1.5 (A3)
ALU_Carry_in: J2.2, U4.3
CYC_{EN}: J8.2, U1.16 (I/O6), U4.9, U4.10
FLAGS_CARRY: J4.1, U3.5
GND: C1.2, C2.2, C3.2, C4.2, D1.1 (K), D2.1 (K), D3.1 (K), H1.1, H2.1, H3.1, H4.1, J1.2, J4.2, J7.2, U1.1 (A7), U1.2 (A6), U1.3 (A5), U1.4 (A4), U1.12 (GND), U1.18 (*CE), U1.19 (A10), U1.20 (*OE), U1.22 (A9), U1.23 (A8), U2.7 (GND), U3.7 (GND), U4.7 (GND)
LFT_{SEL}: J8.3, U1.17 (I/O7), U4.4, U4.5
M_OUT: J2.1, U1.14 (I/O4)
unnamed: D1.2 (A), R1.2
unnamed: D2.2 (A), R2.2
unnamed: D3.2 (A), R3.2
unnamed: R1.1, U4.6
unnamed: R2.1, U4.8
unnamed: R3.1, U4.11
unnamed: U2.1, U3.4
unnamed: U2.3, U4.1
unnamed: U2.5, U3.6
unnamed: U2.6, U4.2
unnamed: U2.8, U3.3
unnamed: U2.9, U3.2
SH_{EN}: J8.1, U1.15 (I/O5), U4.12, U4.13
S_0: J3.4, U1.9 (I/O0), U2.2, U2.4, U2.10
S_1: J3.3, U1.10 (I/O1)
S_2: J3.2, U1.11 (I/O2)
S_3: J3.1, U1.13 (I/O3), U3.1
VCC: C1.1, C2.1, C3.1, C4.1, J1.1, J7.1, U1.21 (*WE), U1.24 (VCC), U2.12, U2.13, U2.14 (VCC), U3.9, U3.11, U3.13, U3.14 (VCC), U4.14 (VCC)

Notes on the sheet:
Mounting holes


Board: 2 copper layers, 100.0 x 100.0 mm, 25 parts (0 on the bottom side), 28 nets.

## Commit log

2024-06-12 Added MR, started the assembler,
    updated the instruction format
    added problems
2024-06-13 alu
    added a working alu to logisim, including the 74xx circuit
2024-06-14 added eeprom programmer
    [Microcode.xlsx, Microcode1.xlsx]
2024-06-15 fixed some python bugs
    [Microcode.xlsx]
2024-06-15 rewrote the python code
    [Microcode.xlsx]
2024-06-15 solved the logic problem
    [Microcode.xlsx, Microcode1.xlsx]
2024-06-16 added JMP, fixed conditions
    [Microcode.xlsx]
2024-06-18 changed the instruction
    reduced control logic to 3 eeproms, opcode is now 4 bits, added Vout for different jmp conditions, added special addressing mode for different operations
    [Microcode.xlsx]
2024-06-22 fixed carry problem, added conditional jumps
    [Microcode.xlsx]
2024-06-22 fixed some directories
    [Microcode.xlsx, Microcode1.xlsx]
2024-06-22 started assembler
2024-08-15 added shr
    [Microcode.xlsx]
2024-08-16 fixed alu
    changed the alu inputs, need to fix the microcode in the xlsx file, also added the alu diagram in the draw.io file
    [Microcode.xlsx]
2024-08-17 alu fixed
    fixed some instructions, more to come
    [Microcode.xlsx]
2024-08-18 more instruction, fixed alu
    [Microcode.xlsx]
2024-08-19 added more instructions
    [Microcode.xlsx]
2024-08-20 added more instruction
    [Microcode.xlsx]
2024-08-20 Alternate Instruction Update
    address mode reduced from 3 bits to 2,
    added alternate mode for SHR, RRC, SUB, any possibly more
    [Microcode.xlsx]
2024-08-23 chore: Update assembler to process labels and origins
2024-08-24 Assembler
    Last steps on the assembler
    [Instructions.xlsx, Microcode.xlsx]
2024-08-25 finished the assembler and the transition to 5bit opcode
    [Instructions.xlsx, Microcode.xlsx]
2024-08-25 more instructions, small fix for the assembler
    now the assembler will output the file the same directory as the input file
2024-08-26 fixed some instructions, added highlight for neovim
    first try with kicad
    [Instructions.xlsx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]
2024-09-19 some cleaning
    [Instructions.xlsx, Microcode.xlsx, SH8.kicad_pcb]
2024-09-26 added kicad schematics and pcb's
    [Instruction_Register.kicad_pcb, Instruction_Register.kicad_sch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]
2024-10-02 finished registier file boards
    [Program_Counter.kicad_pcb, Program_Counter.kicad_sch, Register.kicad_pcb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]
2024-10-05 added con_ctrl board mdr_mar
    [Condition_Control.kicad_pcb, Condition_Control.kicad_sch, Instruction_Register.kicad_pcb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]
2024-10-16 added more boards, added pcb standarts
    [ALU_Extra.kicad_pcb, ALU_Extra.kicad_sch, ALU_FLAGS_CALC.kicad_pcb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]
2024-10-19 created standarts for PCB's
    [Condition_Control.kicad_pcb, Register.kicad_pcb, Register.kicad_sch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]
